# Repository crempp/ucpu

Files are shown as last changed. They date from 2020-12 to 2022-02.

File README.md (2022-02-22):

# uCPU

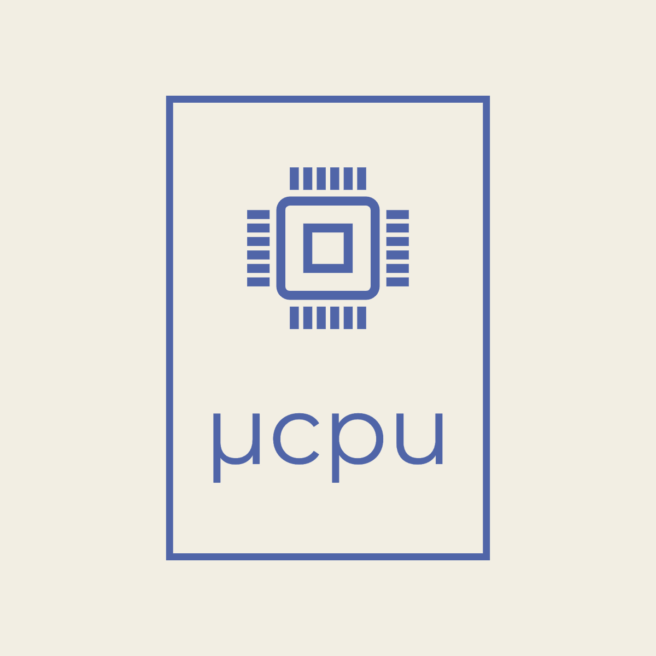
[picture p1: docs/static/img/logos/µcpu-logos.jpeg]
ucpu Logo


This is a 16bit pipelined CPU designed on a breadboard and produced in modular component boards.

My objective in this project is to learn electronics, CPU design and build a fully functional CPU that can be updated, added to and further developed easily.

The CPU is designed around
* four general purpose 16 bit registers
* four 16 bit address registers
* ALU supporting addition, subtraction, shift and bitwise operations
* piplined instructions
* banked memory with a base of 64k, expandable to about 1.5 megabytes (max TBD)

## Documentation

Documentation is located [here](https://crempp.github.io/ucpu)

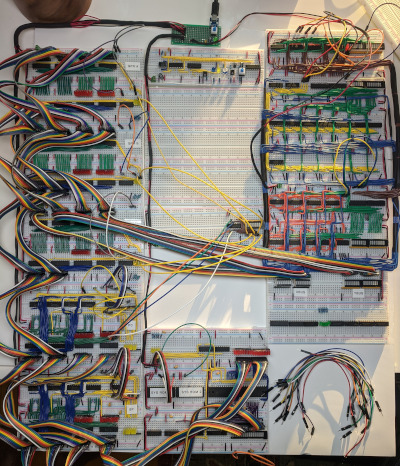
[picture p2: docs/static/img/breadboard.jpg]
Early version of the CPU on breadboards


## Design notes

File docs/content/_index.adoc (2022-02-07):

---
type: docs
draft: false
---

== The µCPU

[.right.text-center]
****
ucpu
****

This is a 16bit pipelined CPU built to be used for experimentation, programming and fun. The CPU is was designed on a breadboard and produced on PCBs in modular architecture utilizing a flexible backplane for expansion and upgrades.

The objective of the µCPU project is to learn electronics, CPU design and build a fully functional CPU that can be updated, added to and further developed easily.

The completed project will include 32 Kb ROM, 32 Kb RAM, a pipelined core, serial port, cartridge support,  VGA compatible video, stereo multi voice sound and more.

== Architecture

[.right.text-center]
****
.Early version of the CPU on breadboards
Early
****

The CPU is being targeted at approximately the PC AT (286) level or Super Nintendo

* Four general purpose 16 bit registers (A, B, C, D)
* Four 16 bit address registers (PC, SP, SI, DI)
* ALU supporting addition, subtraction, shift and bitwise operations
* Pipelined instructions
* Clock runs at 4Mhz
* Banked memory with a base of 32 Kb ROM and 32 Kb RAM, expandable to  304 Kb RAM
* 4 I/O ports for testing and expansion
* Serial port
* 64k Video memory supporting
    * 320×200 in 256 colors
    * 640x350 in 4 (or 16???) colors
* Sprite and effect processing (details TBD)
* Stereo multi-voice sound (details TBD)
* A custom bootable OS
* A BASIC interpreter (ROM)
* Drive support (SD interface to start with)
* Cartridge support (ROMs)

After the CPU is working I may add

* DMA
* ... more?

****
.CPU Architecture
[link=./img/CPUArchitecture.svg,window="_blank"]
CPU Architecture
****

== Schematics

* GPR (rev 1.3) [link:/ucpu/img/schematics/GPRModule.pdf[PDF, window="_blank"]] [link:/ucpu/img/schematics/GPRModule.svg[SVG, window="_blank"]] [link:/ucpu/img/schematics/GPRModule.png[PNG, window="_blank"]]
* Address Register (rev 1.2) [link:/ucpu/img/schematics/AddressRegisterModule.pdf[PDF, window="_blank"]] [link:/ucpu/img/schematics/AddressRegisterModule.svg[SVG, window="_blank"]] [link:/ucpu/img/schematics/AddressRegisterModule.png[PNG, window="_blank"]]
* ALU (rev 1.0) [link:/ucpu/img/schematics/ALUModule.pdf[PDF, window="_blank"]] [link:/ucpu/img/schematics/ALUModule.svg[SVG, window="_blank"]] [link:/ucpu/img/schematics/ALUModule.png[PNG, window="_blank"]]
* Backplane (rev 1.0)[link:/ucpu/img/schematics/Backplane.pdf[PDF, window="_blank"]] [link:/ucpu/img/schematics/Backplane.svg[SVG, window="_blank"]] [link:/ucpu/img/schematics/Backplane.png[PNG, window="_blank"]]
* Memory (rev 1.0)[link:/ucpu/img/schematics/MemoryModule.pdf[PDF, window="_blank"]] [link:/ucpu/img/schematics/MemoryModule.svg[SVG, window="_blank"]] [link:/ucpu/img/schematics/MemoryModule.png[PNG, window="_blank"]]

== BOM

TODO

== Running Documentation

The documentation uses link:https://gohugo.io/[Hugo] as for static site generation.

You'll need go, asciidoctor and hugo
```bash
$ brew install asciidoctor
$ brew install hugo
```

Run

```bash
 $ hugo server --minify
```

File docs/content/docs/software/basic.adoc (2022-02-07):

---
title: "Basic"
date: 2022-02-04T14:46:34-08:00
weight: 2
draft: false
---

== Basic

=== References

* link:http://searle.x10host.com/6502/Simple6502.html[6502 Basic Assembler with source, window="_blank"]

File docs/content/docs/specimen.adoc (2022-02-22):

---
title: "Specimen"
date: 2022-02-04T14:46:34-08:00
weight: 50
draft: true
---
// View this document online at https://asciidoctor.org/docs/asciidoc-writers-guide/
= AsciiDoc Writer's Guide
Dan Allen <https://github.com/mojavelinux[@mojavelinux]>; Sarah White <https://github.com/graphitefriction[@graphitefriction]>
:description: This guide describes the basic structure of an AsciiDoc document, how to create your first AsciiDoc document, how to add other structural elements such as lists, block quotes and source code, and how to convert an AsciiDoc document to HTML, DocBook and PDF.
:keywords: AsciiDoc, Asciidoctor, syntax, reference, learn, how to, writers, authors
:page-description: {description}
:page-keywords: {keywords}
:page-layout: docs
ifndef::env-site[]
:toc: left
:icons: font
:idprefix:
:idseparator: -
:sectanchors:
:source-highlighter: highlightjs
endif::[]
:experimental:
:mdash: &#8212;
:language: asciidoc
:source-language: {language}
:table-caption!:
:example-caption!:
:figure-caption!:
:imagesdir: ../images
// Refs
:url-docs-asciidoc: https://docs.asciidoctor.org/asciidoc/latest/
:url-quickref: {url-docs-asciidoc}syntax-quick-reference/
:user-ref: https://asciidoctor.org/docs/user-manual
:asciidoctor-ref: https://asciidoctor.org/
:asciidoctor-gem-ref: https://rubygems.org/gems/asciidoctor
:uri-install: https://asciidoctor.org/docs/install-toolchain/
:fopub-doc-ref: https://github.com/asciidoctor/asciidoctor-fopub#readme
:docs-ref: https://asciidoctor.org/docs
:gist-ref: https://gist.github.com
:publican-ref: https://fedorahosted.org/publican

This guide provides a gentle introduction to AsciiDoc, a _plain text_ documentation *syntax* and *processor*.
This introduction is intended for anyone who wants to reduce the effort required to write and publish content, whether for technical documentation, articles, web pages or good ol'-fashioned prose.

TIP: If you want to know what AsciiDoc is all about, find the answer in {url-docs-asciidoc}#about-asciidoc[About AsciiDoc].
If you're looking for a concise survey of the AsciiDoc syntax, consult the {url-quickref}[AsciiDoc Syntax Quick Reference].

In this guide, you'll learn:

- The basic structure of an AsciiDoc document
- How to create your first AsciiDoc document
- How to add other structural elements such as lists, block quotes and source code
- How to convert an AsciiDoc document to HTML, DocBook and PDF

In addition to covering the AsciiDoc basics, this guide also suggests a set of conventions to help you create more consistent documents and maximize your writing productivity.

Let's dive in to AsciiDoc!

== Writing in AsciiDoc

The goal of this section is to teach you how to compose your first AsciiDoc document.
Hopefully, when you look back, you'll agree it just makes sense.

Your adventure with AsciiDoc begins in your favorite text editor.

=== It's just text, mate.

Since AsciiDoc syntax is just _plain text_, you can write an AsciiDoc document using _any_ text editor.
You don't need complex word processing programs like Microsoft Word, OpenOffice Writer or Google Docs.
In fact, you _shouldn't_ use these programs because they add cruft to your document (that you can't see) and makes conversion tedious.

TIP: While it's true any text editor will do, I recommend selecting an editor that supports syntax highlighting for AsciiDoc.
The *[red]##c##[green]##o##[purple]##l##[fuchsia]##o##[blue]##r##* brings contrast to the text, making it easier to read.
The highlighting also confirms when you've entered the correct syntax for an inline or block element.

The most popular application for editing plain text on macOS is *TextMate*.
A similar choice on Linux is *GEdit*.
On Windows, stay away from Notepad and Wordpad because they produce plain text which is not cross-platform friendly.
Opt instead for a competent text editor like *Notepad++*.
If you're a programmer (or a writer with an inner geek), you'll likely prefer *Vim*, *Emacs*, or *Sublime Text*, all of which are available cross-platform.
The key feature all these editors share is syntax highlighting for AsciiDoc.

Open up your favorite text editor and get ready to write some AsciiDoc!

=== Content is king!

The bulk of the content in a document is paragraph text.
This is why Asciidoctor doesn't require any special markup or attributes to specify paragraph content.
You can just start typing.

In Asciidoctor, adjacent or consecutive lines of text form a paragraph element.
To start a new paragraph after another element, such as a section title or table, hit the kbd:[RETURN] key twice to insert a blank line, and then continue typing your content.

.Two paragraphs in an AsciiDoc document
[source]
----
This journey begins one late Monday afternoon in Antwerp.
Our team desperately needs coffee, but none of us dare open the office door.

To leave means code dismemberment and certain death.
----

.The two paragraphs rendered using the default (html5) converter and stylesheet (asciidoctor.css)
====
This journey begins one late Monday afternoon in Antwerp.
Our team desperately needs coffee, but none of us dare open the office door.

To leave means code dismemberment and certain death.
====

Just like that, *you're writing in AsciiDoc!*
As you can see, it's just like writing an e-mail.

Save the file with a file extension of `.adoc`.

TIP: If you want to find out how to convert the document to HTML, DocBook or PDF, skip ahead to the section on <<converting-your-document>>.

==== Wrapped text and hard line breaks

Since adjacent lines of text are combined into a single paragraph when Asciidoctor converts a document, that means you can wrap paragraph text or put each sentence or phrase on a separate line.
The line breaks won't appear in the output.

However, if you want the line breaks in a paragraph to be preserved, you can either use a space followed by a plus sign (`{plus}`) or set the `hardbreaks` option on the paragraph.
This results in a visible line break (e.g., `<br>`) following each line.

[source]
.Line breaks preserved using a space followed by the plus sign ({plus})
----
Rubies are red, +
Topazes are blue.
----

====
Rubies are red, +
Topazes are blue.
====

[source]
.Line breaks preserved using the hardbreaks option
----
[%hardbreaks]
Ruby is red.
Java is black.
----

====
[%hardbreaks]
Ruby is red.
Java is black.
====

To preserve line breaks throughout your whole document, add the `hardbreaks` attribute to the document's header.

.Line breaks preserved throughout the document using the hardbreaks attribute
[source]
----
= Line Break Doc Title
:hardbreaks:

Rubies are red,
Topazes are blue.
----

=== Admonitions

There are certain statements you may want to draw attention to by taking them out of the content's flow and labeling them with a priority.
These are called admonitions.
It's rendered style is determined by the assigned label (i.e., value).
Asciidoctor provides five admonition style labels:

* `NOTE`
* `TIP`
* `IMPORTANT`
* `CAUTION`
* `WARNING`

.Caution vs. Warning
[#caution-vs-warning]
****
When choosing the admonition type, you may find yourself getting confused between "caution" and "warning" as these words are often used interchangeably.
Here's a simple rule to help you differentiate the two:

* Use *CAUTION* to advise the reader to _act_ carefully (i.e., exercise care).
* Use *WARNING* to inform the reader of danger, harm, or consequences that exist.

To find a deeper analysis, see https://www.differencebetween.com/difference-between-caution-and-vs-warning/.
****

When you want to call attention to a single paragraph, start the first line of the paragraph with the label you want to use.
The label must be uppercase and followed by a colon (`:`).

.Admonition paragraph syntax
[source]
----
WARNING: Wolpertingers are known to nest in server racks. <1> <2>
Enter at your own risk.
----
<1> The label must be uppercase and immediately followed by a colon (`:`).
<2> Separate the first line of the paragraph from the label by a single space.

.Result: Admonition paragraph
====
WARNING: Wolpertingers are known to nest in server racks.
Enter at your own risk.
====

An admonition paragraph is rendered in a callout box with the admonition label--or its corresponding icon--in the gutter.
Icons are enabled by setting the `icons` attribute on the document.

NOTE: Admonitions can also encapsulate any block content, which we'll cover later.

=== Mild punctuation, strong impact

Just as we emphasize certain words and phrases when we speak, we can emphasize them in text by surrounding them with punctuation.
AsciiDoc refers to this markup as _quoted text_.

==== Quoted text

For instance, in an e-mail, you might "`speak`" a word louder by enclosing it in asterisks.

[source]
I can't believe it, we *won*!

As you would expect, the asterisks make the text *won* bold.
You can almost sense the emotion.
This is one example of quoted (i.e., formatted) text.

NOTE: The term "`quote`" is used liberally here to apply to any symbols that surround text in order to apply emphasis or special meaning.

Here are the forms of quoted text that AsciiDoc recognizes:

.Bold, italic, and monospace formatting syntax
[source]
----
bold *constrained* & **un**constrained

italic _constrained_ & __un__constrained

bold italic *_constrained_* & **__un__**constrained

monospace `constrained` & ``un``constrained

monospace bold `*constrained*` & ``**un**``constrained

monospace italic `_constrained_` & ``__un__``constrained

monospace bold italic `*_constrained_*` & ``**__un__**``constrained
----

When you want to quote text (e.g., place emphasis) somewhere other than at the boundaries of a word, you need to double up the punctuation.

.Result: Bold, italic, and monospace text
====
bold *constrained* & **un**constrained

italic _constrained_ & __un__constrained

bold italic *_constrained_* & **__un__**constrained

monospace `constrained` & ``un``constrained

monospace bold `*constrained*` & ``**un**``constrained

monospace italic `_constrained_` & ``__un__``constrained

monospace bold italic `*_constrained_*` & ``**__un__**``constrained
====

Any quoted text can be prefixed with an attribute list.
The first positional attribute is treated as a role.
The role can be used to apply custom styling to the text.
For instance:

[source]
Type the word [.userinput]#asciidoc# into the search bar.

When converting to HTML, the word "`asciidoc`" is wrapped in `<span>` tags and the role is used as the element's CSS class:

[source,xml]
<span class="userinput">asciidoc</span>

You can apply styles to the text using CSS.

You may not always want these substitutions to take place.
In those cases, you'll need to use markup to escape the text.

==== Preventing substitution

If you are getting quoted text behavior where you don't want it, you can use a backslash or a passthrough macro to prevent it.

Asciidoctor provides several approaches for preventing substitutions.

.Backslash escaping
To prevent punctuation from being interpreted as formatting markup, precede it with a backslash (`\`).
If the formatting punctuation begins with two characters (e.g., `+__+`), you need to precede it with two backslashes (`+\\+`).
This is also how you can prevent character and attribute references from substitution.
When your document is processed, the backslash is removed so it doesn't display in your output.

[source]
----
\*Stars* will appear as *Stars*, not as bold text.

\&sect; will appear as an entity, not the &sect; symbol.

\\__func__ will appear as __func__, not as emphasized text.

\{two-semicolons} will appear {two-semicolons}, not resolved as ;;.
----

Asciidoctor supports several forms of the passthrough macro.

inline pass macro:: An inline macro named `pass` that can be used to passthrough content.
Supports an optional set of substitutions.
+
[source]
----
pass:[content like #{variable} passed directly to the output] followed by normal content.

content with only select substitutions applied: pass:c,a[__<{email}>__]
----

single and double plus:: A special syntax for preventing text from being formatted.
Only escapes special characters for compliance with the output format and doesn't support explicit substitutions.

triple plus:: A special syntax for designating passthrough content.
Does not apply any substitutions (equivalent to the inline pass macro) and doesn't support explicit substitutions.

double dollar (deprecated):: A deprecated special syntax for designating passthrough content.
Like the triple plus, does not apply any substitutions and doesn't support explicit substitutions.

CAUTION: Asciidoctor does not implement the block pass macro.
Instead, you should use a <<pass-blocks,pass block>>.

==== Inline pass macro and explicit substitutions

To exclude a phrase from substitutions and disable escaping of special characters, enclose it in the inline pass macro.
For example, here's one way to format text as underline when generating HTML from AsciiDoc:

[source]
----
The text pass:[<u>underline me</u>] is underlined.
----

====
The text pass:[<u>underline me</u>] is underlined.
====

If you want to enable ad-hoc `quotes` substitution, then assign the `macros` value to `subs` and use the inline pass macro.

------
[subs=+macros] <1>
----
I better not contain *bold* or _italic_ text.
pass:quotes[But I should contain *bold* text.] <2>
----
------
<1> `macros` is assigned to `subs`, which allows any macros within the block to be processed.
<2> The pass macro is assigned the `quotes` value. Text within the square brackets will be formatted.

The inline pass macro does introduce additional markup into the source code that could make it invalid in raw form.
However, the output it produces will be valid when viewed in a viewer (HTML, PDF, etc.).

====
[subs=+macros]
----
I better not contain *bold* or _italic_ text.
pass:quotes[But I should contain *bold* text.]
----
====

The inline pass macro also accepts shorthand values for specifying substitutions.

* `c` = special characters
* `q` = quotes
* `a` = attributes
* `r` = replacements
* `m` = macros
* `p` = post replacements

For example, the quotes text substitution value is assigned in the inline passthrough macro below:

[source]
----
The text pass:q[<u>underline *me*</u>] is underlined and the word "`me`" is bold.
----

====
The text pass:q[<u>underline *me*</u>] is underlined and the word "`me`" is bold.
====

==== Triple plus passthrough

The triple-plus passthrough works much the same way as the pass macro.
To exclude content from substitutions, enclose it in triple pluses (pass:[+++]).

 +++content passed directly to the output+++ followed by normal content.

The triple-plus macro is often used to output custom HTML or XML.

[source]
----
The text +++<u>underline me</u>+++ is underlined.
----

====
The text +++<u>underline me</u>+++ is underlined.
====

.Single plus enclosure

To exclude a phrase from substitutions, enclose it in plus signs (`+`).

[source]
----
This +*literal*+ will appear as *literal*.
----

==== Replacements

AsciiDoc also recognizes textual representations of symbols, arrows and dashes.

[cols="2,^1l,^1l,^1,2"]
.Textual symbol replacements
|===
|Name |Syntax |Unicode Replacement |Rendered |Notes

|Copyright
|(C)
|&#169;
|(C)
|

|Registered
|(R)
|&#174;
|(R)
|

|Trademark
|(TM)
|&#8482;
|(TM)
|

|Em dash
|--
|&#8212;
|{empty}--{empty}
|Only replaced if between two word characters, between a word character and a line boundary, or flanked by spaces.

When flanked by space characters (e.g., `+a -- b+`), the normal spaces are replaced by thin spaces (\&#8201;).

|Ellipsis
|...
|&#8230;
|...
|

|Single right arrow
|->
|&#8594;
|->
|

|Double right arrow
|=>
|&#8658;
|=>
|

|Single left arrow
|<-
|&#8592;
|<-
|

|Double left arrow
|<=
|&#8656;
|<=
|

|Typographic apostrophe
|Sam's
|Sam&#8217;s
|Sam's
|The typewriter apostrophe is replaced with the typographic (aka curly) apostrophe.
|===

This mild punctuation does not take away from the readability of the text.
In fact, you could argue that it makes the text easier to read.
What's important is that these are conventions with which you are likely already familiar.

Punctuation is used in AsciiDoc to create another very common type of element in documents, _lists!_

=== Lists, lists, lists

There are three types of lists supported in AsciiDoc:

. Unordered
. Ordered
. Description

Unordered and ordered lists are structurally very similar.
They consist of items that are prefixed by different types of markers (i.e., bullet).
In contrast, description lists--also called variable, labeled, or term-definition lists--are collections of terms that each have their own supporting content.
Unlike unordered and ordered lists, description lists are rarely nested, though they often contain the former.

Let's explore each type of list, then mix them together.
We'll also look at how to put complex content inside a list item.

==== Lists of things

If you were to create a list in an e-mail, how would you do it?
Chances are, you'd mark list items using the same characters that Asciidoctor uses to find list items.

In the example below, each list item is marked using an asterisk (`{asterisk}`), the AsciiDoc syntax specifying an unordered list item.

[source]
----
* Edgar Allan Poe
* Sheri S. Tepper
* Bill Bryson
----

A list item's first line of text must be offset from the marker (`{asterisk}`) by at least one space.
If you prefer, you can indent list items.
Blank lines are required before and after a list.
Additionally, blank lines are permitted, but not required, between list items.

.Rendered unordered list
====
* Edgar Allan Poe
* Sheri S. Tepper
* Bill Bryson
====

You can add a title to a list by prefixing the title with a period (`.`).

[source]
----
.Kizmet's Favorite Authors
* Edgar Allan Poe
* Sheri S. Tepper
* Bill Bryson
----

.Rendered unordered list with a title
====
.Kizmet's Favorite Authors
* Edgar Allan Poe
* Sheri S. Tepper
* Bill Bryson
====

Was your instinct to use a hyphen (`-`) instead of an asterisk to mark list items?
Guess what?
That works too!

[source]
----
- Edgar Allan Poe
- Sheri S. Tepper
- Bill Bryson
----

You should reserve the hyphen for lists that only have a single level because the hyphen marker (`-`) doesn't work for nested lists.
Now that we've mentioned nested lists, let's go to the next section and learn how to create lists with multiple levels.

[#separating-lists]
.Separating Lists
****
If you have adjacent lists, they have the tendency to want to fuse together.
To force lists apart, insert a line comment (`//`) surrounded by blank lines between the two lists.
Here's an example, where the `-` text in the line comment indicates the line serves as an "`end of list`" marker:

[source]
----
* Apples
* Oranges

//-

* Walnuts
* Almonds
----
****

To nest an item, just add another asterisk (`{asterisk}`) to the marker, and another for each subsequent level.

[source]
----
.Possible DefOps manual locations
* West wood maze
** Maze heart
*** Reflection pool
** Secret exit
* Untracked file in git repository
----

.Rendered nested, unordered list
====
.Possible DefOps manual locations
* West wood maze
** Maze heart
*** Reflection pool
** Secret exit
* Untracked file in git repository
====

In Asciidoctor 1.5.7 and earlier you could only have up to six (6) levels of nesting (assuming one level uses the hyphen marker).

Since Asciidoctor 1.5.8, you can nest unordered lists to any depth.
Keep in mind, however, that some interfaces will begin flattening lists after a certain depth.
GitHub starts flattening list after 10 levels of nesting.

[source]
----
* level 1
** level 2
*** level 3
**** level 4
***** level 5
* level 1
----

====
* level 1
** level 2
*** level 3
**** level 4
***** level 5
* level 1
====

While it would seem as though the number of asterisks represents the nesting level, that's not how depth is determined.
A new level is created for each unique marker encountered.
However, it's much more intuitive to follow the convention that the number of asterisks equals the level of nesting.
After all, we're shooting for plain text markup that is readable _as is_.

==== Ordering the things

Sometimes, we need to number the items in a list.
Instinct might tell you to prefix each item with a number, like in this next list:

[source]
----
1. Protons
2. Electrons
3. Neutrons
----

The above works, but
since the numbering is obvious, the AsciiDoc processor will insert the numbers for you if you omit them:

[source]
----
. Protons
. Electrons
. Neutrons
----

====
. Protons
. Electrons
. Neutrons
====

If you decide to use number for your ordered list, you have to keep them sequential.
This differs from other lightweight markup languages.
It's one way to adjust the numbering offset of a list.
For instance, you can type:

[source]
----
4. Step four
5. Step five
6. Step six
----

However, in general the best practice is to use the `start` attribute to configure this sort of thing:

[source]
----
[start=4]
. Step four
. Step five
. Step six
----

To present the items in reverse order, add the `reversed` option:

[source]
----
[%reversed]
.Parts of an atom
. Protons
. Electrons
. Neutrons
----

====
[%reversed]
.Parts of an atom
. Protons
. Electrons
. Neutrons
====

You can give a list a title by prefixing the line with a dot immediately followed by the text (without leaving any space after the dot).

Here's an example of a list with a title:

[source]
----
.Parts of an atom
. Protons
. Electrons
. Neutrons
----

====
.Parts of an atom
. Protons
. Electrons
. Neutrons
====

You create a nested item by using one or more dots in front of each the item.

[source]
----
. Step 1
. Step 2
.. Step 2a
.. Step 2b
. Step 3
----

AsciiDoc selects a different number scheme for each level of nesting.
Here's how the previous list renders:

.A nested ordered list
====
. Step 1
. Step 2
.. Step 2a
.. Step 2b
. Step 3
====

[TIP]
====
Like with the asterisks in an unordered list, the number of dots in an ordered list doesn't represent the nesting level.
However, it's much more intuitive to follow this convention:

[quote]
# of dots = level of nesting

Again, we are shooting for plain text markup that is readable _as is_.
====

Asciidoctor works hard to infer the relationships between the items that are most intuitive to us humans.
Here's an example of nesting an unordered list inside of an ordered list:

[source]
----
. Linux
* Fedora
* Ubuntu
* Slackware
. BSD
* FreeBSD
* NetBSD
----

====
. Linux
* Fedora
* Ubuntu
* Slackware
. BSD
* FreeBSD
* NetBSD
====

You can spread the items out and indent the nested lists if that makes it more readable for you:

[source]
----
. Linux

  * Fedora
  * Ubuntu
  * Slackware

. BSD

  * FreeBSD
  * NetBSD
----

The following table shows the numbering scheme used by default for each nesting level.

.Ordered list numbering scheme by level
[cols="^2,3,3,4"]
|===
|Level |Numbering Scheme |Examples |CSS class (HTML converter)

|1
|Arabic
|1. 2. 3.
|arabic

|2
|Lower Alpha
|a. b. c.
|loweralpha

|3
|Lower Roman
|i. ii. iii.
|lowerroman

|4
|Upper Alpha
|A. B. C.
|upperalpha

|5
|Upper Roman
|I. II. III.
|upperroman
|===

You can override the number scheme for any level by setting its style (the first positional entry in a block attribute list).
You can also set the starting number using the `start` attribute:

[source]
----
[lowerroman, start=5]
. Five
. Six
[loweralpha]
.. a
.. b
.. c
. Seven
----

==== Description lists

A description list (often abbreviate as dlist) is useful when you need to include a description or supporting text for one or more terms.
Each item in a description list consists of:

* one or more terms
* a separator following each term (typically a double colon, `::`)
* at least one space or endline
* the supporting content (either text, attached blocks, or both)

Here's an example of a description list that identifies parts of a computer:

[source]
----
CPU:: The brain of the computer.
Hard drive:: Permanent storage for operating system and/or user files.
RAM:: Temporarily stores information the CPU uses during operation.
Keyboard:: Used to enter text or control items on the screen.
Mouse:: Used to point to and select items on your computer screen.
Monitor:: Displays information in visual form using text and graphics.
----

By default, the content of each item is displayed below the description when rendered.
Here's a preview of how this list is rendered:

.A basic description list
====
CPU:: The brain of the computer.
Hard drive:: Permanent storage for operating system and/or user files.
RAM:: Temporarily stores information the CPU uses during operation.
Keyboard:: Used to enter text or control items on the screen.
Mouse:: Used to point to and select items on your computer screen.
Monitor:: Displays information in visual form using text and graphics.
====

If you want the description and content to appear on the same line, add the horizontal style to the list.

[source]
----
[horizontal]
CPU:: The brain of the computer.
Hard drive:: Permanent storage for operating system and/or user files.
RAM:: Temporarily stores information the CPU uses during operation.
----

====
[horizontal]
CPU:: The brain of the computer.
Hard drive:: Permanent storage for operating system and/or user files.
RAM:: Temporarily stores information the CPU uses during operation.
====

The content of a description list can be any AsciiDoc element.
For instance, we could rewrite the grocery list from above so that each aisle is a description rather than a parent outline list item.

[source]
----
Dairy::
* Milk
* Eggs
Bakery::
* Bread
Produce::
* Bananas
----

====
Dairy::
* Milk
* Eggs
Bakery::
* Bread
Produce::
* Bananas
====

Description lists are quite lenient about whitespace, so you can spread the items out and even indent the content if that makes it more readable for you:

[source]
----
Dairy::

  * Milk
  * Eggs

Bakery::

  * Bread

Produce::

  * Bananas
----

==== Hybrid lists

[#three-hybrid]
Finally, you can mix and match the three list types within a single hybrid list.
Asciidoctor works hard to infer the relationships between the items that are most intuitive to us humans.

Here's a list that mixes description, ordered, and unordered list items:

[source]
----
Operating Systems::
  Linux:::
    . Fedora
      * Desktop
    . Ubuntu
      * Desktop
      * Server
  BSD:::
    . FreeBSD
    . NetBSD

Cloud Providers::
  PaaS:::
    . OpenShift
    . CloudBees
  IaaS:::
    . Amazon EC2
    . Rackspace
----

Here's how the list is rendered:

.A hybrid list
====
Operating Systems::
Linux:::
. Fedora
* Desktop
. Ubuntu
* Desktop
* Server
BSD:::
. FreeBSD
. NetBSD

Cloud Providers::
PaaS:::
. OpenShift
. CloudBees
IaaS:::
. Amazon EC2
. Rackspace
====

You can include more complex content in a list item as well.

=== Links and images

AsciiDoc makes it easy to include links, images and other types of media in a document.

==== External links

There's nothing you have to do to make a link to a URL.
Just include the URL in the document and AsciiDoc will turn it into a link.

Asciidoctor recognizes the following common schemes without the help of any markup.

[#schemes]
* http
* https
* ftp
* irc
* mailto
* \email@email.com

You can think of these like implicit macro names (the bare email address being a special case).
Since the URL in the example below begins with a protocol (in this case _https_ followed by a colon), Asciidoctor will automatically turn it into a hyperlink when it is processed.

[source]
----
The homepage for the Asciidoctor Project is https://asciidoctor.org. <1>
----
<1> The trailing period will not get caught up in the link.

To prevent automatic linking of an URL, prepend it with a backslash (`\`).

[source]
----
Once launched, the site will be available at \https://example.org.
----

If you prefer URLs to be shown with the scheme hidden, set the `hide-uri-scheme` attribute in the document's header.

[source]
----
:hide-uri-scheme:

https://asciidoctor.org
----

When the hide-uri-scheme attribute is set, the above URL will render as follows:

[source,xml]
----
<a href="https://asciidoctor.org">asciidoctor.org</a>
----

Note the absence of _https_ inside the `<a>` element.

To attach a URL to text, enclose the text in square brackets at the end of the URL, thus making it an URL macro:

[source]
----
Chat with other Fedora users in the irc://irc.freenode.org/#fedora[Fedora IRC channel].
----

When a URL does not start with one of the <<schemes,common schemes>>, or the URL is not surrounded by word boundaries, you must use the `link` macro.
The `link` macro is a stronger version of a URI macro, which you can think of like an unconstrained macro.
The URL is preceded by `link:` and followed by square brackets.
The square brackets may include optional link text.
The URL is used for the text of the link if link text is not specified.
Prior to 1.5.7, if the `linkattrs` document attribute is set, the text in square brackets is parsed as attributes, which allows a window name or role to be specified.
Since 1.5.7, attributes are parsed automatically if an equal sign is found after a comma (e.g., `[link text,window=_blank]`).

.Anatomy of a link macro
[source]
----
link:url[optional link text, optional target attribute, optional role attribute]
----

Let's consider a case where we need to use the link macro (instead of just a URI macro) to expand a link when it's not adjacent to a word boundary (i.e., unconstrained).

[source]
----
search/link:https://ecosia.org[Ecosia]
----

====
search/link:https://ecosia.org[Ecosia]
====

If we didn't use the `link:` prefix in this case, the URL macro would not be detected by the parser.

==== Target window and role attributes for links

[#link-macro-attributes]
Prior to 1.5.7, Asciidoctor _does not_ parse attributes in the link macro by default.
If you want attributes in the link macro to be parsed, you must set the `linkattrs` document attribute in the header.
Since 1.5.7, this parsing is automatic (and the attribute is not required) if an equal sign is found after a comma.
When attribute parsing is enabled, you can then specify the name of the target window using the `window` attribute.

[source]
----
= Asciidoctor Document Title

Let's view the raw HTML of the link:view-source:asciidoctor.org[Asciidoctor homepage,window=_blank].
----

====
Let's view the raw HTML of the link:view-source:asciidoctor.org[Asciidoctor homepage,window=_blank].
====

Since `_blank` is the most common window name, we've introduced shorthand for it.
Just end the link text with a caret (`+^+`):

[source]
----
Let's view the raw HTML of the link:view-source:asciidoctor.org[Asciidoctor homepage^].
----

CAUTION: If you use the caret syntax more than once in a single paragraph, you may need to escape the first occurrence with a backslash.

When attribute parsing is enabled, you can add a role (i.e., CSS class) to the link.

[source]
----
Chat with other Asciidoctor users on the https://discuss.asciidoctor.org/[*mailing list*^,role=green].
----

====
Chat with other Asciidoctor users on the https://discuss.asciidoctor.org/[*mailing list*^,role=green].
====

TIP: Links with attributes (including the subject and body segments on mailto links) are a feature unique to Asciidoctor.
When they're enabled, you must surround the link text in double quotes if it contains a comma.

==== Links to relative files

If you want to link to an external file relative to the current document, use the `link` macro in front of the file name.

[source]
----
link:protocol.json[Open the JSON file]
----

If your file is an HTML file, you can link directly to a section in the document, append a hash (`#`) followed by the section's ID to the end of the file name.

[source]
----
link:external.html#livereload[LiveReload]
----

For links to relative AsciiDoc documents cross references should be used.

[reftext="Internal Cross References"]
==== Cross references

A link to another location within an AsciiDoc document or between AsciiDoc documents is called a _cross reference_ (also referred to as an _xref_).

In Asciidoctor, the inline xref macro is used to create cross references (also called in-text or page citations) to content elements (sections, blocks, or phrases) that have an ID (regardless of whether that ID is explicit or auto-generated).

You create a cross reference by enclosing the ID of the target block or section (or the path of another document with an optional anchor) in double angled brackets.

.Cross reference using the ID of the target section
[source]
----
The section <<images>> describes how to insert images into your document.
----

.Rendered cross reference using the ID of the target section
====
The section <<images>> describes how to insert images into your document.
====

You can also link to a block or section using the title by referencing its title, referred to as a [.term]_natural cross reference_.
The title must contain at least one space character or contain at least one uppercase letter.
(If you are using Ruby < 2.4, that uppercase letter is restricted to the basic Latin charset).

.Cross reference using a section's title
[source]
----
Refer to <<Internal Cross References>>.
----

.Rendered cross reference using a section's title
====
Refer to <<Internal Cross References>>.
====

Converters usually use the reftext of the target as the default text of the link.
When the document is parsed, attribute references in the reftext are substituted immediately.
When the reftext is displayed, additional reftext substitutions are applied to the text (specialchars, quotes, and replacements).

You can override the reftext of the target by specifying alternative text at the location of the cross reference.
After the ID, add a comma and then enter the custom text you want the cross reference to display.

.Cross reference with custom xreflabel text
[source]
----
Learn how to <<link-macro-attributes,use attributes within the link macro>>.
----

.Rendered cross reference using custom xreflabel text
====
Learn how to <<link-macro-attributes,use attributes within the link macro>>.
====

You can also use the inline xref macro as an alternative to the double angled bracket form.

.Inline xref macro
[source]
----
Learn how to xref:link-macro-attributes[use attributes within the link macro].
----

Cross references can also be used to create a link to a file relative to the current document.
For links to another AsciiDoc document, this is the preferred way.

The trailing hash (`#`) means that you refer to the top of the document.

.Cross reference to the top of a relative AsciiDoc document
[source]
----
Refer to <<document-b.adoc#,Document B>> for more information.
----

.Converted HTML for cross reference to relative AsciiDoc document
[source,html]
----
Refer to <a href="document-b.html">Document B</a> for more information.
----

To link directly to a section in the document, append the section's ID after the hash (`#`).

.Cross reference to a specific section of a relative AsciiDoc document
[source]
----
Refer to <<document-b.adoc#section-b,Section B>> for more information.
----

.Converted HTML for cross reference to section of a relative AsciiDoc document
[source,html]
----
Refer to <a href="document-b.html#section-b">Section B</a> for more information.
----

In both cases, this syntax will also work if you are inside the document you are referring to.
This is useful if you are sharing the same link across multiple documents.

In the link that is created from the inter-document cross reference, the source file extension is replaced with the value of the `outfilesuffix` attribute.
To customize the file extension used in the target of the link, simply change the value of this attribute.

Image references are similar to links since they are also references to URLs or files.
The difference, of course, is that they display the image in the document.

==== Images

To include an image on its own line (i.e., a _block image_), use the `image::` prefix in front of the file name and square brackets after it:

[source]
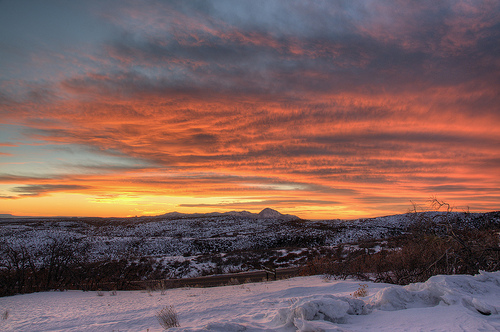
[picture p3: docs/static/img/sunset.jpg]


If you want to specify alt text, include it inside the square brackets:

[source]
Sunset

You can also give the image an id, a title (i.e., caption), set its dimensions (i.e., width and height) and make it a link:

[source]
----
[#img-sunset]
.A mountain sunset
[link=https://www.flickr.com/photos/javh/5448336655]
Sunset
----

The title of a block image is displayed underneath the image when rendered.
Here's a preview:

.A hyperlinked image with caption
====
[#img-sunset]
.A mountain sunset
[link=https://www.flickr.com/photos/javh/5448336655]
Sunset
====

IMPORTANT: Images are resolved relative to the value of the `imagesdir` document attribute, which defaults to an empty value.
The `imagesdir` attribute can be an absolute path, relative path or base URL.
If the image target is a URL or an absolute path, the `imagesdir` prefix is _not_ added.

TIP: You should use the `imagesdir` attribute to avoid hard coding the shared path to your images in every image macro.

If you want to include an image inline, use the `image:` prefix instead (notice there is only one colon):

[source]
Press the Save button.

For inline images, the optional title is displayed as a tooltip.

If paragraphs and lists are the meat of the document, then titles and sections are its bones.
Let's explore how to give structure to our document.

=== Titles, titles, titles

AsciiDoc supports three types of titles:

. Document title
. Section title
. Block title

All titles are optional in AsciiDoc.
This section will define each title type and explain how and when to use them.

==== Document title

Just as every e-mail has a subject, every document (typically) has a title.
The title goes at the top of an AsciiDoc document.

TIP: A document title is an _optional_ feature of an AsciiDoc document.

To create a document title, begin the first line of the document with one equal sign followed by at least one space (``= ``), then the text of the title.
This syntax is the simplest (and thus recommended) way to declare a document title.

Here's an example of a document title followed by an abbreviated paragraph:

[source]
----
= Lightweight Markup Languages

According to Wikipedia...
----

The document title is part of the document header.
So, what else can go in the header?
Good question.

===== The document header

Notice the blank line between the title line and the first line of content in the previous example.
This blank line separates the document header from the document body (in this case a paragraph).
The document title is part of the document header.
In all, the document header contains the title, author, revision information and document-wide attributes.

CAUTION: If the title line is not offset by a blank line, it gets interpreted as a section title, which we'll discuss later.

Your document now has a title, but what about an author?
Just as every e-mail has a sender, every document must surely have an author.
Let's see how to add additional information to the header, including an author.

There are two optional lines of text you can add immediately below the document title for defining common document attributes:

Line 1:: Author name and an optional e-mail address
Line 2:: An optional revision, a date and an optional remark

Let's add these lines to our document:

[source]
----
= Lightweight Markup Languages
Doc Writer <doc.writer@asciidoc.org>
v1.0, 2012-01-01

According to Wikipedia...
----

The header now contains a document title, an author, a revision number, and a date.
This information will typically be displayed as a formatted header at the top of the output document.

NOTE: The header, including the document title, is _not required_.
If absent, the AsciiDoc processor will happily convert whatever content is present.
The header is only used when generating a full document.
It's excluded from the output of an embedded document.

The document header can also be used to define attributes.

==== Document attributes

Attributes are one of the features that sets AsciiDoc apart from other lightweight markup languages.
You can use attributes to toggle features or to store reusable or replacement content.

Most often, attributes are defined in the document header.
There are scenarios where they can be defined inline, but we'll focus on the more common usage.

An attribute entry consists of a name surrounded by colons at the beginning of the line followed by at least one space, then the content.
The content is optional.

Here's an example of an attribute that holds the version of an application:

[source]
----
= User Guide
Doc Writer <doc.writer@asciidoc.org>
2012-01-01
:appversion: 1.0.0
----

IMPORTANT: There should be no blank lines between the first attribute entry and the rest of the header.

Now you can refer to this attribute anywhere in the document (where attribute substitution is performed) by surrounding the name in curly braces:

[source]
The current version of the application is {appversion}.

Attributes are also commonly used to store URLs, which can get quite lengthy.
Here's an example:

[source]
----
:fedpkg: https://apps.fedoraproject.org/packages/rubygem-asciidoctor
----

Here's the attribute in use:

[source]
Information about the Asciidoctor package for Fedora can found at {fedpkg}.

Document attributes can also be used to toggle settings or set configuration variables that control the output generated by the AsciiDoc processor.

For example, to include a table of contents in your document, you can define the `toc` attribute:

[source]
----
:toc:
----

To undefine an attribute, place a `!` at the end of the name:

[source]
----
:linkcss!:
----

You can also set the base path to images (default: _empty_), icons (default: `./images/icons`), stylesheets (default: `./stylesheets`) and JavaScript files (default: `./javascripts`):

[source]
----
:imagesdir: ./images
:iconsdir: ./icons
:stylesdir: ./styles
:scriptsdir: ./js
----

TIP: Attribute values can also be set and overridden when invoking the AsciiDoc processor.
We'll explore that feature later.

When you find yourself typing the same text repeatedly, or text that often needs to be updated, consider assigning it to a document attribute and use that instead.

As your document grows, you'll want to break the content into sections, like in this guide.
That's accomplished using section titles.

==== Section titles

Sections partition the document into a content hierarchy.
In AsciiDoc, sections are defined using section titles.

A section title uses the same syntax as a document title, except the line may begin with two to six equal signs instead of just a single equal sign.
The number of equal signs represents the nesting level (using a 0-based index).

Here are all the section levels permitted in an AsciiDoc document (for an article doctype, the default), shown below the document title:

[source]
----
= Document Title (Level 0)

== Level 1 Section

=== Level 2 Section

==== Level 3 Section

===== Level 4 Section

====== Level 5 Section

== Another Level 1 Section
----

NOTE: When the document is converted to HTML 5 (using the built-in `html5` backend), each section title becomes a heading element where the heading level matches the number of equal signs.
For example, a level 1 section (2 equal signs) maps to an `<h2>` element.

Section levels cannot be chosen arbitrarily.
There are two rules you must follow:

. A document can only have multiple level 0 sections if the `doctype` is set to `book`.footnote:[The default doctype is `article`, which only allows one level 0 section (i.e., the document title).]
. Section levels cannot be skipped when nesting sections

For example, the following syntax is illegal:

[source]
----
= Document Title

= Illegal Level 0 Section (violates rule #1)

== First Section

==== Illegal Nested Section (violates rule #2)
----

Content above the first section (after the document title) is part of the preamble.
Once the first section is reached, content is associated with the section that precedes it:

[source]
----
== First Section

Content of first section

=== Nested Section

Content of nested section

== Second Section

Content of second section
----

TIP: In addition to the equals marker used for defining single-line section titles, Asciidoctor recognizes the hash symbol (`#`) from Markdown.
That means the outline of a Markdown document will convert just fine as an AsciiDoc document.

To have the processor auto-number the sections, define the `sectnums` attribute in the document header:

[source]
----
:sectnums:
----

You can also use this attribute entry above any section title in the document to toggle the auto-numbering setting.
When you want to turn off the numbering, add an exclamation point to the end of the attribute name:

[source]
----
:sectnums!:

== Unnumbered Section
----

===== Preamble

Content between the document title and the first section is called the preamble.
If a document title is not present, this content is not wrapped in a preamble section.

[source]
----
= Document Title

preamble

another preamble paragraph

== First Section
----

TIP: When using the default Asciidoctor stylesheet, this preamble is rendered in the style of a lead (i.e., larger font).

You can also assign titles to individual elements.

==== Block titles

You can assign a title to any paragraph, list or delimited block element.
The title is used as the element's caption.
In most cases, the title is displayed immediately above the content.
If the content is a figure or image, the title is displayed below the content.

A block title is defined on a line above the element.
The line must begin with a dot (`.`) and be followed immediately by the title text with no spaces in between.

Here's an example of a list with a title:

[source]
----
.TODO list
- Learn the AsciiDoc syntax
- Install AsciiDoc
- Write my document in AsciiDoc
----

Speaking of block titles, let's dig into blocks and discover which types of blocks AsciiDoc supports.

== Building blocks in AsciiDoc

AsciiDoc provides a nice set of components for including non-paragraph text--such as block quotes, source code listings, sidebars and tables--in your document.
These components are referred to as _delimited blocks_ because they are surrounded by delimiter lines.

=== Delimited blocks

You've already seen many examples of the listing block (i.e., code block), which is surrounded by lines with four or more hyphens.

[source]
....
----
This is an example of a _listing block_.
The content inside is displayed as <pre> text.
----
....

Within the boundaries of a delimited block, you can enter any content or blank lines.
The block doesn't end until the ending delimiter is found.
The delimiters around the block determine the type of block, how the content is processed and converted and what elements are used to wrap the content in the output.

Here's how the block above appears when converted to HTML and viewed in a browser:

....
This is an example of a _listing block_.
The content inside is displayed as <pre> text.
....

Here's the HTML source that is generated:

[source,html]
----
<div class="listingblock">
  <div class="content monospaced">
    <pre>This is an example of a _listing block_.
The content inside is displayed as &lt;pre&gt; text.</pre>
  </div>
</div>
----

You should notice a few things about how the content is processed:

* the HTML tag `<pre>` is escaped
* the endlines are preserved
* the phrase "`listing block`" is not italicized, despite having underscores around it.

Each type of block is processed according to its purpose.
Literal blocks don't receive the full set of substitutions normally applied to a paragraph.
Since a listing block is typically used for source code, substitutions are not desirable.

The following table identifies the delimited blocks that AsciiDoc provides by default, their purpose and what substitutions are performed on its content.

[cols="1,1l,1,1"]
|===
|Name (Style) |Line delimiter |Purpose |Substitutions

|comment
|////
|Private notes that are not displayed in the output
|none

|example
|====
|Designates example content or defines an admonition block
|normal

|literal
|....
|Output text to be displayed exactly as entered
|verbatim

|listing, source
|----
|Source code or keyboard input to be displayed as entered
|verbatim

|open
|--
|Anonymous block that can act as any other block (except _pass_ or _table_)
|varies

|pass
|++++
|Raw text to be passed through unprocessed
|none

|quote, verse
|____
|A quotation or verse with optional attribution
|normal

|sidebar
|****
|Aside text displayed outside the flow of the document
|normal

|table
|\|===
|Used to display tabular content or advanced layouts
|varies
|===

IMPORTANT: AsciiDoc allows delimited lines to be longer than 4 characters.
*Don't do it.*
Maintaining long delimiter lines is a _colossal_ waste of time, not to mention arbitrary and error prone.
Use the minimum line length required to create a delimited block and _move on_ to drafting the content.
The reader will never see the long delimiters anyway since they are not carried over to the output.

This table shows the substitutions performed by each substitution group referenced in the previous table.

|===
|Group / Substitution |Normal |Verbatim |None

h|Special chars
|Yes
|Yes
|No

h|Callouts
|No
|Yes
|No

h|Quotes
|Yes
|No
|No

h|Attributes
|Yes
|No
|No

h|Replacements
|Yes
|No
|No

h|Macros
|Yes
|No
|No

h|Post replacements
|Yes
|No
|No
|===

In order to apply normal substitutions to an attribute value, surround it with single quotes.
There are two exceptions to this behavior: At the moment normal substitutions are not applied to
the `options` and `title` attribute values.

You can control how blocks are displayed using block metadata.

=== Block metadata

Metadata can be assigned to any block.
There are several types of metadata:

* Title
* Id (i.e., anchor)
* Style (first unnamed block attribute)
* Named block attributes

Here's an example of a quote block that includes all types of metadata:

[source]
----
.Gettysburg Address
[[gettysburg]]
[quote, Abraham Lincoln, Address delivered at the dedication of the Cemetery at Gettysburg]
____
Four score and seven years ago our fathers brought forth
on this continent a new nation...

Now we are engaged in a great civil war, testing whether
that nation, or any nation so conceived and so dedicated,
can long endure. ...
____
----

Here's the metadata extracted from this block:

Title:: Gettysburg Address
Id:: gettysburg
Style:: quote
Named block attributes::
  attribution::: Abraham Lincoln
  citetitle::: Address delivered at the dedication of the Cemetery at Gettysburg

TIP: A block can have multiple block attribute lines.
The attributes will be aggregated.
If there is a name conflict, the last attribute defined wins.

Some metadata is used as supplementary content, such as the title, whereas other metadata, such as the style, controls how the block is converted.

=== Masquerading blocks

Some blocks can masquerade as other blocks, a feature which is controlled by the block style.
The block style is the first positional attribute in the block attribute list.

==== Admonition blocks

For instance, an example block can act as an admonition block:

[source]
----
[NOTE]
====
This is an example of an admonition block.

Unlike an admonition paragraph, it may contain any AsciiDoc content.
The style can be any one of the admonition labels:

* NOTE
* TIP
* WARNING
* CAUTION
* IMPORTANT
====
----

==== Listing and source code blocks

At the start of this tutorial, remember how painful we said it is to insert source code into a document using a traditional word processor.
They just aren't designed for that use case.
*AsciiDoc is!*

In fact, inserting source code in an AsciiDoc is incredibly easy.
Just shove the raw code into a listing block.

[source]
....
----
require 'asciidoctor'

puts Asciidoctor.convert_file 'mysample.adoc', to_file: false
----
....

To enable syntax highlighting in the output, set the style on the block to `source` and specify the source language in the second attribute position.

[source]
....
[source,ruby]
----
require 'asciidoctor'

puts Asciidoctor.convert_file 'mysample.adoc', to_file: false
----
....

You can even use source code that's in a separate file.
Just use the AsciiDoc include directive:

[source]
....
[source,ruby]
----
\include::example.rb[]
----
....

To really show how well-suited AsciiDoc is for technical documentation, it also supports callouts in source code.
Code callouts are used to explain lines of source code.
The explanations are specified below the listing and keyed by number.
Here's an example:

[source]
....
[source,ruby]
----
require 'asciidoctor'  # \<1>

Asciidoctor.convert_file 'mysample.adoc'  # \<2>
----
<1> Imports the library
<2> Reads, parses, and converts the file
....

Here's how the callouts appear when rendered:

[#eg-callouts]
.Source code with callouts
====
[source,ruby]
----
require 'asciidoctor'  # <1>

puts Asciidoctor.convert_file 'mysample.adoc'  # <2>
----
<1> Imports the library
<2> Reads, parses, and converts the file
====

==== Open blocks

The most versatile block of all is the open block.
An open block can act as any other block, with the exception of _pass_ and _table_.
Here's an example of an open block acting as a sidebar:

[source]
----
[sidebar]
.Related information
--
This is aside text.

It is used to present information related to the main content.
--
----

[#pass-blocks]
==== Passthrough blocks

The "`anything goes`" mechanism in AsciiDoc is the passthrough block.
As the name implies, this block passes the content of the block directly through to the output document.
When you've encountered a complex requirement that you cannot meet using the AsciiDoc syntax, a passthrough block can come in very handy.

For example, let's say you want to embed a GitHub gist into your document.
You can define the following passthrough block:

[source]
----
++++
<script src="https://gist.github.com/piscisaureus/3342247.js"></script>
++++
----

////
[source]
----
++++
<video poster="images/movie-reel.png">
  <source src="videos/writing-zen.webm" type="video/webm">
</video>
++++
----
////

CAUTION: Using a passthrough block couples your content to a specific output format, such as HTML.
If you're going to use a passthrough block, we recommend using {user-ref}#conditional-preprocessor-directives[conditional preprocessor directives] to associate the format-specific content with each backend you intend to support.

//The block style can be used in the absense of block delimiters to promote a paragraph to a block element.

=== Delimiters optional

If the content is contiguous (not interrupted by blank lines), you can forgo the use of the block delimiters and instead use the block style above a paragraph to repurpose it as one of the delimited block types.

This format is often used for single-line listings:

[source]
----
[listing]
sudo dnf install asciidoc
----

or single-line quotes:

[source]
----
[quote]
Never do today what you can put off 'til tomorrow.
----

While most blocks are linear, tables give you the ability to layout content horizontally as well.

=== A new perspective on tables

Tables are one of the most refined areas of the AsciiDoc syntax.
They are easy to create, easy to read in raw form and also remarkably sophisticated.
I recommend that you use tables sparingly because they interrupt the conversation with your readers.
When they are the most suitable way to present the information, know that you've got a powerful tool in your hands.

You can think of a table as a delimited block that contains one or more bulleted lists.
The list marker is a vertical bar (`|`).
Each list represents one row in the table and must share the same number of items (taking into account any column or row spans).

Here's a simple example of a table with two columns and three rows:

[source]
----
[cols=2*]
|===
|Firefox
|Web Browser

|Ruby
|Programming Language

|TorqueBox
|Application Server
|===
----

The first non-blank line inside the block delimiter (`|===`) determines the number of columns.
Since we are putting each column title on a separate line, we have to use the `cols` block attribute to explicitly state that this table has two columns.
The `*` is the repeat operator.
It means to repeat the column specification for the remainder of columns.
In this case, it means to repeat no special formatting (since none is present) across 2 columns.

We can make the first row of the table the header by setting the `header` option on the table.

[source]
----
[cols=2*,options=header]
|===
|Name
|Group

|Firefox
|Web Browser

|Ruby
|Programming Language

...
|===
----

You can also define the `header` option using the following shorthand:

```
[%header,cols=2*]
```

Alternatively, we could define the header row on a single line offset from the body rows by a blank line, so neither the `cols` nor the `options` attributes are required.

[source]
----
|===
|Name |Group

|Firefox
|Web Browser

...
|===
----

The content of each item (i.e., cell) can span multiple lines, as is the case with other lists in AsciiDoc.
Unlike other lists, the content of each cell may contain blank lines without the need for a list continuation to hold them together.
A new cell begins when another non-escaped vertical bar (`|`) is encountered.

[source]
----
|===
|Name |Group |Description

|Firefox
|Web Browser
|Mozilla Firefox is an open-source web browser.
It's designed for standards compliance,
performance, portability.

|Ruby
|Programming Language
|A programmer's best friend.

...
|===
----

You can set the relative widths of each column using _column specifiers_{mdash}a comma-separated list of relative values defined in the `cols` block attribute.
The number of entries in the list determines the number of columns.

[source]
----
[cols="2,3,5"]
|===
|Name |Group |Description

|Firefox
|Web Browser
|Mozilla Firefox is an open-source web browser.
It's designed for standards compliance,
performance and portability.

|Ruby
|Programming Language
|A programmer's best friend.

...
|===
----

If you want to include blocks or lists inside the contents of a column, you can put an `a` (for AsciiDoc) at the end of the column's relative value.

[source]
----
[cols="2,3,5a"]
|===
|Name |Group |Description

|Firefox
|Web Browser
|Mozilla Firefox is an open-source web browser.
It's designed for:

* standards compliance,
* performance and
* portability.

|Ruby
|Programming Language
|A programmer's best friend.

...
|===
----

Alternatively, you can apply the AsciiDoc style to an individual cell by prefixing the vertical bar with an `a`:

[source]
----
a|Mozilla Firefox is an open-source web browser.
It's designed for:

* standards compliance,
* performance and
* portability.
----

There's a whole collection of column and cell specifiers you can use to format the contents of the table, including styling and alignment.

AsciiDoc tables can also be created directly from CSV data.
Just set the `format` block attribute to `csv` and insert CSV data inside the block delimiters, either directly:

[source]
----
[%header,format=csv]
|===
Artist,Track,Genre
Baauer,Harlem Shake,Hip Hop
The Lumineers,Ho Hey,Folk Rock
|===
----

or using an `include::[]` directive:

[source]
----
[%header,format=csv]
|===
\include::tracks.csv[]
|===
----

Asciidoctor 0.1.3 also recognizes shorthand notation for setting CSV and DSV table formats.
The first position of the table block delimiter (i.e., `|===`) can be replaced by a data delimiter to set the table format accordingly.

Instead of specifying the `csv` format using an attribute, you can simply replace the leading pipe (`|`) with a comma (`,`).

//[source]
----
,===
a,b,c
,===
----

In the same way, the `dsv` format can be specified by replacing the leading pipe (`|`) with a colon (`:`).

//[source]
----
:===
a:b:c
:===
----

That's a pretty powerful option.

== What else can AsciiDoc do?

We've covered many of the features of the AsciiDoc syntax, but it still has much more depth.
AsciiDoc is simple enough for a README, yet can scale to meet the requirements of a publisher.

Here are some of the features that the AsciiDoc syntax supports:

* footnotes
* indexes
* appendix, preface, dedication, partintro
* multi-line attributes
* preprocessor directive (conditional markup)
* mathematical formulas
* musical notation
* diagrams
* block filters
* themes
* custom blocks, macros and output formats

Consult the {user-ref}[Asciidoctor User Manual] to continue exploring the syntax and processor capabilities.

That's enough syntax for now.
You've created your first AsciiDoc document.
Now it's time to convert the document into a presentable format.
This will give you a real appreciation for the power that AsciiDoc puts in your hands.

== Converting your document

While AsciiDoc syntax is designed to be readable in raw form, the intended audience for that format are writers and editors.
Readers aren't going to appreciate the raw text nearly as much.
Aesthetics matter.
You'll want to apply nice typography with font sizes that adhere to the "`golden ratio`", colors, icons and images to give it the respect it deserves.
That's where the Asciidoctor processor comes in (*after* you have done the writing).

The Asciidoctor processor parses the document and translates it into a backend format, such as HTML, ePub, DocBook or PDF.
Asciidoctor ships with a set of default templates in the tin, but you can customize the templates or create your own to get exactly the output you want.

Before you can use the Asciidoctor processor, you have to install the {asciidoctor-gem-ref}[Asciidoctor Ruby Gem].
Review the {uri-install}[Asciidoctor Installation Guide] if you need help to install the gem.

=== Converting a document to HTML 5

Asciidoctor provides both a command line tool and a Ruby API for converting AsciiDoc documents to HTML 5, Docbook 5.0 and custom output formats.

To use Asciidoctor to generate an HTML document, type `asciidoctor` followed by your document's name on the command line.

 $ asciidoctor mysample.adoc

In Asciidoctor, the *html5* backend is the default, so there's no need to specify a backend explicitly to generate an HTML 5 document.

Asciidoctor also provides a Ruby API, so you can generate an HTML document directly from a Ruby application:

[source,ruby]
----
require 'asciidoctor'

Asciidoctor.convert_file 'mysample.adoc'
----

Alternatively, you can capture the HTML output into a variable instead of writing it to a file:

[source,ruby]
----
html = Asciidoctor.convert_file 'mysample.adoc', to_file: false, header_footer: true
puts html
----

To generate DocBook, just specify the backend option:

[source,ruby]
----
Asciidoctor.convert_file 'mysample.adoc', backend: 'docbook'
----

One of the strengths of Asciidoctor is that it can output to a variety of formats, not just HTML.

=== Converting a document to DocBook

Despite the fact that writing in DocBook is inhumane, it's useful as a portable document format.
Since AsciiDoc syntax was designed with DocBook output in mind, the conversion is very good.
There's a corresponding DocBook element for each markup in the AsciiDoc syntax.

Asciidoctor provides a Docbook 5.0 backend out of the box.
To convert the document to Docbook 5.0, call the processor with the backend flag set to `docbook5`:

 $ asciidoctor -b docbook5 mysample.adoc

A new XML document, named `mysample.xml`, will now be present in the current directory:

 $ ls -1
 mysample.adoc
 mysample.html
 mysample.xml

If you're on Linux, you can view the DocBook file using Yelp:

 $ yelp mysample.xml

DocBook is only an intermediary format in the Asciidoctor toolchain.
You'll either feed it into a system that processes DocBook (like {publican-ref}[publican]), or you can convert it to PDF using the {fopub-doc-ref}[asciidoctor-fopub tool].

=== Output galore

There's really no end to the customization you can do to the output the Asciidoctor processor generates.
We've just scratched the surface here.

Check out the {user-ref}[Asciidoctor User Manual] and the {docs-ref}[Asciidoctor Docs Page] to learn more.

=== Where else is AsciiDoc supported?

The easiest way to experiment with AsciiDoc is online.
AsciiDoc document in a GitHub repository or a {gist-ref}[gist] is automatically converted to HTML and rendered in the web interface.

If you have a project on GitHub, you can write the README or any other documentation in AsciiDoc and the GitHub interface will show the HTML output for visitors to view.

// image?

Gists, in particular, are a great way to experiment with AsciiDoc.
Just create a new gist, name the file with the extension `.adoc` and enter AsciiDoc markup.
You can save the document as public or secret.
If you want to try AsciiDoc without installing any software, a gist is a great way to get started.

// image?

While there's plenty more of the AsciiDoc syntax and toolchain to explore, you know more than enough about it to write a range of documentation, from a simple README to a comprehensive user guide.

== Wrap-up

Writing in AsciiDoc should be no more complex than writing an e-mail.
All you need to compose a document in AsciiDoc is open a text editor and type regular paragraphs.
Only when you need additional semantics or formatting do you need to introduce markup.
Let your instinct guide you when you need to remember what punctuation to use.
The AsciiDoc syntax is based on time-tested plain-text conventions from the last several decades of computing.
Hopefully you agree that the markup does not detract from the readability of the text in raw form, as that's a key goal of lightweight markup languages like AsciiDoc.

As humans, communication is what connects us through the ages and allows us to pass on knowledge.
AsciiDoc enables you to focus on communicating rather than distracting you with other stuff that just gets in the way.
Copy the text of an e-mail into a document and see how easy it to repurpose it as documentation.
Almost immediately, you'll find your writing zen and enjoy the rewarding experience of producing.

[glossary]
== Glossary

[glossary]
admonition paragraph:: a callout paragraph that has a label or icon indicating its priority
admonition block:: a callout block containing complex content that has a label or icon indicating its priority
backend:: a set of templates for converting AsciiDoc source to different output format
cross reference:: a link from one location in the document to another location marked by an anchor
list continuation:: a plus sign (`+`) on a line by itself that connects adjacent lines of text to a list item
quoted text:: text which is enclosed in special punctuation to give it emphasis or special meaning

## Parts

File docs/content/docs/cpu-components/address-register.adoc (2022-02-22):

---
title: "Address Register"
date: 2022-02-04T14:46:34-08:00
weight: 20
draft: false
---

=== Address Register
The address register is a register that has the capability of incrementing and decrementing without the use of the ALU. Unlike the GPRs the address registers do not have access to the X and Y bus however they do have access to the address bus. The address registers can read and rewrite from the data bus and write to the address bus.

[NOTE]
Schematic (rev 1.2) [link:/ucpu/img/schematics/AddressRegisterModule.pdf[PDF, window="_blank"]] [link:/ucpu/img/schematics/AddressRegisterModule.svg[SVG, window="_blank"]] [link:/ucpu/img/schematics/AddressRegisterModule.png[PNG, window="_blank"]]

== Register Control

Seven control signals control the operation of the address register.

[.center]
[cols="1h,1,3", width=75%]
|===
| d_bus_read | Active high
| Read the contents of the data bus into the register latch

| d_bus_write | Active high
| Write the contents of the register latch onto the data bus

| a_bus_write | Active high
| Write the contents of the register latch onto the address bus

| reg_inc | Active high
| Increment the register by one

| reg_dec | Active high
| Decrement the register by one

| reg_carry | Active high
| This line is high if the counter performed a carry in the previous increment/decrement operation

| reg_borrow | Active high
| This line is high if the counter performed a borrow in the previous increment/decrement operation
|===

== Appendix

=== Schematic

****
.Address Purpose Register Schematic
[link=/ucpu/img/schematics/AddressRegisterModule.svg,window="_blank"]
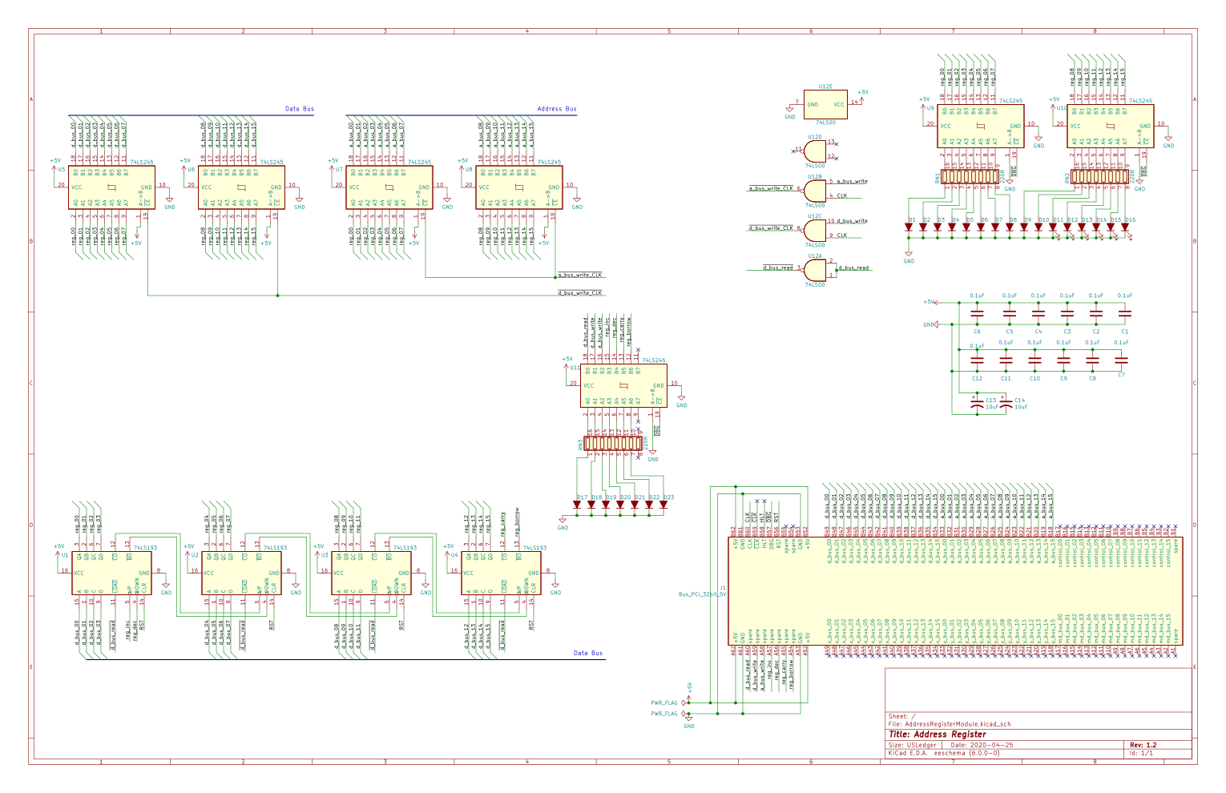
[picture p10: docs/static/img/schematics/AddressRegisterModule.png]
General Purpose Register Schematic

****

=== BOM

[.center.compact.nostripe]
[cols="2,1,3,2,2,1,1"]
|===
| Reference  | Quantity |  Value          | Datasheet | Digikey | Price | Total

| C1 - C12   | 12       | 1uf             |           |         |       |

| C13 - C14  | 2        | 10uf            |           |         |       |

| D1 - D16   | 16       | Red LED         |           |         |       |

| D17 - D23  | 7        | Amber LED       |           |         |       |

| RN1 - RN3  | 3        | 220R            |           | Y1221CT-ND |       |

| U1 - U4    | 4        | 74HCT193
| link:/ucpu/datasheets/74LS193.pdf[Datasheet, window=_blank] |         |       |

| U5 - U11  | 7        | 74HCT245
| link:/ucpu/datasheets/74LS245.pdf[Datasheet, window=_blank] |         |       |

| U12       | 1        | 74HCT08
|link:/ucpu/datasheets/74LS08.pdf[Datasheet, window=_blank] |         |       |

|===

=== Notes

* Breadboard controls (R-L)
** d_bus_read
** d_bus_write
** a_bus_write
** inc
** dec
** carry
** borrow
* While counting down or up the other should be held high
* If not the counter will not work
* Held high via pull up resistor in case of floating input
* On reset set to known state (important for PC)
* On the breadboard the address register 74LS193 is very sensitive to address and data bus levels and pull down resistors must be used on the buses.

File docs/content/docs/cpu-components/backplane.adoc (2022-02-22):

---
title: "Backplane"
date: 2022-02-04T14:46:34-08:00
weight: 50
draft: false
---

== Backplane

In Progress

[NOTE]
Backplane (rev 1.0)[link:/ucpu/img/schematics/Backplane.pdf[PDF, window="_blank"]] [link:/ucpu/img/schematics/Backplane.svg[SVG, window="_blank"]] [link:/ucpu/img/schematics/Backplane.png[PNG, window="_blank"]]

****
.General Purpose Register Schematic
[link=/ucpu/img/schematics/Backplane.svg,window="_blank"]
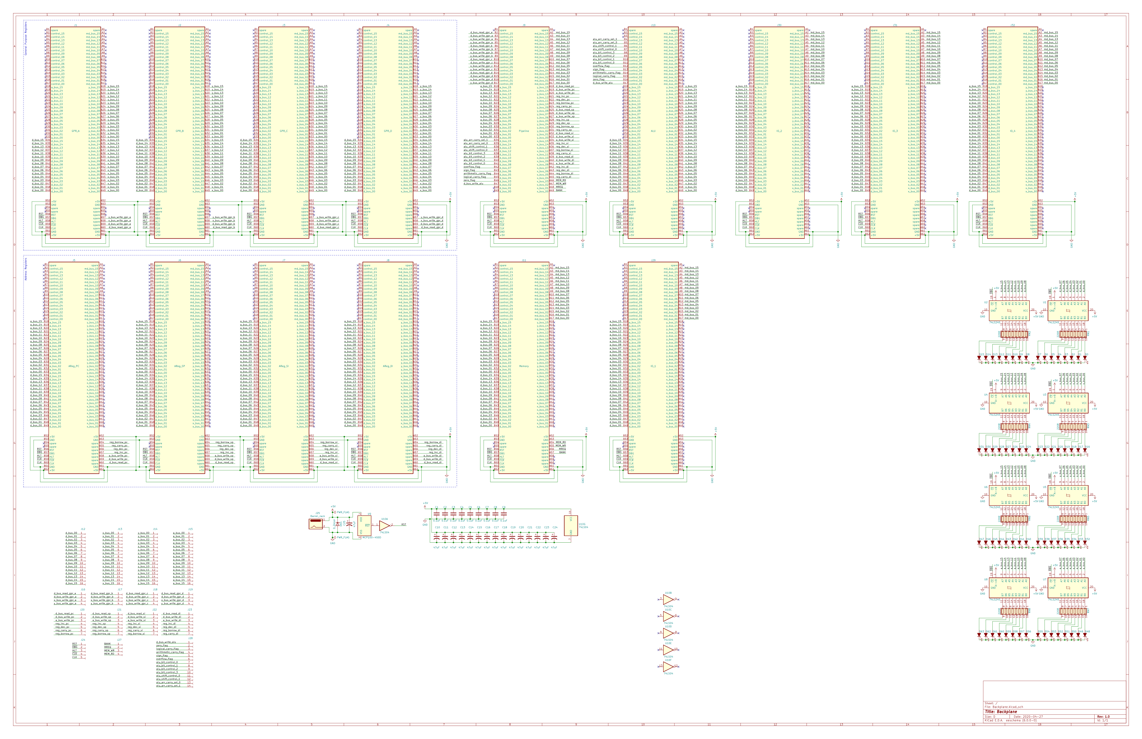
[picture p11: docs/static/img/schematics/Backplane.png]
General Purpose Register Schematic

****

* Power
** Add voltage supervisor LP3470 to provide consistent starting state
* Reset
** Design circuit
** Wait for stable power
** Low power monitor
** ...?
** https://www.grappendorf.net/projects/6502-home-computer/reset-circuit.html
** https://www.smbaker.com/z80-power-on-reset-circuits
** https://blog.mark-stevens.co.uk/2020/01/ne555-power-on-reset/
* Timer
** Better 555 circuit with 50% duty cycle
** https://ohmslawcalculator.com/555-astable-calculator
** https://www.multisim.com/content/d5VPrhr8otpMN6bm34r4JM/555-adjustable-frequency-50-duty-cycle-astable-multivibrator-charge-by-bjt-pull-up/
** https://www.electronics-tutorials.ws/waveforms/555-circuits-part-1.html
** Crystal
* Controls
** Better denounce https://www.eejournal.com/article/ultimate-guide-to-switch-debounce-part-5/
* Bus pull up/down where appropriate
* Add bare test points for all CLK and /CLK, etc points for future bodges :)

=== References

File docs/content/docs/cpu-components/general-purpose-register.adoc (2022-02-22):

---
title: "General Purpose Registers"
date: 2022-02-04T14:46:34-08:00
weight: 10
draft: false
---

== General Purpose Registers ==

Registers are small, fast memory which are close and easily accessible by the core components of the CPU. These are typically used for intermediate and temporary storage for intermediate values or data to be transferred to other areas of the CPU such as memory or IO. A common use is for instruction parameters in the ALU.

The CPU supports up to four registers: A, B, C and D. Each register has identical functionality. The registers hold 16 bit values and individual bytes are not accessible, only the full 16 bit value.

Each register has access to multiple busses in the CPU. 16 bit values may be read from the general data bus (d_bus_read) and correspondingly 16 bit values may be written (d_bus_write) to the data bus. Additionally, general purpose registers may write 16 bit values to ALU via the X (x_bus_write) and Y (y_bus_write) bus. Values may not be read from the X and Y bus by the general purpose registers.

[NOTE]
GPR (rev 1.3) [link:/ucpu/img/schematics/GPRModule.pdf[PDF, window="_blank"]] [link:/ucpu/img/schematics/GPRModule.svg[SVG, window="_blank"]] [link:/ucpu/img/schematics/GPRModule.png[PNG, window="_blank"]]

== Register Control

Four control signals control the operation of the general purpose register.

[.center]
[cols="1h,1,3", width=75%]
|===
| d_bus_read | Active high
| Read the contents of the data bus into the register latch

| d_bus_write | Active Low
| Write the contents of the register latch onto the data bus

|x_bus_write | Active Low
| Write the contents of the register latch onto the X bus to be used by the ALU

| y_bus_write | Active Low
| Write the contents of the register latch onto the Y bus to be used by the ALU
|===

== Appendix

=== Schematic

****
.General Purpose Register Schematic
[link=/ucpu/img/schematics/GPRModule.svg,window="_blank"]
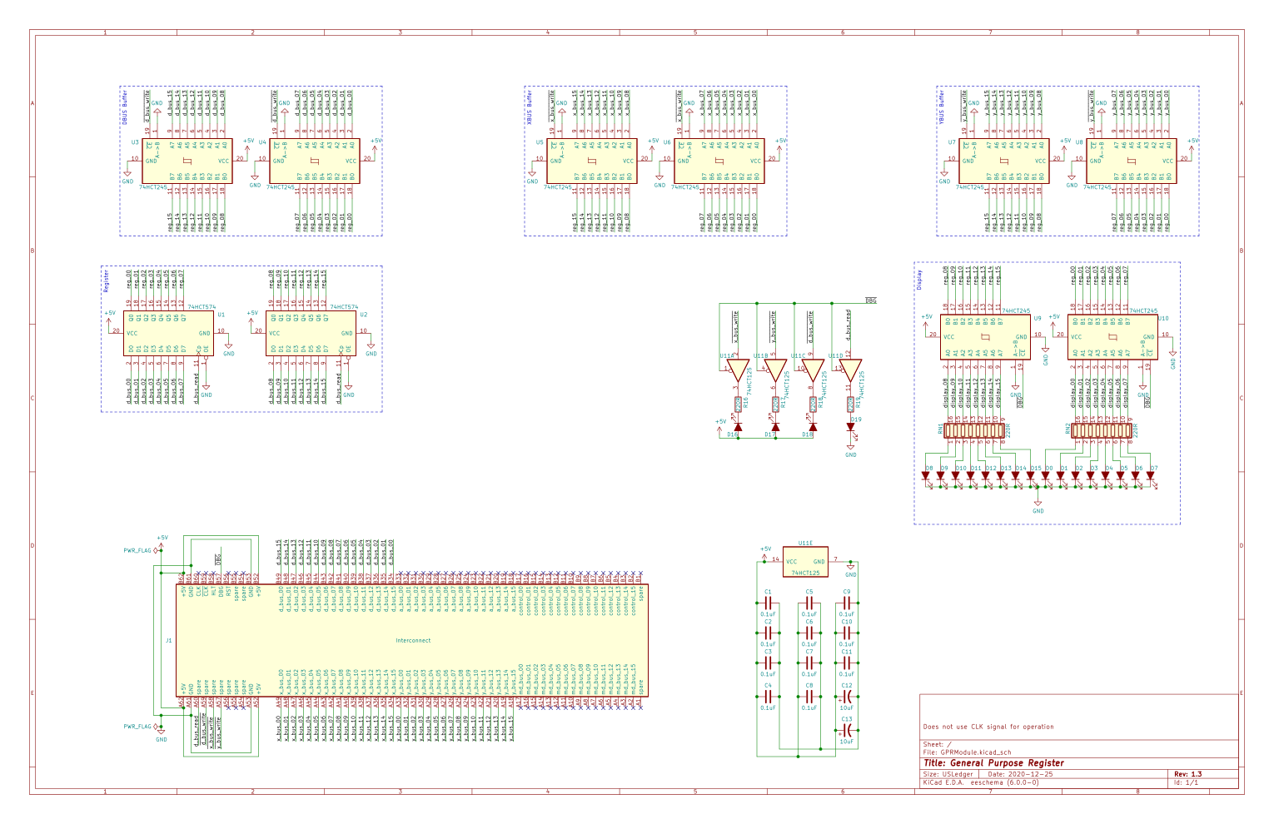
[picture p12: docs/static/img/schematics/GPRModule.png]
General Purpose Register Schematic

****

=== BOM

[.center.compact.nostripe]
[cols="2,1,3,2,2,1,1"]
|===
| Reference  | Quantity |  Value          | Datasheet | Digikey | Price | Total

| C1 - C11   | 11       | 1uf             |           |         |       |

| C12 - C13  | 2        | 10uf            |           |         |       |

| D0 - D15   | 16       | Red LED         |           |         |       |

| D16 - D19  | 4        | Amber LED       |           |         |       |

| R16 - R19  | 4        | 220R            |           |         |       |

| RN1 - RN2  | 2        | 220R            |           | Y1221CT-ND |       |

| U1 - U2    | 2        | 74HCT574
| link:/ucpu/datasheets/74LS574.pdf[Datasheet, window=_blank] |         |       |

| U3 - U10  | 8        | 74HCT245
| link:/ucpu/datasheets/74LS245.pdf[Datasheet, window=_blank] |         |       |

| U11       | 1        | 74HCT125
|link:/ucpu/datasheets/74LS125.pdf[Datasheet, window=_blank] |         |       |

|===

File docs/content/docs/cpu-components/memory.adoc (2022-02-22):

---
title: "Memory"
date: 2022-02-04T14:46:34-08:00
weight: 30
draft: false
---

The memory module has 64 KB of addressable memory space with a base configuration of 16 KB of ROM and 48 KB of RAM. Bank switching is supported extending the available memory to

* 128 KB of RAM (with extension)
* 16 KB of system ROM
* 16 KB of cartridge ROM
* 16 KB of BASIC ROM (extension)
* 16 KB of extra ROM (extension via IO board)

[NOTE]
Memory (rev 1.0) [link:/ucpu/img/schematics/MemoryModule.pdf[PDF, window="_blank"]] [link:/ucpu/img/schematics/MemoryModule.svg[SVG, window="_blank"]] [link:/ucpu/img/schematics/MemoryModule.png[PNG, window="_blank"]]

== Memory Control

Four control signals control the operation of the general purpose register.

[.center]
[cols="1h,1,3", width=75%]
|===
| RD | Active high
| Memory read from the address on the address bus to the data bus

| WR | Active high
| Write the contents of the data bus to the address on asserted to the address bus

| MEMRQ |  Active high
| A memory operation is occurring and the memory module has authority on the address and data buses

| BANK | Active high
|  Write the contents data bus to the bank register
|===

== Banking

In this description logical banks in the memory map are referred to with the letters A, B, C and D. These banks are what the CPU sees and addresses. The physical memory that a bank refers to can be changed via the bank register. These physical memory areas are called blocks and are referred to with numbers 1, 2, 3, .... For example, Bank A:0 refers to the A bank set to the first block of ROM. Similarly, D:3 refers to the D bank set to the fourth block of RAM in the memory expansion board.

.Memory Map (Banks)
[.center.compact.nostripe]
[cols="1,1,1,^1,^1", width="75%",]
|===
| H Addr | L Addr | Decimal |Bank | Addr Size

| 0x00 | 0x00 | 0 .3+^|[.rotate]#Bank A Rom# .3+|[.rotate]#16 KB#

| ...  | ...  | ...

| 0x3F | 0xFF | 16,383

| 0x40 | 0x00 | 16,384 .3+^|[.rotate]#Bank B RAM# .3+|[.rotate]#16 KB#

| ...  | ...  | ...

| 0x7F | 0xFF | 32,767

| 0x80 | 0x00 | 32,768 .3+|[.rotate]#Bank C RAM# .3+|[.rotate]#16 KB#

| ...  | ...  | ...

| 0xBF | 0xFF | 49,151

| 0xC0 | 0x00 | 49,152 .3+|[.rotate]#Bank D RAM# .3+|[.rotate]#16 KB#

| ...  | ...  | ...

| 0xFF | 0xFF | 65,535

|===

The first three memory banks (A, B, C) can be changed with a special instruction (TODO: Add instruction). Bank A is always a ROM though it could be system, cartrige or I/O ROM. This is because the program counter starts at 0x00 and must have executable code at boot. Bank B is not bankable because that is where the stack resides and banking that area of memory could cause errors.

The CPU must have the base 16 KB of ROM and 48 KB of RAM installed but the extended banks are optional.

The memory bank configuration is set via a register in the memory controller. The (Insert instruction here) instruction will write the contents of the A register to the memory bank register. Bank A is controlled by the lower 2 bits (0 and 1) of the register value and banks C and D are controlled by the next two bits (2 and 3) of the register value. As mentioned, bank B can can not be changed. This means there are four configurations for bank A, specifically the system ROM, BASIC ROM, cartrige ROM and IO ROM. Banks C and There are also four configurations for banks C and D.

A value of 0x00 is the default power on banking value. In this configuration there is no banking. The base 32 KB of ROM and 32 KB of RAM is used.

.Bank Register
[.center.compact.nostripe]
[cols="1,2,2,2,2", width="75%",]
|===
| Value | Bank A           | Bank B           | Bank C           | Bank D

| 0x00  | ROM A:0 (Base A) | ROM B:0 (BASE B) | RAM C:0 (Base C) | ROM D:0 (BASE D)

| 0x01  | ROM A:1 (BASIC)  | ROM B:0 (BASE B) | RAM C:0 (Base C) | ROM D:0 (BASE C)

| 0x02  | ROM A:2 (Cart)   | ROM B:0 (BASE B) | RAM C:0 (Base C) | ROM D:0 (BASE B)

| 0x03  | ROM A:3 (IO)     | ROM B:0 (BASE B) | RAM C:0 (Base C) | ROM D:0 (BASE B)

| 0x00  | ROM A:0 (Base A) | ROM B:1          | RAM C:1          | ROM D:1

| 0x01  | ROM A:1 (BASIC)  | ROM B:1          | RAM C:1          | ROM D:1

| 0x02  | ROM A:2 (Cart)   | ROM B:1          | RAM C:1          | ROM D:1

| 0x03  | ROM A:3 (IO)     | ROM B:1          | RAM C:1          | ROM D:1

| 0x00  | ROM A:0 (Base A) | ROM B:2          | RAM C:2          | ROM D:2

| 0x01  | ROM A:1 (BASIC)  | ROM B:2          | RAM C:2          | ROM D:2

| 0x02  | ROM A:2 (Cart)   | ROM B:2          | RAM C:2          | ROM D:2

| 0x03  | ROM A:3 (IO)     | ROM B:2          | RAM C:2          | ROM D:2

| 0x00  | ROM A:0 (Base A) | ROM B:3          | RAM C:3          | ROM D:3

| 0x01  | ROM A:1 (BASIC)  | ROM B:3          | RAM C:3          | ROM D:3

| 0x02  | ROM A:2 (Cart)   | ROM B:3          | RAM C:3          | ROM D:3

| 0x03  | ROM A:3 (IO)     | ROM B:3          | RAM C:3          | ROM D:3

|===

== Hardware

* ROM and RAM chips have 8-bit data width per chip. Thus needs two chips for 16 bit data bus width
** ram and rom interleaved between two chips
* ROM
** Uses AT28C64 which has 13 address lines and 8 data lines
** ROM code must be split abababab when programming
** A ROM set (A&B) with 13 address lines takes up 8 KB in the address space
** TODO: Figure out if mem module should use MDBus or DBUS???
* RAM
** Uses AS6C6264 which has 13 address lines and 8 data lines
** Similar chip splitting to the ROMs
** RAM read/write cycles take 55 - 65 ns which translate to about 15 MHz

== Appendix

=== Schematic
****
.General Purpose Register Schematic
[link=/ucpu/img/schematics/MemoryModule.svg,window="_blank"]
General Purpose Register Schematic
****

=== BOM

[.center.compact.nostripe]
[cols="2,1,3,2,2,1,1"]
|===
| Reference  | Quantity |  Value          | Datasheet | Digikey | Price | Total

| C1 - C27   | 27       | 1uf             |           |         |       |

| C41 - C44  | 4        | 10uf            |           |         |       |

| D1 - D32   | 32       |                 |           |         |       |

| J2 - J3    | 2        | 1x24 pin header |           |         |       |

| RN1 - RN4  | 4        | 220R            |           | Y1221CT-ND |       |

| U1 - U4    | 4        | AT28C64B-15PU
| link:/ucpu/datasheets/AS6C6264.pdf[Datasheet, window=_blank] |         |       |

| U5 - U16   | 12       | AS6C6264-55PCN
|link:/ucpu/datasheets/AT28C64B.pdf[Datasheet, window=_blank] |         |       |

| U17        | 1        | 74HCT173
| link:/ucpu/datasheets/74LS173.pdf[Datasheet, window=_blank] |         |       |

| U18 - U19  | 2        | 74HCT139
| link:/ucpu/datasheets/74LS139.pdf[Datasheet, window=_blank] |         |       |

| U20 - U23  | 3        | 74HCT04
| link:/ucpu/datasheets/74LS04.pdf[Datasheet, window=_blank] |         |       |

| U24 - U27  | 4        | 74HCT245
| link:/ucpu/datasheets/74LS245.pdf[Datasheet, window=_blank] |         |       |
|===

=== Notes
Breadboard controls (R-L)

** RD
** WR
** MEM REQ
** BANK

=== Reference

* link:https://en.wikipedia.org/wiki/Bank_switching[Bank Switching, window="_blank"]
* link:http://www.zcontrol.narod.ru/diagrams/ZramBankSwitch.pdf[Z80 Bank-Switching Scheme]
* link:https://hackaday.io/project/98837-8-bit-portable-internet-enabled-computer/log/143571-moving-from-the-exotic-74ls610-mmu-to-normal-bank-switching[Moving From the Exotic 74LS610 MMU to Normal Bank Switching]

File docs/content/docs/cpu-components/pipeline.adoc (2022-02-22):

---
title: "Pipeline"
date: 2022-02-04T14:46:34-08:00
weight: 40
draft: false
---

== Pipeline

In Progress

=== References
* https://www.cs.fsu.edu/~zwang/files/cda3101/Fall2017/Lecture8_cda3101.pdf

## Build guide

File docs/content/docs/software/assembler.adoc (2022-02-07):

---
title: "Assembler"
date: 2022-02-04T14:46:34-08:00
weight: 2
draft: false
---

== Assembler

=== References

* link:https://github.com/hlorenzi/customasm[customasm, window="_blank"]
* link:https://github.com/szoftveres/ttlcpu[ttlcpu, window="_blank"]

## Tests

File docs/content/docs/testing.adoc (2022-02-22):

---
title: "Testing"
date: 2022-02-04T14:46:34-08:00
weight: 10
draft: false
---

Tests

* GRP
** Write to DBUS
** Read from DBUS
** Write to XBUS
** Write to YBUS
* Address Registers
** Write to DBUS
** Read from DBUS
** Write to ABUS
** Increment
** Decrement

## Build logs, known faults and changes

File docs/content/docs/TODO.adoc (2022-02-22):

---
title: "TODO"
weight: 30
draft: false
---

== TODO:

. License file
. Update all schematics to use HCT rather than LS

Documentation

. Add memory timing diagram to documentation
. Bank diagram in documentation
. Create memory map with stack, I/O, Video etc. locations

Address Reg

. Validate connector positions

Memory

Backplane

. Add pull down resistors to bus'

Compliler

. Web editor for writing code
. JS compiler
. JS emulator

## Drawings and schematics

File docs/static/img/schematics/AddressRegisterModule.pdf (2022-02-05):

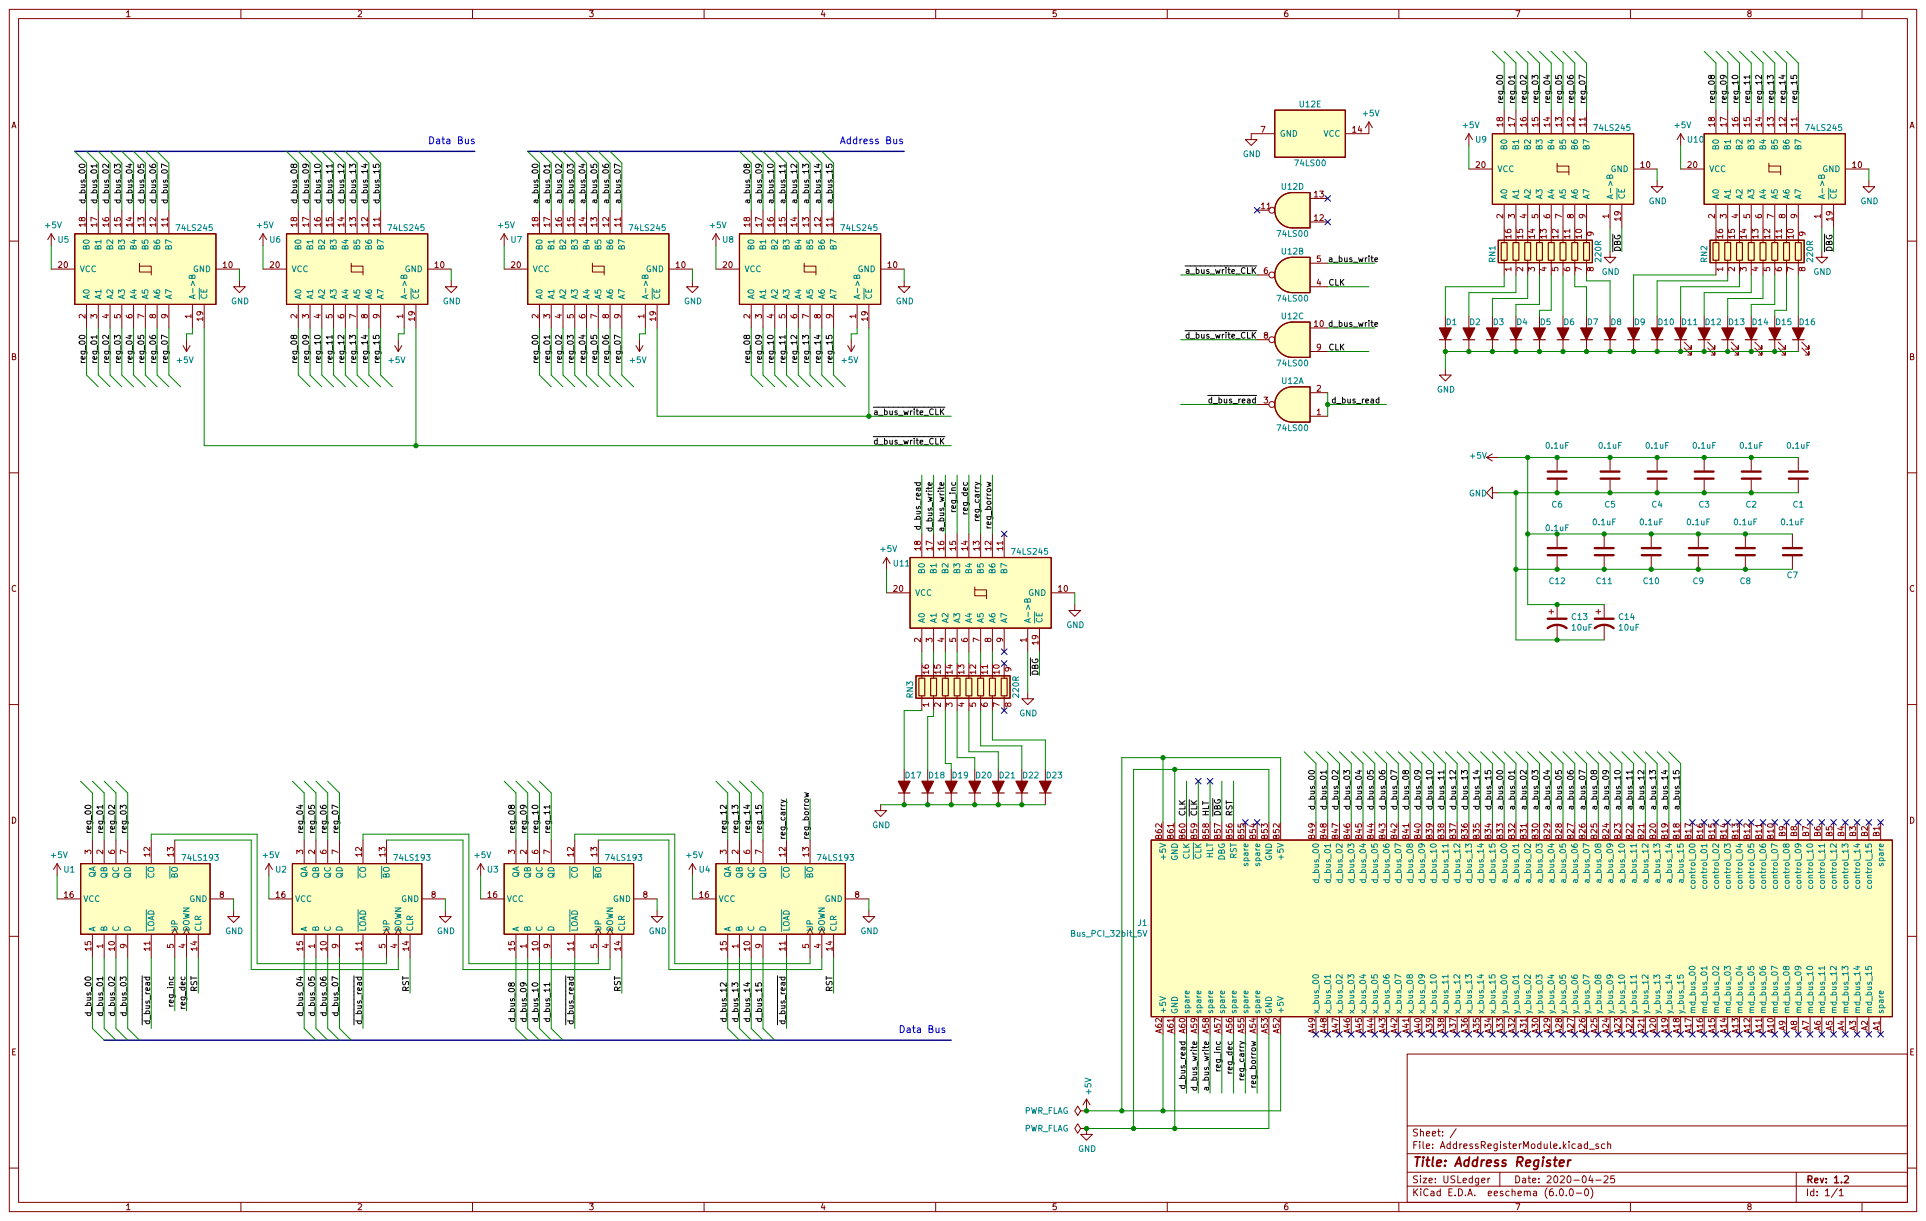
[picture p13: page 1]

8 9 RN2 220R GND GND GND~{DBG} reg_14 d_bus_14 d_bus_15 reg_09 reg_10 reg_11 reg_12 reg_13 reg_15

1 C 10 ~{LOAD} 11 ~{CO} 12 ~{BO} 13 CLR 14 A 15 VCC 16 QB

File: AddressRegisterModule.kicad_sch Sheet: /
Id: 1/1 Title: Address Register

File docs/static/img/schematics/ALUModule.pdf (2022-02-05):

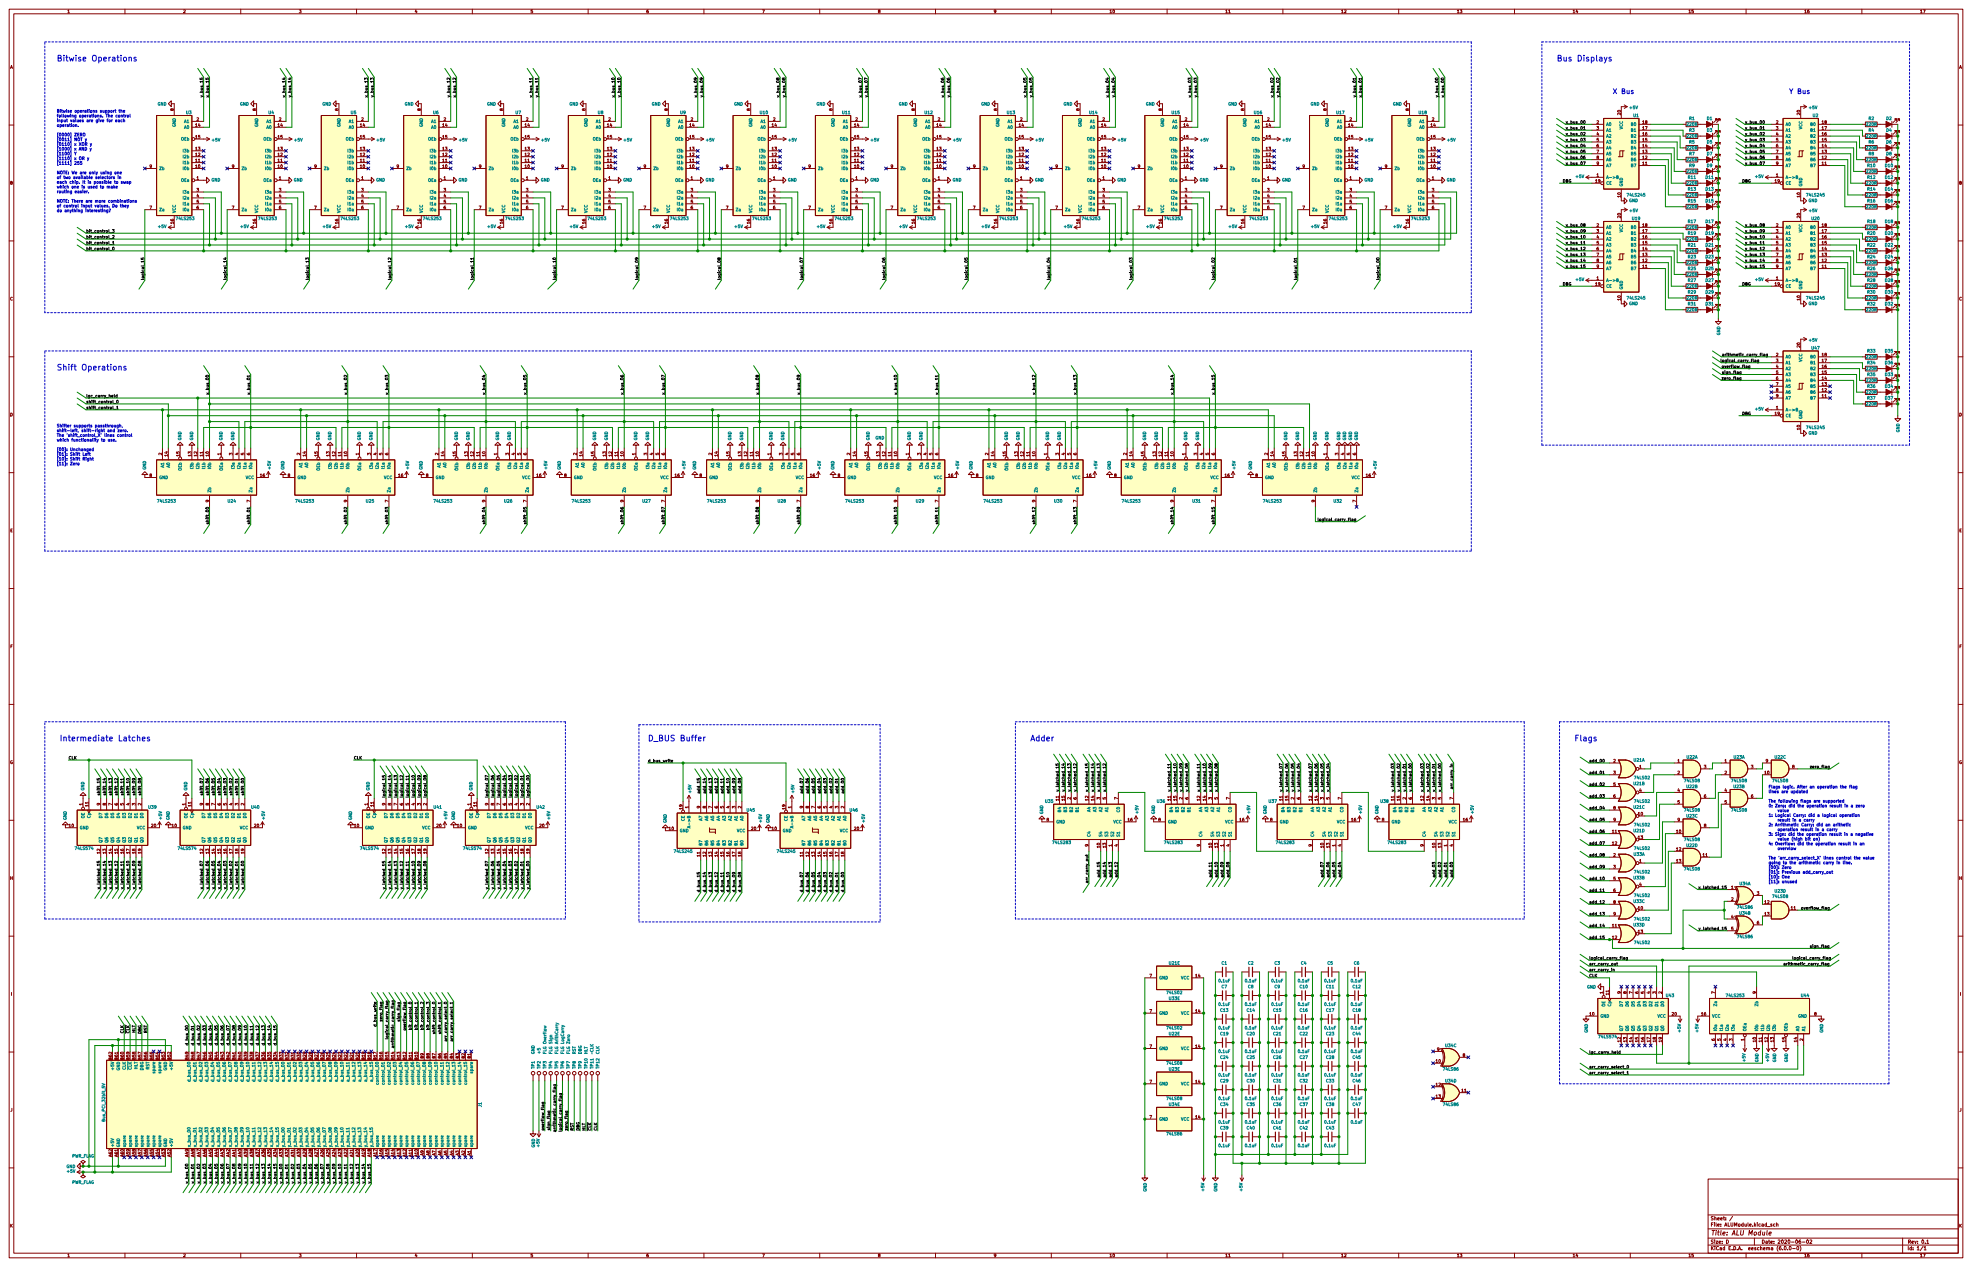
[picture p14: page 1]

Bitwise operations support the
following operations. The control
input values are give for each
operation.

NOTE: We are only using one
of two available selectors in
each chip. It is possible to swap which one is used to make

routing easier. NOTE: There are more combinations of control input values. Do they

Shifter supports passthrough,
shift-left, shift-right and zero. The 'shift_control_X' lines control which functionality to use.

Flags logic. After an operation the flag
lines are updated

The following flags are supported

0: Zero: did the operation result in a zero

value
1: Logical Carry: did a logical operation
result in a carry
2: Arrithmetic Carry: did an arithetic
operation result in a carry
3: Sign: did the operation result in a negative
value (high bit on)
4: Overflow: did the operation result in an
overvlow

The 'arr_carry_select_X' lines control the value
going to the arithmetic carry in line.
[00]: Zero
[01]: Previous add_carry_out
[10]: One
[11]: unused

File: ALUModule.kicad_sch Sheet: / +5V GND

Id: 1/1 Title: ALU Module

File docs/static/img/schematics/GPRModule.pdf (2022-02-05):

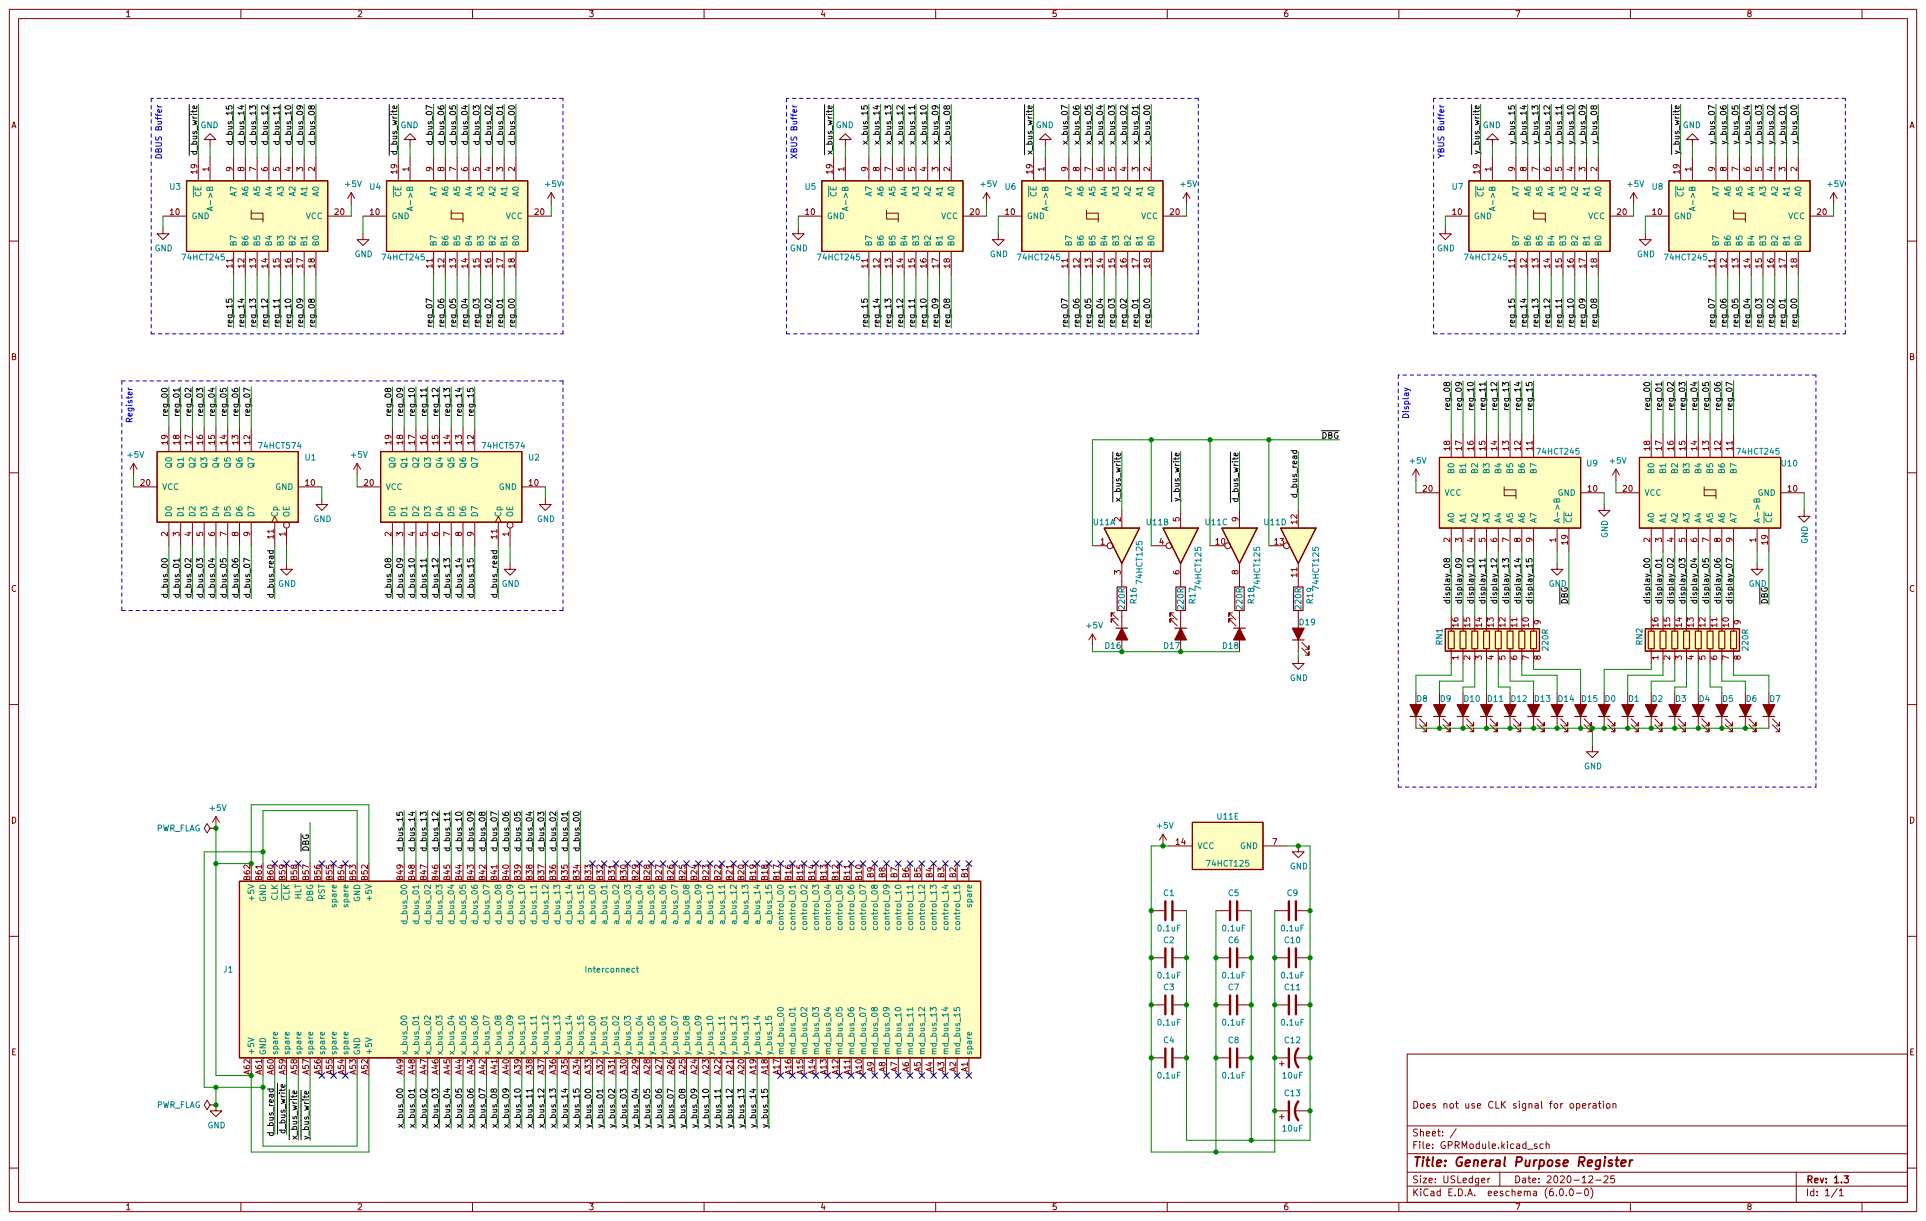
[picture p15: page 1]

File: GPRModule.kicad_sch Sheet: / Does not use CLK signal for operation

Id: 1/1 Title: General Purpose Register

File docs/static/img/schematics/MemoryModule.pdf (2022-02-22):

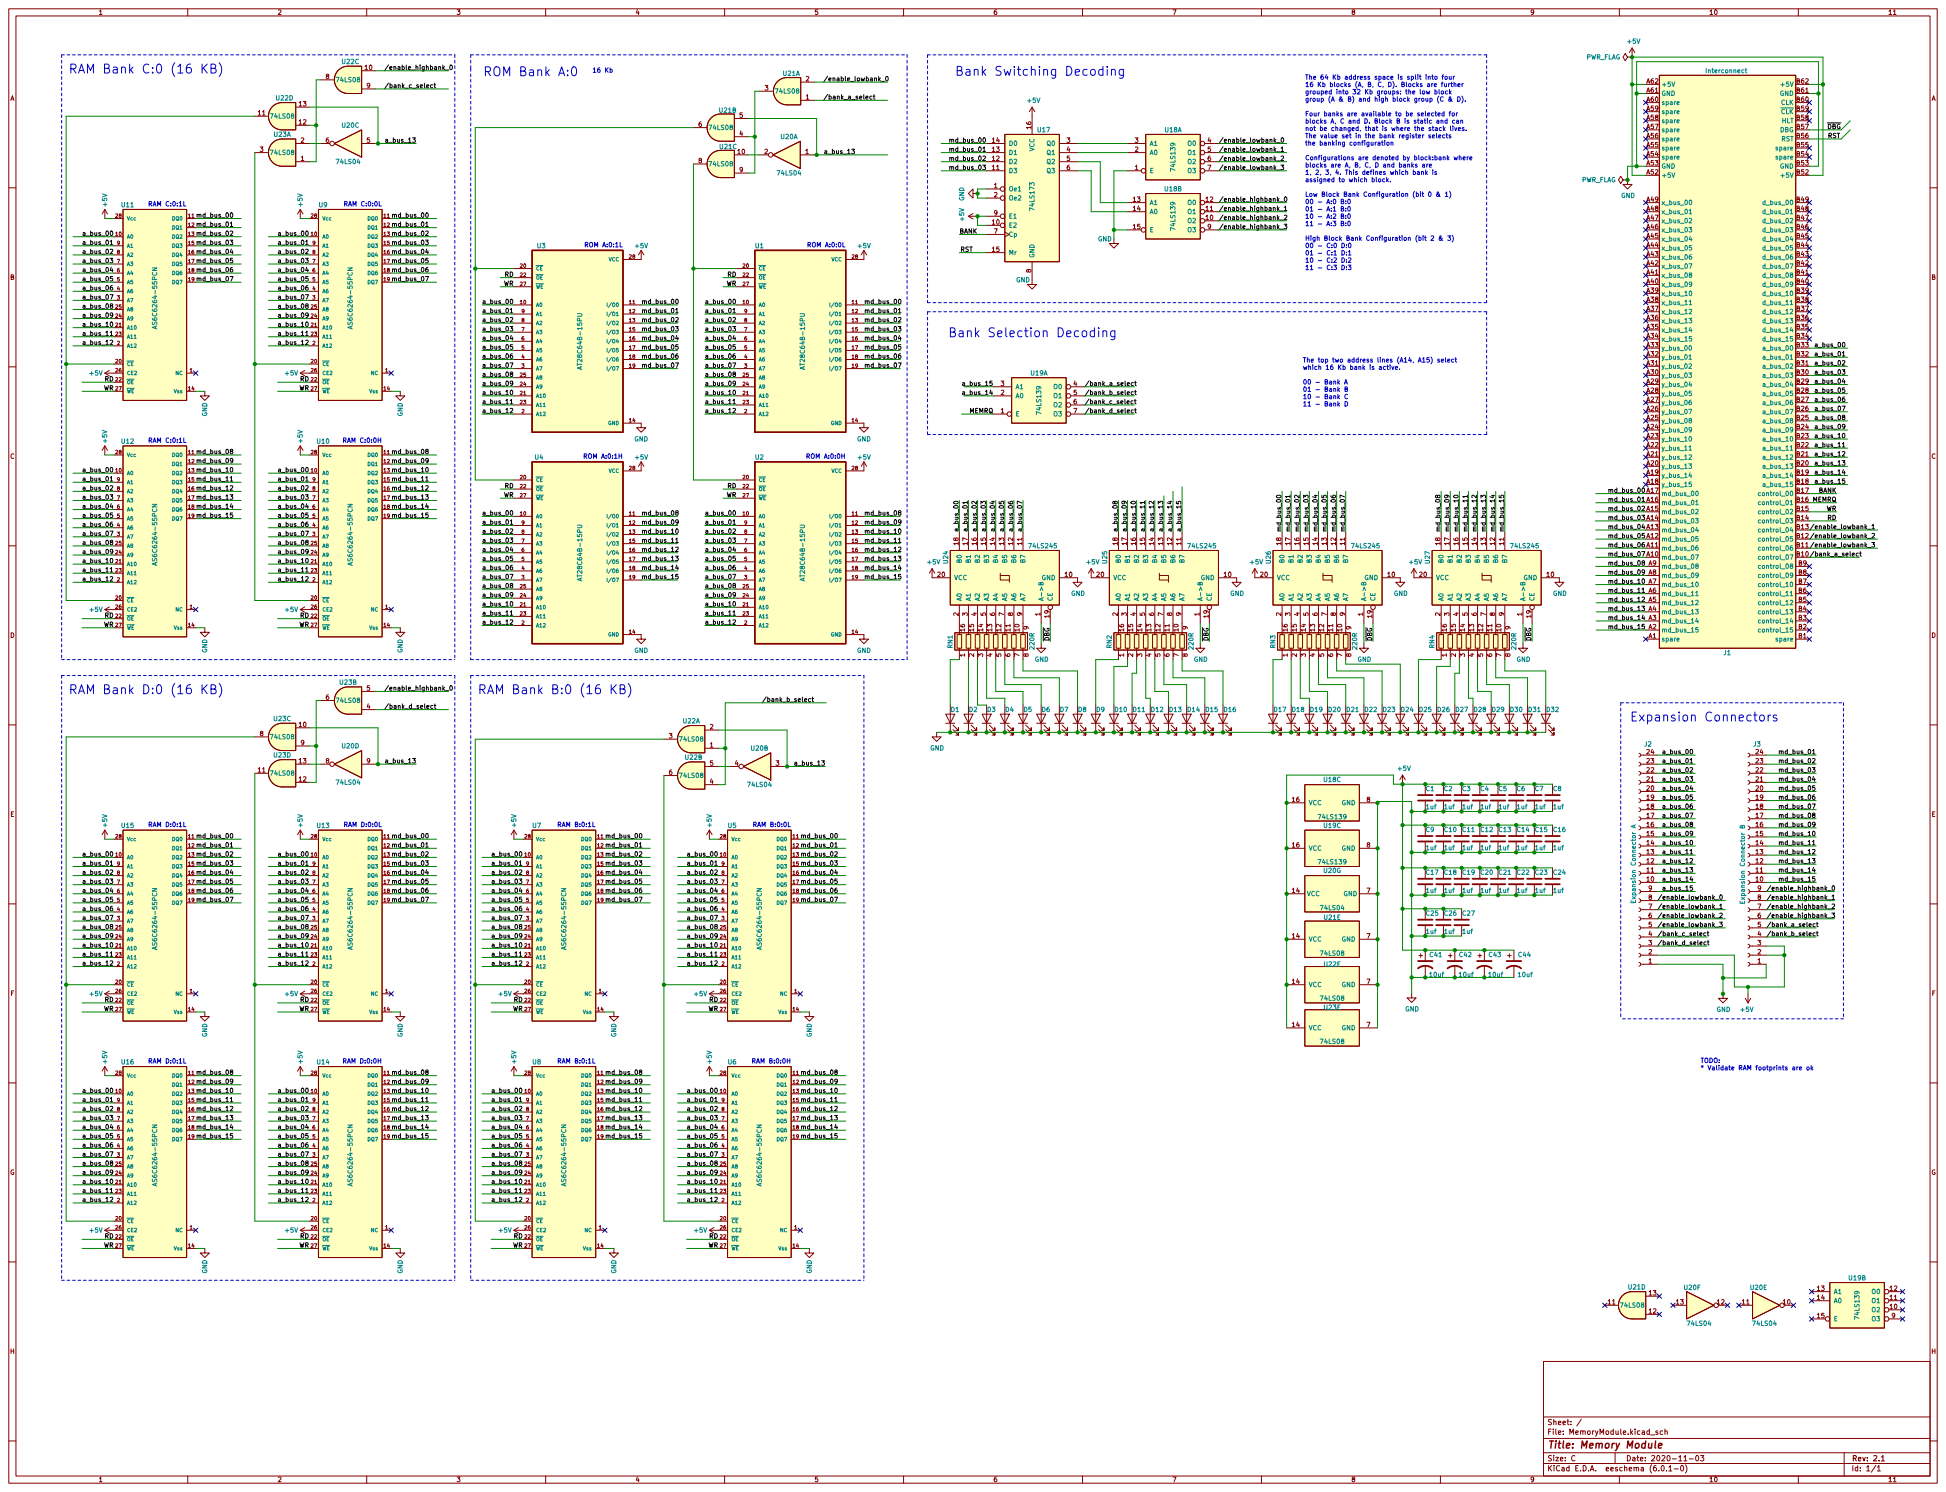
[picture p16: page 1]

The 64 Kb address space is split into four
16 Kb blocks (A, B, C, D). Blocks are further
grouped into 32 Kb groups: the low block
group (A & B) and high block group (C & D). Four banks are available to be selected for blocks A, C and D. Block B is static and can

not be changed, that is where the stack lives.
The value set in the bank register selects
the banking configuration

Configurations are denoted by block:bank where
blocks are A, B, C, D and banks are
1, 2, 3, 4. This defines which bank is assigned to which block.

Low Block Bank Configuration (bit 0 & 1) 00 - A:0 B:0

File: MemoryModule.kicad_sch Sheet: /
Id: 1/1 Title: Memory Module

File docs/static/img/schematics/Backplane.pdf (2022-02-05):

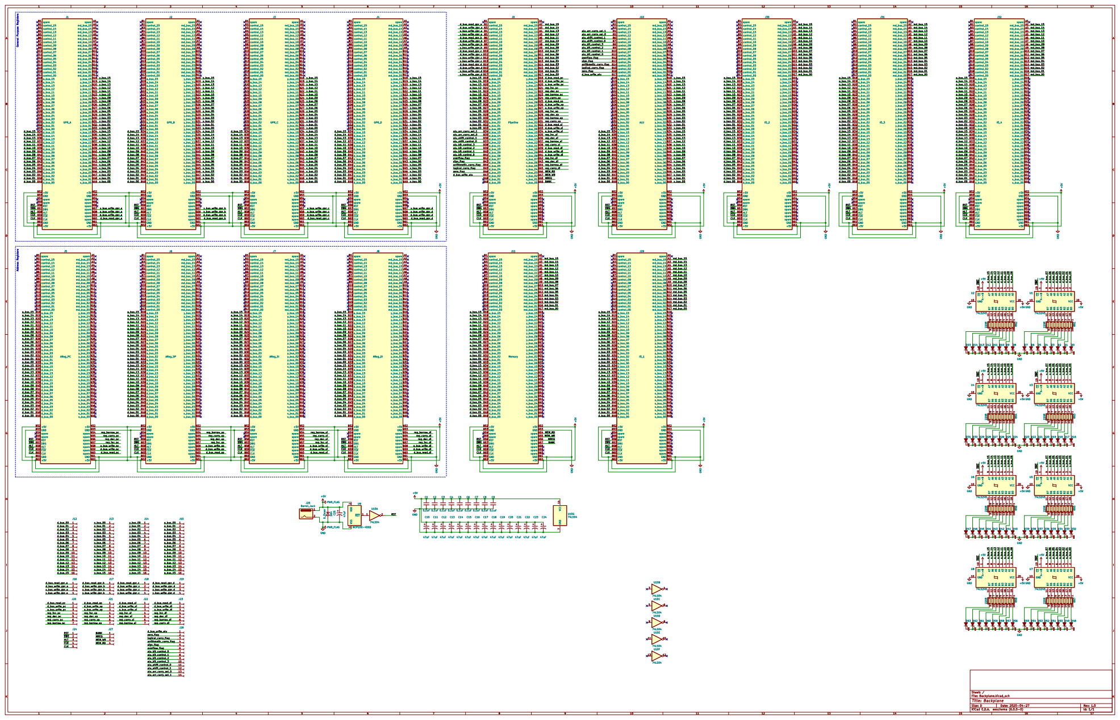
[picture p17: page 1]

spare B54
spare B55 RST B56 DBG B57 HLT B58 ~{CLK} B59

~{DBG} RST HLT
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

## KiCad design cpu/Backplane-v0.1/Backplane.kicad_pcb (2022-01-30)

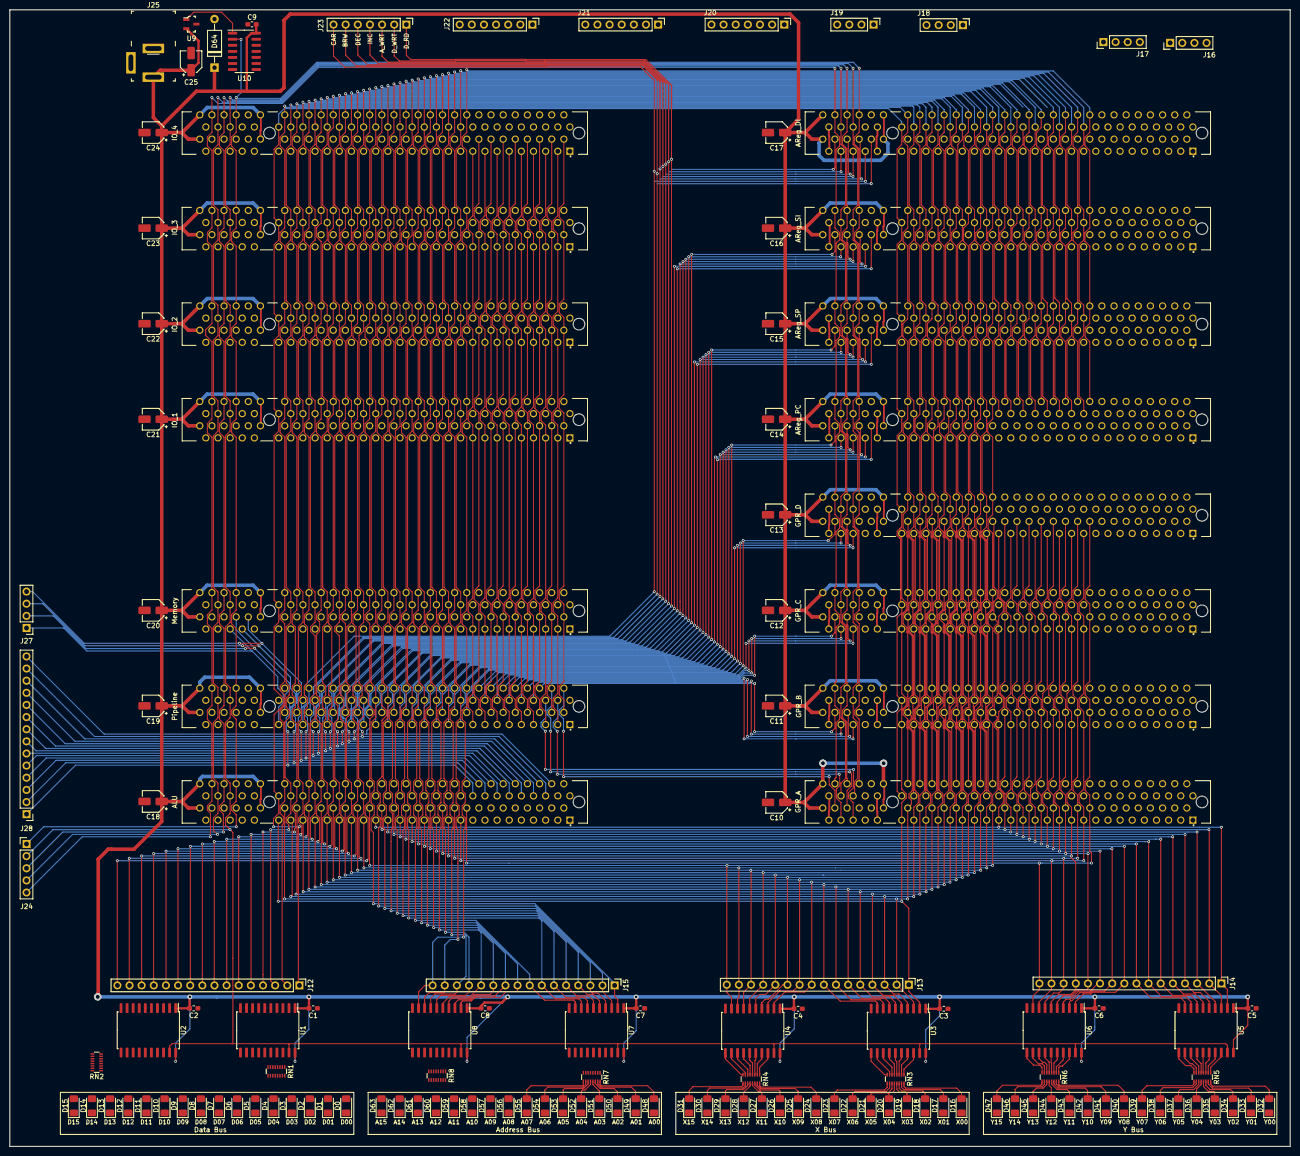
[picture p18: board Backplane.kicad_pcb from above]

Board: 2 copper layers, 268.0 x 237.9 mm, 139 parts (0 on the bottom side), 278 nets.

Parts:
C1, C2, C3, C4, C5, C6, C7, C8, C9: 0.1uF; C_0603_1608Metric_Pad1.05x0.95mm_HandSolder
C10, C11, C12, C13, C14, C15, C16, C17, C18, C19, C20, C21, C22, C23, C24, C25: 47uF; CP_Elec_4x5.4
D0, D1, D2, D3, D4, D5, D6, D7, D8, D9, D10, D11, D12, D13, D14, D15, D16, D17, D18, D19, D20, D21, D22, D23, D24, D25, D26, D27, D28, D29, D30, D31, D32, D33, D34, D35, D36, D37, D38, D39, D40, D41, D42, D43, D44, D45, D46, D47, D48, D49, D50, D51, D52, D53, D54, D55, D56, D57, D58, D59, D60, D61, D62, D63: LED_BLUE; LED_1206_3216Metric_Pad1.42x1.75mm_HandSolder
D64: D_Zener; D_A-405_P10.16mm_Horizontal
J1: GPR_A; TE_1-5145154-2
J2: GPR_B; TE_1-5145154-2
J3: GPR_C; TE_1-5145154-2
J4: GPR_D; TE_1-5145154-2
J5: AReg_PC; TE_1-5145154-2
J6: AReg_SP; TE_1-5145154-2
J7: AReg_SI; TE_1-5145154-2
J8: AReg_DI; TE_1-5145154-2
J9: Pipeline; TE_1-5145154-2
J10: ALU; TE_1-5145154-2
J11: Memory; TE_1-5145154-2
J12, J13, J14, J15: Conn_01x16_Female; PinHeader_1x16_P2.54mm_Vertical
J16, J17, J18, J19, J27: Conn_01x04_Female; PinHeader_1x04_P2.54mm_Vertical
J20, J21, J22, J23: Conn_01x07_Female; PinHeader_1x07_P2.54mm_Vertical
J24: Conn_01x05_Female; PinHeader_1x05_P2.54mm_Vertical
J25: Barrel_Jack; Barrel_Jack_5.5mmODx2.1mmID_PJ-202A
J28: Conn_01x14_Female; PinHeader_1x14_P2.54mm_Vertical
J29: IO_1; TE_1-5145154-2
J30: IO_2; TE_1-5145154-2
J31: IO_3; TE_1-5145154-2
J32: IO_4; TE_1-5145154-2
RN1, RN2, RN3, RN4, RN5, RN6, RN7, RN8: 220R; R_Array_Convex_8x0602
U1, U2, U3, U4, U5, U6, U7, U8: 74LS245; SOIC-20W_7.5x12.8mm_P1.27mm
U9: MCP100-450D; SOT-23-3
U10: 74LS04; SOIC-14_3.9x8.7mm_P1.27mm

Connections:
+5V: C1.1, C2.1, C3.1, C4.1, C5.1, C6.1, C7.1, C8.1, C9.1, C10.1, C11.1, C12.1, C13.1, C14.1, C15.1, C16.1, C17.1, C18.1, C19.1, C20.1, C21.1, C22.1, C23.1, C24.1, C25.1, D64.1, J1.A52, J1.A62, J1.B52, J1.B62, J2.A52, J2.A62, J2.B52, J2.B62, J3.A52, J3.A62, J3.B52, J3.B62, J4.A52, J4.A62, J4.B52, J4.B62, J5.A52, J5.A62, J5.B52, J5.B62, J6.A52, J6.A62, J6.B52, J6.B62, J7.A52, J7.A62, J7.B52, J7.B62, J8.A52, J8.A62, J8.B52, J8.B62, J9.A52, J9.A62, J9.B52, J9.B62, J10.A52, J10.A62, J10.B52, J10.B62, J11.A52, J11.A62, J11.B52, J11.B62, J25.1, J29.A52, J29.A62, J29.B52, J29.B62, J30.A52, J30.A62, J30.B52, J30.B62, J31.A52, J31.A62, J31.B52, J31.B62, J32.A52, J32.A62, J32.B52, J32.B62, U1.1, U1.20, U2.1, U2.20, U3.1, U3.20, U4.1, U4.20, U5.1, U5.20, U6.1, U6.20, U7.1, U7.20, U8.1, U8.20, U9.2, U10.14
/BANK: J9.A49, J11.A57, J27.1
/CLK: J1.B60, J2.B60, J3.B60, J4.B60, J5.B60, J6.B60, J7.B60, J8.B60, J9.B60, J10.B60, J11.B60, J24.5, J29.B60, J30.B60, J31.B60, J32.B60
/HLT: J1.B58, J2.B58, J3.B58, J4.B58, J5.B58, J6.B58, J7.B58, J8.B58, J9.B58, J10.B58, J11.B58, J24.3, J29.B58, J30.B58, J31.B58, J32.B58
/MEM_RD: J9.A46, J11.A54, J27.4
/MEM_WR: J9.A47, J11.A55, J27.3
/MREQ: J9.A48, J11.A56, J27.2
/RST: J1.B56, J2.B56, J3.B56, J4.B56, J5.B56, J6.B56, J7.B56, J8.B56, J9.B56, J10.B56, J11.B56, J24.1, J29.B56, J30.B56, J31.B56, J32.B56, U10.2
/a_bus_00: J5.B33, J6.B33, J7.B33, J8.B33, J9.B33, J11.B33, J15.1, J29.B33, J30.B33, J31.B33, J32.B33, U7.2
/a_bus_01: J5.B32, J6.B32, J7.B32, J8.B32, J9.B32, J11.B32, J15.2, J29.B32, J30.B32, J31.B32, J32.B32, U7.3
/a_bus_02: J5.B31, J6.B31, J7.B31, J8.B31, J9.B31, J11.B31, J15.3, J29.B31, J30.B31, J31.B31, J32.B31, U7.4
/a_bus_03: J5.B30, J6.B30, J7.B30, J8.B30, J9.B30, J11.B30, J15.4, J29.B30, J30.B30, J31.B30, J32.B30, U7.5
/a_bus_04: J5.B29, J6.B29, J7.B29, J8.B29, J9.B29, J11.B29, J15.5, J29.B29, J30.B29, J31.B29, J32.B29, U7.6
/a_bus_05: J5.B28, J6.B28, J7.B28, J8.B28, J9.B28, J11.B28, J15.6, J29.B28, J30.B28, J31.B28, J32.B28, U7.7
/a_bus_06: J5.B27, J6.B27, J7.B27, J8.B27, J9.B27, J11.B27, J15.7, J29.B27, J30.B27, J31.B27, J32.B27, U7.8
/a_bus_07: J5.B26, J6.B26, J7.B26, J8.B26, J9.B26, J11.B26, J15.8, J29.B26, J30.B26, J31.B26, J32.B26, U7.9
/a_bus_08: J5.B25, J6.B25, J7.B25, J8.B25, J9.B25, J11.B25, J15.9, J29.B25, J30.B25, J31.B25, J32.B25, U8.2
/a_bus_09: J5.B24, J6.B24, J7.B24, J8.B24, J9.B24, J11.B24, J15.10, J29.B24, J30.B24, J31.B24, J32.B24, U8.3
/a_bus_10: J5.B23, J6.B23, J7.B23, J8.B23, J9.B23, J11.B23, J15.11, J29.B23, J30.B23, J31.B23, J32.B23, U8.4
/a_bus_11: J5.B22, J6.B22, J7.B22, J8.B22, J9.B22, J11.B22, J15.12, J29.B22, J30.B22, J31.B22, J32.B22, U8.5
/a_bus_12: J5.B21, J6.B21, J7.B21, J8.B21, J9.B21, J11.B21, J15.13, J29.B21, J30.B21, J31.B21, J32.B21, U8.6
/a_bus_13: J5.B20, J6.B20, J7.B20, J8.B20, J9.B20, J11.B20, J15.14, J29.B20, J30.B20, J31.B20, J32.B20, U8.7
/a_bus_14: J5.B19, J6.B19, J7.B19, J8.B19, J9.B19, J11.B19, J15.15, J29.B19, J30.B19, J31.B19, J32.B19, U8.8
/a_bus_15: J5.B18, J6.B18, J7.B18, J8.B18, J9.B18, J11.B18, J15.16, J29.B18, J30.B18, J31.B18, J32.B18, U8.9
/a_bus_write_di: J8.A58, J9.A41, J23.3
/a_bus_write_pc: J5.A58, J9.A20, J20.3
/a_bus_write_si: J7.A58, J9.A34, J22.3
/a_bus_write_sp: J6.A58, J9.A27, J21.3
/alu_arr_carry_sel_0: J9.B35, J10.B5, J28.13
/alu_arr_carry_sel_1: J9.B34, J10.B4, J28.14
/alu_bit_control_0: J9.B41, J10.B11, J28.7
/alu_bit_control_1: J9.B40, J10.B10, J28.8
/alu_bit_control_2: J9.B39, J10.B9, J28.9
/alu_bit_control_3: J9.B38, J10.B8, J28.10
/alu_shift_control_0: J9.B37, J10.B7, J28.11
/alu_shift_control_1: J9.B36, J10.B6, J28.12
/arrithmetic_carry_flag: J9.B44, J10.B14, J28.4
/d_bus_00: J1.B49, J2.B49, J3.B49, J4.B49, J5.B49, J6.B49, J7.B49, J8.B49, J10.B49, J11.B49, J12.1, J29.B49, J30.B49, J31.B49, J32.B49, U1.2
/d_bus_01: J1.B48, J2.B48, J3.B48, J4.B48, J5.B48, J6.B48, J7.B48, J8.B48, J10.B48, J11.B48, J12.2, J29.B48, J30.B48, J31.B48, J32.B48, U1.3
/d_bus_02: J1.B47, J2.B47, J3.B47, J4.B47, J5.B47, J6.B47, J7.B47, J8.B47, J10.B47, J11.B47, J12.3, J29.B47, J30.B47, J31.B47, J32.B47, U1.4
/d_bus_03: J1.B46, J2.B46, J3.B46, J4.B46, J5.B46, J6.B46, J7.B46, J8.B46, J10.B46, J11.B46, J12.4, J29.B46, J30.B46, J31.B46, J32.B46, U1.5
/d_bus_04: J1.B45, J2.B45, J3.B45, J4.B45, J5.B45, J6.B45, J7.B45, J8.B45, J10.B45, J11.B45, J12.5, J29.B45, J30.B45, J31.B45, J32.B45, U1.6
/d_bus_05: J1.B44, J2.B44, J3.B44, J4.B44, J5.B44, J6.B44, J7.B44, J8.B44, J10.B44, J11.B44, J12.6, J29.B44, J30.B44, J31.B44, J32.B44, U1.7
/d_bus_06: J1.B43, J2.B43, J3.B43, J4.B43, J5.B43, J6.B43, J7.B43, J8.B43, J10.B43, J11.B43, J12.7, J29.B43, J30.B43, J31.B43, J32.B43, U1.8
/d_bus_07: J1.B42, J2.B42, J3.B42, J4.B42, J5.B42, J6.B42, J7.B42, J8.B42, J10.B42, J11.B42, J12.8, J29.B42, J30.B42, J31.B42, J32.B42, U1.9
/d_bus_08: J1.B41, J2.B41, J3.B41, J4.B41, J5.B41, J6.B41, J7.B41, J8.B41, J10.B41, J11.B41, J12.9, J29.B41, J30.B41, J31.B41, J32.B41, U2.2
/d_bus_09: J1.B40, J2.B40, J3.B40, J4.B40, J5.B40, J6.B40, J7.B40, J8.B40, J10.B40, J11.B40, J12.10, J29.B40, J30.B40, J31.B40, J32.B40, U2.3
/d_bus_10: J1.B39, J2.B39, J3.B39, J4.B39, J5.B39, J6.B39, J7.B39, J8.B39, J10.B39, J11.B39, J12.11, J29.B39, J30.B39, J31.B39, J32.B39, U2.4
/d_bus_11: J1.B38, J2.B38, J3.B38, J4.B38, J5.B38, J6.B38, J7.B38, J8.B38, J10.B38, J11.B38, J12.12, J29.B38, J30.B38, J31.B38, J32.B38, U2.5
/d_bus_12: J1.B37, J2.B37, J3.B37, J4.B37, J5.B37, J6.B37, J7.B37, J8.B37, J10.B37, J11.B37, J12.13, J29.B37, J30.B37, J31.B37, J32.B37, U2.6
/d_bus_13: J1.B36, J2.B36, J3.B36, J4.B36, J5.B36, J6.B36, J7.B36, J8.B36, J10.B36, J11.B36, J12.14, J29.B36, J30.B36, J31.B36, J32.B36, U2.7
/d_bus_14: J1.B35, J2.B35, J3.B35, J4.B35, J5.B35, J6.B35, J7.B35, J8.B35, J10.B35, J11.B35, J12.15, J29.B35, J30.B35, J31.B35, J32.B35, U2.8
/d_bus_15: J1.B34, J2.B34, J3.B34, J4.B34, J5.B34, J6.B34, J7.B34, J8.B34, J10.B34, J11.B34, J12.16, J29.B34, J30.B34, J31.B34, J32.B34, U2.9
/d_bus_read_di: J8.A60, J9.A39, J23.1
/d_bus_read_gpr_a: J1.A60, J9.B2, J16.1
/d_bus_read_gpr_b: J2.A60, J9.B6, J17.1
/d_bus_read_gpr_c: J3.A60, J9.B10, J18.1
/d_bus_read_gpr_d: J4.A60, J9.B14, J19.1
/d_bus_read_pc: J5.A60, J9.A18, J20.1
/d_bus_read_si: J7.A60, J9.A32, J22.1
/d_bus_read_sp: J6.A60, J9.A25, J21.1
/d_bus_write_alu: J9.B47, J10.B17, J28.1
/d_bus_write_di: J8.A59, J9.A40, J23.2
/d_bus_write_gpr_a: J1.A59, J9.B3, J16.2
/d_bus_write_gpr_b: J2.A59, J9.B7, J17.2
/d_bus_write_gpr_c: J3.A59, J9.B11, J18.2
/d_bus_write_gpr_d: J4.A59, J9.B15, J19.2
/d_bus_write_pc: J5.A59, J9.A19, J20.2
/d_bus_write_si: J7.A59, J9.A33, J22.2
/d_bus_write_sp: J6.A59, J9.A26, J21.2
/logical_carry_flag: J9.B45, J10.B15, J28.3
/md_bus_00: J9.A17, J11.A17, J29.A17, J30.A17, J31.A17, J32.A17
/md_bus_01: J9.A16, J11.A16, J29.A16, J30.A16, J31.A16, J32.A16
/md_bus_02: J9.A15, J11.A15, J29.A15, J30.A15, J31.A15, J32.A15
/md_bus_03: J9.A14, J11.A14, J29.A14, J30.A14, J31.A14, J32.A14
/md_bus_04: J9.A13, J11.A13, J29.A13, J30.A13, J31.A13, J32.A13
/md_bus_05: J9.A12, J11.A12, J29.A12, J30.A12, J31.A12, J32.A12
/md_bus_06: J9.A11, J11.A11, J29.A11, J30.A11, J31.A11, J32.A11
/md_bus_07: J9.A10, J11.A10, J29.A10, J30.A10, J31.A10, J32.A10
/md_bus_08: J9.A9, J11.A9, J29.A9, J30.A9, J31.A9, J32.A9
/md_bus_09: J9.A8, J11.A8, J29.A8, J30.A8, J31.A8, J32.A8
/md_bus_10: J9.A7, J11.A7, J29.A7, J30.A7, J31.A7, J32.A7
/md_bus_11: J9.A6, J11.A6, J29.A6, J30.A6, J31.A6, J32.A6
/md_bus_12: J9.A5, J11.A5, J29.A5, J30.A5, J31.A5, J32.A5
/md_bus_13: J9.A4, J11.A4, J29.A4, J30.A4, J31.A4, J32.A4
/md_bus_14: J9.A3, J11.A3, J29.A3, J30.A3, J31.A3, J32.A3
/md_bus_15: J9.A2, J11.A2, J29.A2, J30.A2, J31.A2, J32.A2
/overflow_flag: J9.B42, J10.B12, J28.6
/reg_borrow_di: J8.A54, J9.A44, J23.6
/reg_borrow_pc: J5.A54, J9.A23, J20.7
/reg_borrow_si: J7.A54, J9.A37, J22.7
/reg_borrow_sp: J6.A54, J9.A30, J21.7
/reg_carry_di: J8.A55, J9.A45, J23.7
/reg_carry_pc: J5.A55, J9.A24, J20.6
/reg_carry_si: J7.A55, J9.A38, J22.6
/reg_carry_sp: J6.A55, J9.A31, J21.6
/reg_dec_di: J8.A56, J9.A43, J23.5
/reg_dec_pc: J5.A56, J9.A22, J20.5
/reg_dec_si: J7.A56, J9.A36, J22.5
/reg_dec_sp: J6.A56, J9.A29, J21.5
/reg_inc_di: J8.A57, J9.A42, J23.4
/reg_inc_pc: J5.A57, J9.A21, J20.4
/reg_inc_si: J7.A57, J9.A35, J22.4
/reg_inc_sp: J6.A57, J9.A28, J21.4
/sign_flag: J9.B43, J10.B13, J28.5
/x_bus_00: J1.A49, J2.A49, J3.A49, J4.A49, J10.A49, J13.1, U3.2
/x_bus_01: J1.A48, J2.A48, J3.A48, J4.A48, J10.A48, J13.2, U3.3
/x_bus_02: J1.A47, J2.A47, J3.A47, J4.A47, J10.A47, J13.3, U3.4
/x_bus_03: J1.A46, J2.A46, J3.A46, J4.A46, J10.A46, J13.4, U3.5
/x_bus_04: J1.A45, J2.A45, J3.A45, J4.A45, J10.A45, J13.5, U3.6
/x_bus_05: J1.A44, J2.A44, J3.A44, J4.A44, J10.A44, J13.6, U3.7
/x_bus_06: J1.A43, J2.A43, J3.A43, J4.A43, J10.A43, J13.7, U3.8
/x_bus_07: J1.A42, J2.A42, J3.A42, J4.A42, J10.A42, J13.8, U3.9
/x_bus_08: J1.A41, J2.A41, J3.A41, J4.A41, J10.A41, J13.9, U4.2
/x_bus_09: J1.A40, J2.A40, J3.A40, J4.A40, J10.A40, J13.10, U4.3
/x_bus_10: J1.A39, J2.A39, J3.A39, J4.A39, J10.A39, J13.11, U4.4
/x_bus_11: J1.A38, J2.A38, J3.A38, J4.A38, J10.A38, J13.12, U4.5
/x_bus_12: J1.A37, J2.A37, J3.A37, J4.A37, J10.A37, J13.13, U4.6
/x_bus_13: J1.A36, J2.A36, J3.A36, J4.A36, J10.A36, J13.14, U4.7
/x_bus_14: J1.A35, J2.A35, J3.A35, J4.A35, J10.A35, J13.15, U4.8
/x_bus_15: J1.A34, J2.A34, J3.A34, J4.A34, J10.A34, J13.16, U4.9
/x_bus_write_gpr_a: J1.A58, J9.B4, J16.3
/x_bus_write_gpr_b: J2.A58, J9.B8, J17.3
/x_bus_write_gpr_c: J3.A58, J9.B12, J18.3
/x_bus_write_gpr_d: J4.A58, J9.B16, J19.3
/y_bus_00: J1.A33, J2.A33, J3.A33, J4.A33, J10.A33, J14.1, U5.2
/y_bus_01: J1.A32, J2.A32, J3.A32, J4.A32, J10.A32, J14.2, U5.3
/y_bus_02: J1.A31, J2.A31, J3.A31, J4.A31, J10.A31, J14.3, U5.4
/y_bus_03: J1.A30, J2.A30, J3.A30, J4.A30, J10.A30, J14.4, U5.5
/y_bus_04: J1.A29, J2.A29, J3.A29, J4.A29, J10.A29, J14.5, U5.6
/y_bus_05: J1.A28, J2.A28, J3.A28, J4.A28, J10.A28, J14.6, U5.7
/y_bus_06: J1.A27, J2.A27, J3.A27, J4.A27, J10.A27, J14.7, U5.8
/y_bus_07: J1.A26, J2.A26, J3.A26, J4.A26, J10.A26, J14.8, U5.9
/y_bus_08: J1.A25, J2.A25, J3.A25, J4.A25, J10.A25, J14.9, U6.2
/y_bus_09: J1.A24, J2.A24, J3.A24, J4.A24, J10.A24, J14.10, U6.3
/y_bus_10: J1.A23, J2.A23, J3.A23, J4.A23, J10.A23, J14.11, U6.4
/y_bus_11: J1.A22, J2.A22, J3.A22, J4.A22, J10.A22, J14.12, U6.5
/y_bus_12: J1.A21, J2.A21, J3.A21, J4.A21, J10.A21, J14.13, U6.6
/y_bus_13: J1.A20, J2.A20, J3.A20, J4.A20, J10.A20, J14.14, U6.7
/y_bus_14: J1.A19, J2.A19, J3.A19, J4.A19, J10.A19, J14.15, U6.8
/y_bus_15: J1.A18, J2.A18, J3.A18, J4.A18, J10.A18, J14.16, U6.9
/y_bus_write_gpr_a: J1.A57, J9.B5, J16.4
/y_bus_write_gpr_b: J2.A57, J9.B9, J17.4
/y_bus_write_gpr_c: J3.A57, J9.B13, J18.4
/y_bus_write_gpr_d: J4.A57, J9.B17, J19.4
/zero_flag: J9.B46, J10.B16, J28.2
/~CLK: J1.B59, J2.B59, J3.B59, J4.B59, J5.B59, J6.B59, J7.B59, J8.B59, J9.B59, J10.B59, J11.B59, J24.4, J29.B59, J30.B59, J31.B59, J32.B59
/~DBG: J1.B57, J2.B57, J3.B57, J4.B57, J5.B57, J6.B57, J7.B57, J8.B57, J9.B57, J10.B57, J11.B57, J24.2, J29.B57, J30.B57, J31.B57, J32.B57, U1.19, U2.19, U3.19, U4.19, U5.19, U6.19, U7.19, U8.19
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

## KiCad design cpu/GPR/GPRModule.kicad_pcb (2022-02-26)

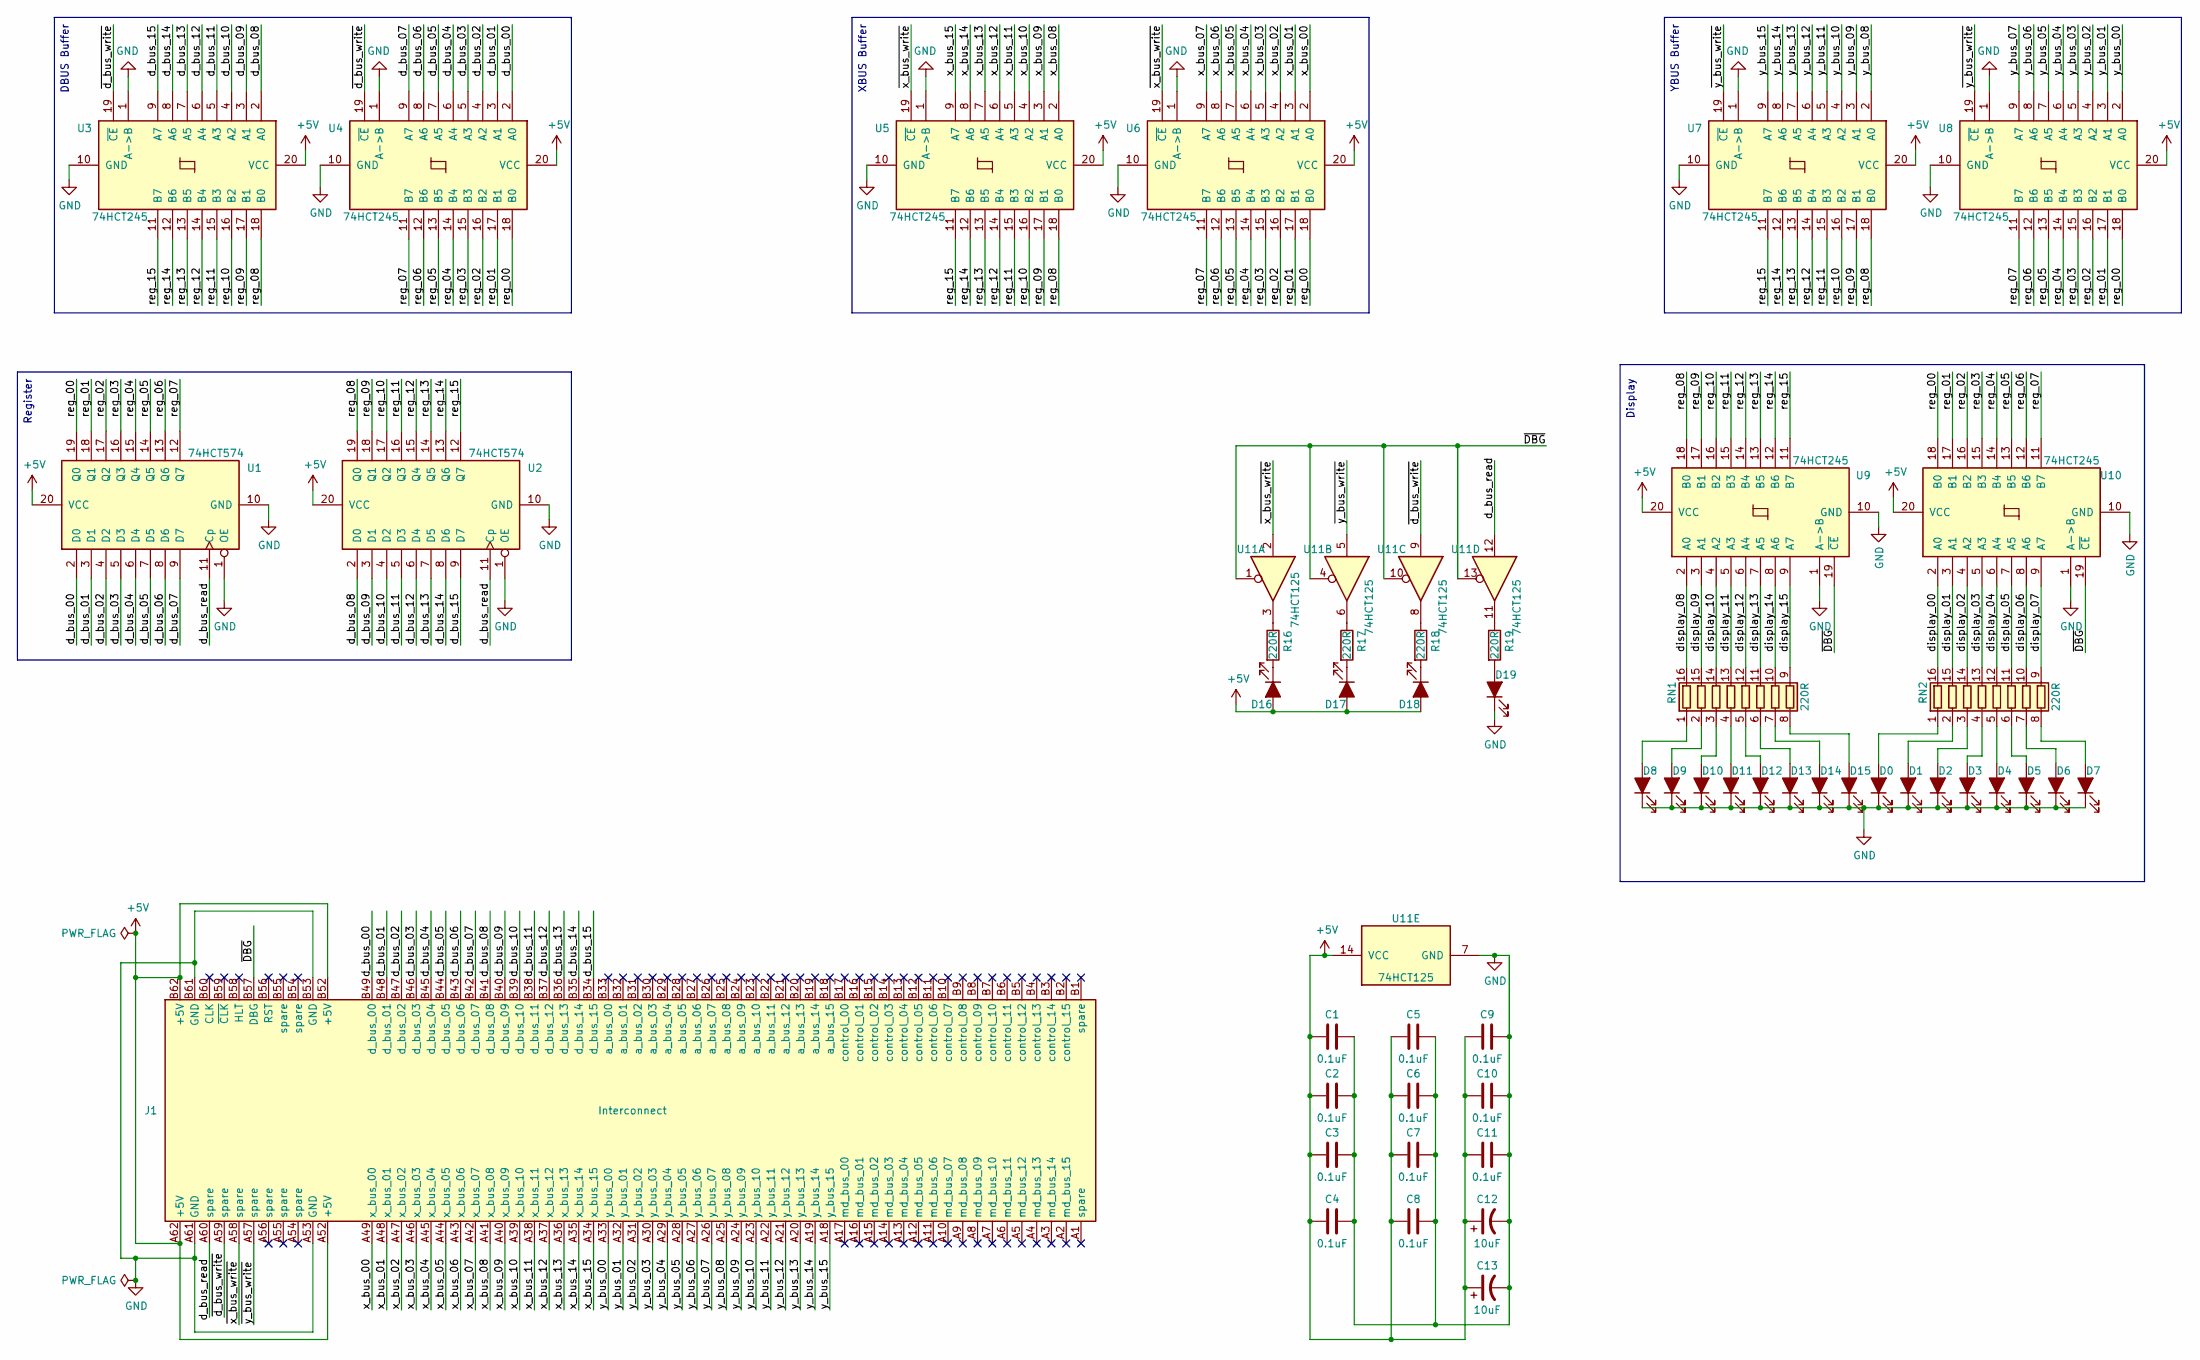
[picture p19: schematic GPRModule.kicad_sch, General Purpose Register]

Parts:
C1, C2, C3, C4, C5, C6, C7, C8, C9, C10, C11: 0.1uF; C_0603_1608Metric_Pad1.05x0.95mm_HandSolder; Digikey 399-1096-1-ND
C12, C13: 10uF; CP_Elec_4x5.4; Digikey 493-9786-1-ND
D0, D1, D2, D3, D4, D5, D6, D7, D8, D9, D10, D11, D12, D13, D14, D15: LED_RED; LED_1206_3216Metric_Pad1.42x1.75mm_HandSolder; Digikey 732-4991-1-ND
D16, D17, D18, D19: LED_AMBER; LED_1206_3216Metric_Pad1.42x1.75mm_HandSolder; Digikey 732-4994-1-ND
J1: Interconnect; BUS_PCI
R16, R17, R18, R19: 220R; R_0603_1608Metric_Pad1.05x0.95mm_HandSolder; Digikey 311-220HRCT-ND
RN1, RN2: 220R; R_Array_Convex_8x0602; Digikey Y1221CT-ND
U1, U2: 74HCT574; SOIC-20W_7.5x12.8mm_P1.27mm; Digikey 296-14871-1-ND
U3, U4, U5, U6, U7, U8, U9, U10: 74HCT245; SOIC-20W_7.5x12.8mm_P1.27mm; Digikey 296-1208-1-ND
U11: 74HCT125; SOIC-14_3.9x8.7mm_P1.27mm; Digikey 296-14546-1-ND

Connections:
+5V: C1.2, C2.2, C3.2, C4.2, C5.2, C6.2, C7.2, C8.2, C9.2, C10.2, C11.2, C12.1, C13.1, D16.2 (A), D17.2 (A), D18.2 (A), J1.A52 (+5V), J1.A62 (+5V), J1.B52 (+5V), J1.B62 (+5V), U1.20 (VCC), U2.20 (VCC), U3.20 (VCC), U4.20 (VCC), U5.20 (VCC), U6.20 (VCC), U7.20 (VCC), U8.20 (VCC), U9.20 (VCC), U10.20 (VCC), U11.14 (VCC)
/d_bus_00: J1.B49 (d_bus_00), U1.2 (D0), U4.2 (A0)
/d_bus_01: J1.B48 (d_bus_01), U1.3 (D1), U4.3 (A1)
/d_bus_02: J1.B47 (d_bus_02), U1.4 (D2), U4.4 (A2)
/d_bus_03: J1.B46 (d_bus_03), U1.5 (D3), U4.5 (A3)
/d_bus_04: J1.B45 (d_bus_04), U1.6 (D4), U4.6 (A4)
/d_bus_05: J1.B44 (d_bus_05), U1.7 (D5), U4.7 (A5)
/d_bus_06: J1.B43 (d_bus_06), U1.8 (D6), U4.8 (A6)
/d_bus_07: J1.B42 (d_bus_07), U1.9 (D7), U4.9 (A7)
/d_bus_08: J1.B41 (d_bus_08), U2.2 (D0), U3.2 (A0)
/d_bus_09: J1.B40 (d_bus_09), U2.3 (D1), U3.3 (A1)
/d_bus_10: J1.B39 (d_bus_10), U2.4 (D2), U3.4 (A2)
/d_bus_11: J1.B38 (d_bus_11), U2.5 (D3), U3.5 (A3)
/d_bus_12: J1.B37 (d_bus_12), U2.6 (D4), U3.6 (A4)
/d_bus_13: J1.B36 (d_bus_13), U2.7 (D5), U3.7 (A5)
/d_bus_14: J1.B35 (d_bus_14), U2.8 (D6), U3.8 (A6)
/d_bus_15: J1.B34 (d_bus_15), U2.9 (D7), U3.9 (A7)
/d_bus_read: J1.A60 (spare), U1.11 (Cp), U2.11 (Cp), U11.12
/display_00: RN2.16 (R1.2), U10.2 (A0)
/display_01: RN2.15 (R2.2), U10.3 (A1)
/display_02: RN2.14 (R3.2), U10.4 (A2)
/display_03: RN2.13 (R4.2), U10.5 (A3)
/display_04: RN2.12 (R5.2), U10.6 (A4)
/display_05: RN2.11 (R6.2), U10.7 (A5)
/display_06: RN2.10 (R7.2), U10.8 (A6)
/display_07: RN2.9 (R8.2), U10.9 (A7)
/display_08: RN1.16 (R1.2), U9.2 (A0)
/display_09: RN1.15 (R2.2), U9.3 (A1)
/display_10: RN1.14 (R3.2), U9.4 (A2)
/display_11: RN1.13 (R4.2), U9.5 (A3)
/display_12: RN1.12 (R5.2), U9.6 (A4)
/display_13: RN1.11 (R6.2), U9.7 (A5)
/display_14: RN1.10 (R7.2), U9.8 (A6)
/display_15: RN1.9 (R8.2), U9.9 (A7)
/reg_00: U1.19 (Q0), U4.18 (B0), U6.18 (B0), U8.18 (B0), U10.18 (B0)
/reg_01: U1.18 (Q1), U4.17 (B1), U6.17 (B1), U8.17 (B1), U10.17 (B1)
/reg_02: U1.17 (Q2), U4.16 (B2), U6.16 (B2), U8.16 (B2), U10.16 (B2)
/reg_03: U1.16 (Q3), U4.15 (B3), U6.15 (B3), U8.15 (B3), U10.15 (B3)
/reg_04: U1.15 (Q4), U4.14 (B4), U6.14 (B4), U8.14 (B4), U10.14 (B4)
/reg_05: U1.14 (Q5), U4.13 (B5), U6.13 (B5), U8.13 (B5), U10.13 (B5)
/reg_06: U1.13 (Q6), U4.12 (B6), U6.12 (B6), U8.12 (B6), U10.12 (B6)
/reg_07: U1.12 (Q7), U4.11 (B7), U6.11 (B7), U8.11 (B7), U10.11 (B7)
/reg_08: U2.19 (Q0), U3.18 (B0), U5.18 (B0), U7.18 (B0), U9.18 (B0)
/reg_09: U2.18 (Q1), U3.17 (B1), U5.17 (B1), U7.17 (B1), U9.17 (B1)
/reg_10: U2.17 (Q2), U3.16 (B2), U5.16 (B2), U7.16 (B2), U9.16 (B2)
/reg_11: U2.16 (Q3), U3.15 (B3), U5.15 (B3), U7.15 (B3), U9.15 (B3)
/reg_12: U2.15 (Q4), U3.14 (B4), U5.14 (B4), U7.14 (B4), U9.14 (B4)
/reg_13: U2.14 (Q5), U3.13 (B5), U5.13 (B5), U7.13 (B5), U9.13 (B5)
/reg_14: U2.13 (Q6), U3.12 (B6), U5.12 (B6), U7.12 (B6), U9.12 (B6)
/reg_15: U2.12 (Q7), U3.11 (B7), U5.11 (B7), U7.11 (B7), U9.11 (B7)
/x_bus_00: J1.A49 (x_bus_00), U6.2 (A0)
/x_bus_01: J1.A48 (x_bus_01), U6.3 (A1)
/x_bus_02: J1.A47 (x_bus_02), U6.4 (A2)
/x_bus_03: J1.A46 (x_bus_03), U6.5 (A3)
/x_bus_04: J1.A45 (x_bus_04), U6.6 (A4)
/x_bus_05: J1.A44 (x_bus_05), U6.7 (A5)
/x_bus_06: J1.A43 (x_bus_06), U6.8 (A6)
/x_bus_07: J1.A42 (x_bus_07), U6.9 (A7)
/x_bus_08: J1.A41 (x_bus_08), U5.2 (A0)
/x_bus_09: J1.A40 (x_bus_09), U5.3 (A1)
/x_bus_10: J1.A39 (x_bus_10), U5.4 (A2)
/x_bus_11: J1.A38 (x_bus_11), U5.5 (A3)
/x_bus_12: J1.A37 (x_bus_12), U5.6 (A4)
/x_bus_13: J1.A36 (x_bus_13), U5.7 (A5)
/x_bus_14: J1.A35 (x_bus_14), U5.8 (A6)
/x_bus_15: J1.A34 (x_bus_15), U5.9 (A7)
/y_bus_00: J1.A33 (y_bus_00), U8.2 (A0)
/y_bus_01: J1.A32 (y_bus_01), U8.3 (A1)
/y_bus_02: J1.A31 (y_bus_02), U8.4 (A2)
/y_bus_03: J1.A30 (y_bus_03), U8.5 (A3)
/y_bus_04: J1.A29 (y_bus_04), U8.6 (A4)
/y_bus_05: J1.A28 (y_bus_05), U8.7 (A5)
/y_bus_06: J1.A27 (y_bus_06), U8.8 (A6)
/y_bus_07: J1.A26 (y_bus_07), U8.9 (A7)
/y_bus_08: J1.A25 (y_bus_08), U7.2 (A0)
/y_bus_09: J1.A24 (y_bus_09), U7.3 (A1)
/y_bus_10: J1.A23 (y_bus_10), U7.4 (A2)
/y_bus_11: J1.A22 (y_bus_11), U7.5 (A3)
/y_bus_12: J1.A21 (y_bus_12), U7.6 (A4)
/y_bus_13: J1.A20 (y_bus_13), U7.7 (A5)
/y_bus_14: J1.A19 (y_bus_14), U7.8 (A6)
/y_bus_15: J1.A18 (y_bus_15), U7.9 (A7)
/~DBG: J1.B57 (DBG), U9.19 (~CE), U10.19 (~CE), U11.1, U11.4, U11.10, U11.13
/~d_bus_write: J1.A59 (spare), U3.19 (~CE), U4.19 (~CE), U11.9
/~x_bus_write: J1.A58 (spare), U5.19 (~CE), U6.19 (~CE), U11.2
/~y_bus_write: J1.A57 (spare), U7.19 (~CE), U8.19 (~CE), U11.5
GND: C1.1, C2.1, C3.1, C4.1, C5.1, C6.1, C7.1, C8.1, C9.1, C10.1, C11.1, C12.2, C13.2, D0.1 (K), D1.1 (K), D2.1 (K), D3.1 (K), D4.1 (K), D5.1 (K), D6.1 (K), D7.1 (K), D8.1 (K), D9.1 (K), D10.1 (K), D11.1 (K), D12.1 (K), D13.1 (K), D14.1 (K), D15.1 (K), D19.1 (K), J1.A53 (GND), J1.A61 (GND), J1.B53 (GND), J1.B61 (GND), U1.1 (OE), U1.10 (GND), U2.1 (OE), U2.10 (GND), U3.1 (A->B), U3.10 (GND), U4.1 (A->B), U4.10 (GND), U5.1 (A->B), U5.10 (GND), U6.1 (A->B), U6.10 (GND), U7.1 (A->B), U7.10 (GND), U8.1 (A->B), U8.10 (GND), U9.1 (A->B), U9.10 (GND), U10.1 (A->B), U10.10 (GND), U11.7 (GND)
unnamed: D0.2 (A), RN2.1 (R1.1)
unnamed: D1.2 (A), RN2.2 (R2.1)
unnamed: D2.2 (A), RN2.3 (R3.1)
unnamed: D3.2 (A), RN2.4 (R4.1)
unnamed: D4.2 (A), RN2.5 (R5.1)
unnamed: D5.2 (A), RN2.6 (R6.1)
unnamed: D6.2 (A), RN2.7 (R7.1)
unnamed: D7.2 (A), RN2.8 (R8.1)
unnamed: D8.2 (A), RN1.1 (R1.1)
unnamed: D9.2 (A), RN1.2 (R2.1)
unnamed: D10.2 (A), RN1.3 (R3.1)
unnamed: D11.2 (A), RN1.4 (R4.1)
unnamed: D12.2 (A), RN1.5 (R5.1)
unnamed: D13.2 (A), RN1.6 (R6.1)
unnamed: D14.2 (A), RN1.7 (R7.1)
unnamed: D15.2 (A), RN1.8 (R8.1)
unnamed: D16.1 (K), R16.2
unnamed: D17.1 (K), R17.2
unnamed: D18.1 (K), R18.2
unnamed: D19.2 (A), R19.2
unnamed: R16.1, U11.3
unnamed: R17.1, U11.6
unnamed: R18.1, U11.8
unnamed: R19.1, U11.11

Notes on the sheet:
YBUS Buffer
Register
XBUS Buffer
DBUS Buffer
Display

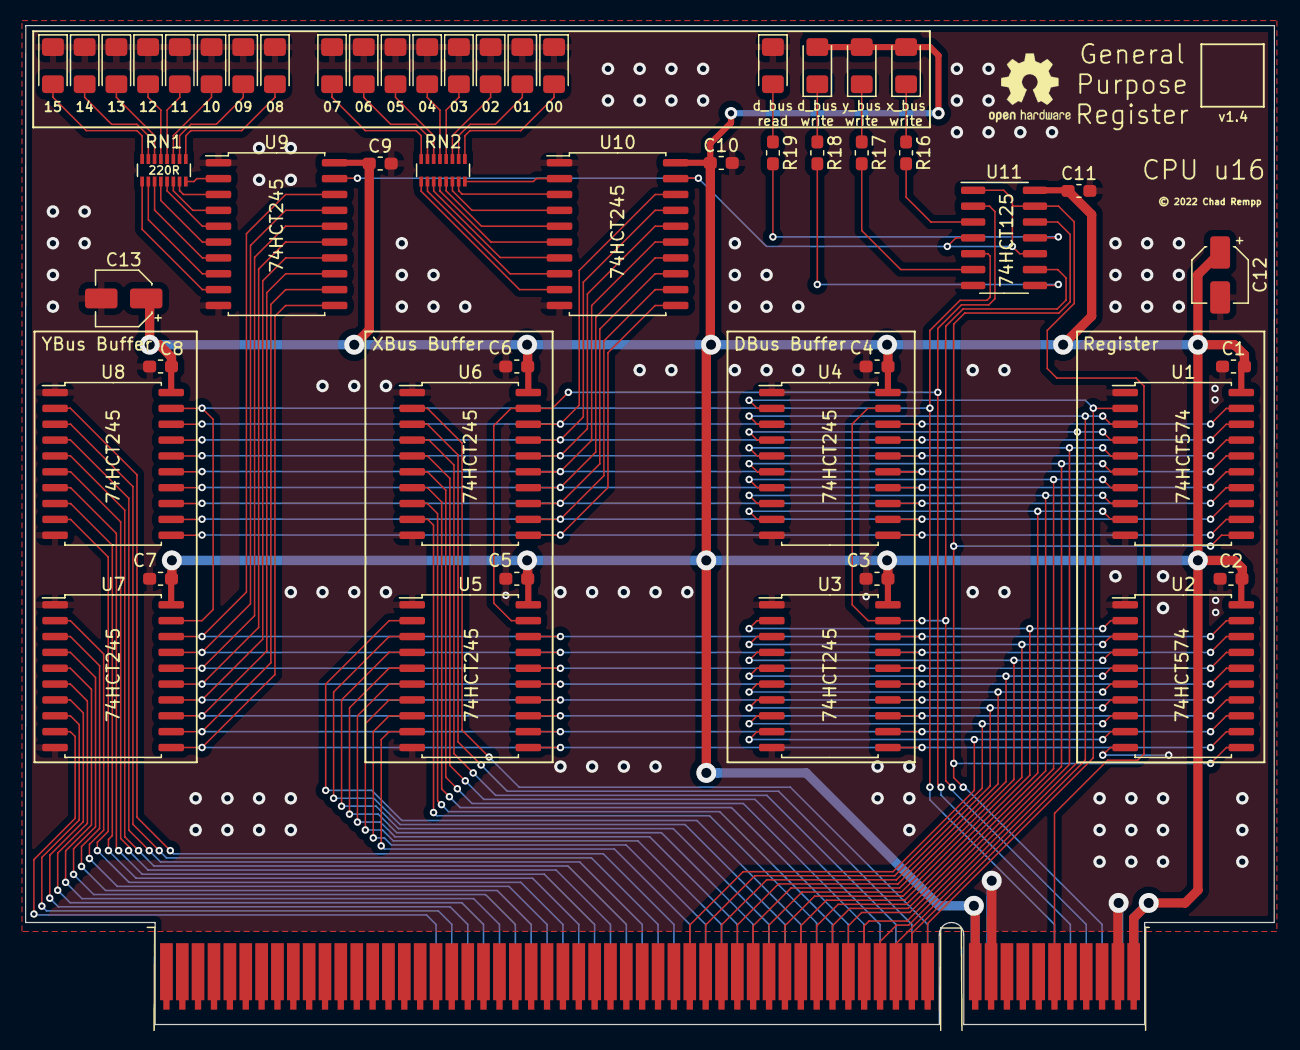
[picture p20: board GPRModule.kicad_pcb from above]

Board: 2 copper layers, 100.0 x 80.0 mm, 51 parts (0 on the bottom side), 111 nets.

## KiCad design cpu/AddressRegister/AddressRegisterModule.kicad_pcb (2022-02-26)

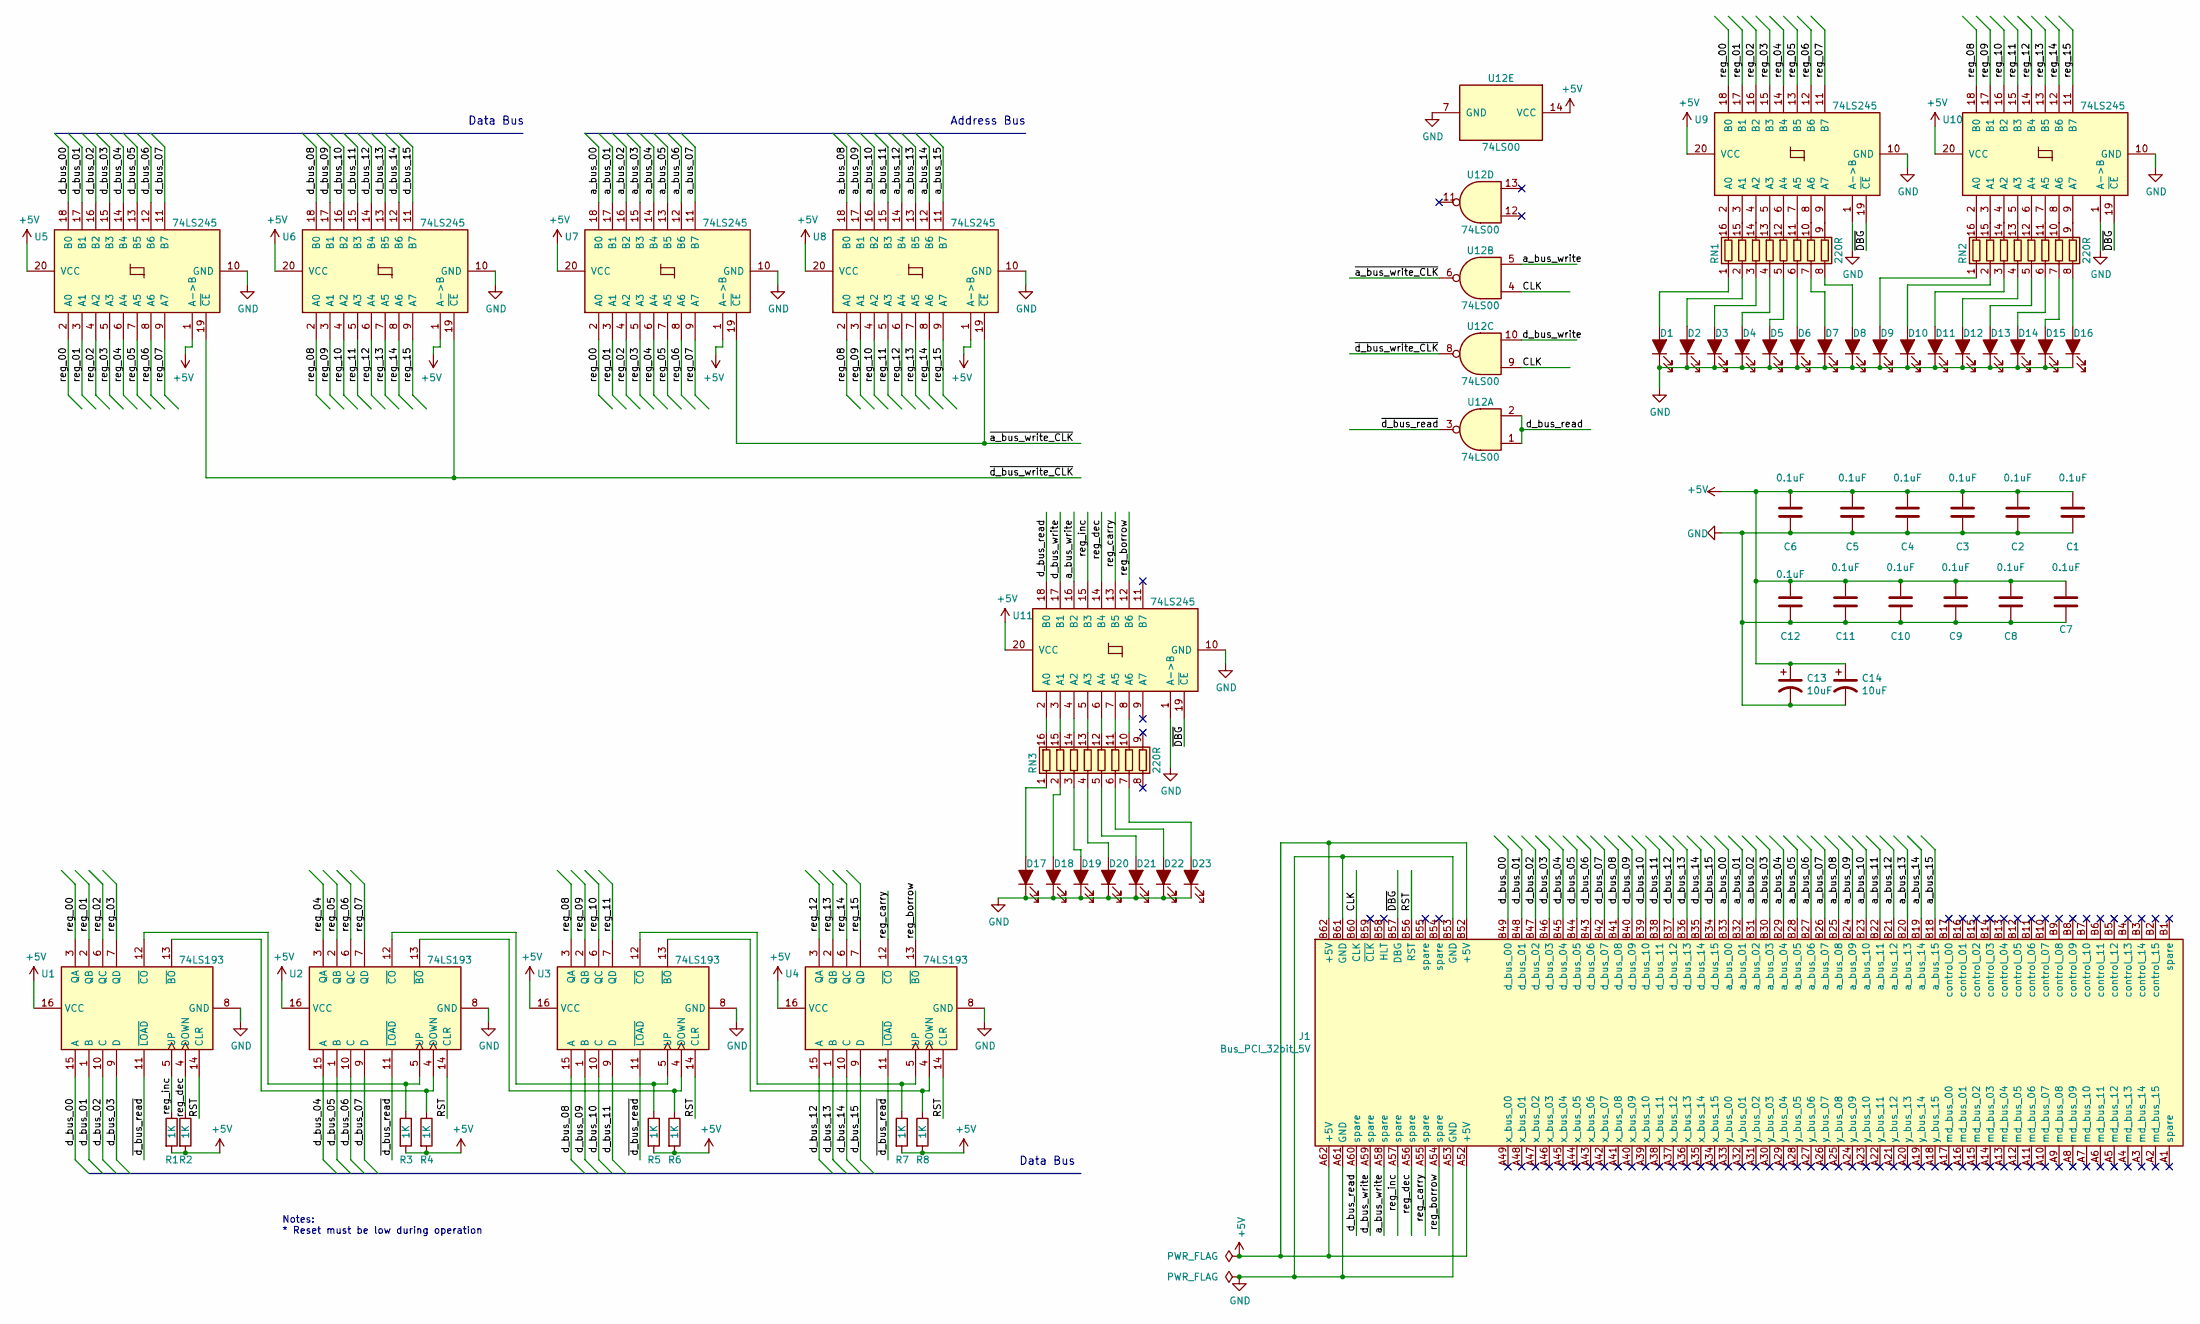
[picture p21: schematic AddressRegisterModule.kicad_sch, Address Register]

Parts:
C1, C2, C3, C4, C5, C6, C7, C8, C9, C10, C11, C12: 0.1uF; C_0603_1608Metric_Pad1.05x0.95mm_HandSolder; Digikey 399-1096-1-ND
C13, C14: 10uF; CP_Elec_4x5.4; Digikey 493-9786-1-ND
D1, D2, D3, D4, D5, D6, D7, D8, D9, D10, D11, D12, D13, D14, D15, D16: D_RED; LED_1206_3216Metric_Pad1.42x1.75mm_HandSolder; Digikey 732-4991-1-ND
D17, D18, D19, D20, D21, D22, D23: D_AMBER; LED_1206_3216Metric_Pad1.42x1.75mm_HandSolder; Digikey 732-4994-1-ND
J1: Bus_PCI_32bit_5V; BUS_PCI
R1, R2, R3, R4, R5, R6, R7, R8: 1K; R_0603_1608Metric_Pad0.98x0.95mm_HandSolder
RN1, RN2, RN3: 220R; R_Array_Convex_8x0602; Digikey Y1221CT-ND
U1, U2, U3, U4: 74LS193; SOIC-16_3.9x9.9mm_P1.27mm; Digikey 1727-7973-1-ND
U5, U6, U7, U8, U9, U10, U11: 74LS245; SOIC-20W_7.5x12.8mm_P1.27mm; Digikey 296-1208-1-ND
U12: 74LS00; SOIC-14_3.9x8.7mm_P1.27mm; Digikey 296-14860-1-ND

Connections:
+5V: C1.2, C2.2, C3.2, C4.2, C5.2, C6.2, C7.2, C8.2, C9.2, C10.2, C11.2, C12.2, C13.1, C14.1, J1.A52 (+5V), J1.A62 (+5V), J1.B52 (+5V), J1.B62 (+5V), R1.2, R2.2, R3.2, R4.2, R5.2, R6.2, R7.2, R8.2, U1.16 (VCC), U2.16 (VCC), U3.16 (VCC), U4.16 (VCC), U5.1 (A->B), U5.20 (VCC), U6.1 (A->B), U6.20 (VCC), U7.1 (A->B), U7.20 (VCC), U8.1 (A->B), U8.20 (VCC), U9.20 (VCC), U10.20 (VCC), U11.20 (VCC), U12.14 (VCC)
/CLK: J1.B60 (CLK), U12.4, U12.9
/RST: J1.B56 (RST), U1.14 (CLR), U2.14 (CLR), U3.14 (CLR), U4.14 (CLR)
/a_bus_00: J1.B33 (a_bus_00), U7.18 (B0)
/a_bus_01: J1.B32 (a_bus_01), U7.17 (B1)
/a_bus_02: J1.B31 (a_bus_02), U7.16 (B2)
/a_bus_03: J1.B30 (a_bus_03), U7.15 (B3)
/a_bus_04: J1.B29 (a_bus_04), U7.14 (B4)
/a_bus_05: J1.B28 (a_bus_05), U7.13 (B5)
/a_bus_06: J1.B27 (a_bus_06), U7.12 (B6)
/a_bus_07: J1.B26 (a_bus_07), U7.11 (B7)
/a_bus_08: J1.B25 (a_bus_08), U8.18 (B0)
/a_bus_09: J1.B24 (a_bus_09), U8.17 (B1)
/a_bus_10: J1.B23 (a_bus_10), U8.16 (B2)
/a_bus_11: J1.B22 (a_bus_11), U8.15 (B3)
/a_bus_12: J1.B21 (a_bus_12), U8.14 (B4)
/a_bus_13: J1.B20 (a_bus_13), U8.13 (B5)
/a_bus_14: J1.B19 (a_bus_14), U8.12 (B6)
/a_bus_15: J1.B18 (a_bus_15), U8.11 (B7)
/a_bus_write: J1.A58 (spare), U11.16 (B2), U12.5
/d_bus_00: J1.B49 (d_bus_00), U1.15 (A), U5.18 (B0)
/d_bus_01: J1.B48 (d_bus_01), U1.1 (B), U5.17 (B1)
/d_bus_02: J1.B47 (d_bus_02), U1.10 (C), U5.16 (B2)
/d_bus_03: J1.B46 (d_bus_03), U1.9 (D), U5.15 (B3)
/d_bus_04: J1.B45 (d_bus_04), U2.15 (A), U5.14 (B4)
/d_bus_05: J1.B44 (d_bus_05), U2.1 (B), U5.13 (B5)
/d_bus_06: J1.B43 (d_bus_06), U2.10 (C), U5.12 (B6)
/d_bus_07: J1.B42 (d_bus_07), U2.9 (D), U5.11 (B7)
/d_bus_08: J1.B41 (d_bus_08), U3.15 (A), U6.18 (B0)
/d_bus_09: J1.B40 (d_bus_09), U3.1 (B), U6.17 (B1)
/d_bus_10: J1.B39 (d_bus_10), U3.10 (C), U6.16 (B2)
/d_bus_11: J1.B38 (d_bus_11), U3.9 (D), U6.15 (B3)
/d_bus_12: J1.B37 (d_bus_12), U4.15 (A), U6.14 (B4)
/d_bus_13: J1.B36 (d_bus_13), U4.1 (B), U6.13 (B5)
/d_bus_14: J1.B35 (d_bus_14), U4.10 (C), U6.12 (B6)
/d_bus_15: J1.B34 (d_bus_15), U4.9 (D), U6.11 (B7)
/d_bus_read: J1.A60 (spare), U11.18 (B0), U12.1, U12.2
/d_bus_write: J1.A59 (spare), U11.17 (B1), U12.10
/reg_00: U1.3 (QA), U5.2 (A0), U7.2 (A0), U9.18 (B0)
/reg_01: U1.2 (QB), U5.3 (A1), U7.3 (A1), U9.17 (B1)
/reg_02: U1.6 (QC), U5.4 (A2), U7.4 (A2), U9.16 (B2)
/reg_03: U1.7 (QD), U5.5 (A3), U7.5 (A3), U9.15 (B3)
/reg_04: U2.3 (QA), U5.6 (A4), U7.6 (A4), U9.14 (B4)
/reg_05: U2.2 (QB), U5.7 (A5), U7.7 (A5), U9.13 (B5)
/reg_06: U2.6 (QC), U5.8 (A6), U7.8 (A6), U9.12 (B6)
/reg_07: U2.7 (QD), U5.9 (A7), U7.9 (A7), U9.11 (B7)
/reg_08: U3.3 (QA), U6.2 (A0), U8.2 (A0), U10.18 (B0)
/reg_09: U3.2 (QB), U6.3 (A1), U8.3 (A1), U10.17 (B1)
/reg_10: U3.6 (QC), U6.4 (A2), U8.4 (A2), U10.16 (B2)
/reg_11: U3.7 (QD), U6.5 (A3), U8.5 (A3), U10.15 (B3)
/reg_12: U4.3 (QA), U6.6 (A4), U8.6 (A4), U10.14 (B4)
/reg_13: U4.2 (QB), U6.7 (A5), U8.7 (A5), U10.13 (B5)
/reg_14: U4.6 (QC), U6.8 (A6), U8.8 (A6), U10.12 (B6)
/reg_15: U4.7 (QD), U6.9 (A7), U8.9 (A7), U10.11 (B7)
/reg_borrow: J1.A54 (spare), U4.13 (~BO), U11.12 (B6)
/reg_carry: J1.A55 (spare), U4.12 (~CO), U11.13 (B5)
/reg_dec: J1.A56 (spare), R2.1, U1.4 (DOWN), U11.14 (B4)
/reg_inc: J1.A57 (spare), R1.1, U1.5 (UP), U11.15 (B3)
/~DBG: J1.B57 (DBG), U9.19 (~CE), U10.19 (~CE), U11.19 (~CE)
/~a_bus_write_CLK: U7.19 (~CE), U8.19 (~CE), U12.6
/~d_bus_read: U1.11 (~LOAD), U2.11 (~LOAD), U3.11 (~LOAD), U4.11 (~LOAD), U12.3
/~d_bus_write_CLK: U5.19 (~CE), U6.19 (~CE), U12.8
GND: C1.1, C2.1, C3.1, C4.1, C5.1, C6.1, C7.1, C8.1, C9.1, C10.1, C11.1, C12.1, C13.2, C14.2, D1.1 (K), D2.1 (K), D3.1 (K), D4.1 (K), D5.1 (K), D6.1 (K), D7.1 (K), D8.1 (K), D9.1 (K), D10.1 (K), D11.1 (K), D12.1 (K), D13.1 (K), D14.1 (K), D15.1 (K), D16.1 (K), D17.1 (K), D18.1 (K), D19.1 (K), D20.1 (K), D21.1 (K), D22.1 (K), D23.1 (K), J1.A53 (GND), J1.A61 (GND), J1.B53 (GND), J1.B61 (GND), U1.8 (GND), U2.8 (GND), U3.8 (GND), U4.8 (GND), U5.10 (GND), U6.10 (GND), U7.10 (GND), U8.10 (GND), U9.1 (A->B), U9.10 (GND), U10.1 (A->B), U10.10 (GND), U11.1 (A->B), U11.10 (GND), U12.7 (GND)
unnamed: D1.2 (A), RN1.1 (R1.1)
unnamed: D2.2 (A), RN1.2 (R2.1)
unnamed: D3.2 (A), RN1.3 (R3.1)
unnamed: D4.2 (A), RN1.4 (R4.1)
unnamed: D5.2 (A), RN1.5 (R5.1)
unnamed: D6.2 (A), RN1.6 (R6.1)
unnamed: D7.2 (A), RN1.7 (R7.1)
unnamed: D8.2 (A), RN1.8 (R8.1)
unnamed: D9.2 (A), RN2.1 (R1.1)
unnamed: D10.2 (A), RN2.2 (R2.1)
unnamed: D11.2 (A), RN2.3 (R3.1)
unnamed: D12.2 (A), RN2.4 (R4.1)
unnamed: D13.2 (A), RN2.5 (R5.1)
unnamed: D14.2 (A), RN2.6 (R6.1)
unnamed: D15.2 (A), RN2.7 (R7.1)
unnamed: D16.2 (A), RN2.8 (R8.1)
unnamed: D17.2 (A), RN3.1 (R1.1)
unnamed: D18.2 (A), RN3.2 (R2.1)
unnamed: D19.2 (A), RN3.3 (R3.1)
unnamed: D20.2 (A), RN3.4 (R4.1)
unnamed: D21.2 (A), RN3.5 (R5.1)
unnamed: D22.2 (A), RN3.6 (R6.1)
unnamed: D23.2 (A), RN3.7 (R7.1)
unnamed: R3.1, U1.12 (~CO), U2.5 (UP)
unnamed: R4.1, U1.13 (~BO), U2.4 (DOWN)
unnamed: R5.1, U2.12 (~CO), U3.5 (UP)
unnamed: R6.1, U2.13 (~BO), U3.4 (DOWN)
unnamed: R7.1, U3.12 (~CO), U4.5 (UP)
unnamed: R8.1, U3.13 (~BO), U4.4 (DOWN)
unnamed: RN1.9 (R8.2), U9.9 (A7)
unnamed: RN1.10 (R7.2), U9.8 (A6)
unnamed: RN1.11 (R6.2), U9.7 (A5)
unnamed: RN1.12 (R5.2), U9.6 (A4)
unnamed: RN1.13 (R4.2), U9.5 (A3)
unnamed: RN1.14 (R3.2), U9.4 (A2)
unnamed: RN1.15 (R2.2), U9.3 (A1)
unnamed: RN1.16 (R1.2), U9.2 (A0)
unnamed: RN2.9 (R8.2), U10.9 (A7)
unnamed: RN2.10 (R7.2), U10.8 (A6)
unnamed: RN2.11 (R6.2), U10.7 (A5)
unnamed: RN2.12 (R5.2), U10.6 (A4)
unnamed: RN2.13 (R4.2), U10.5 (A3)
unnamed: RN2.14 (R3.2), U10.4 (A2)
unnamed: RN2.15 (R2.2), U10.3 (A1)
unnamed: RN2.16 (R1.2), U10.2 (A0)
unnamed: RN3.10 (R7.2), U11.8 (A6)
unnamed: RN3.11 (R6.2), U11.7 (A5)
unnamed: RN3.12 (R5.2), U11.6 (A4)
unnamed: RN3.13 (R4.2), U11.5 (A3)
unnamed: RN3.14 (R3.2), U11.4 (A2)
unnamed: RN3.15 (R2.2), U11.3 (A1)
unnamed: RN3.16 (R1.2), U11.2 (A0)

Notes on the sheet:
Data Bus
Notes: * Reset must be low during operation
Address Bus

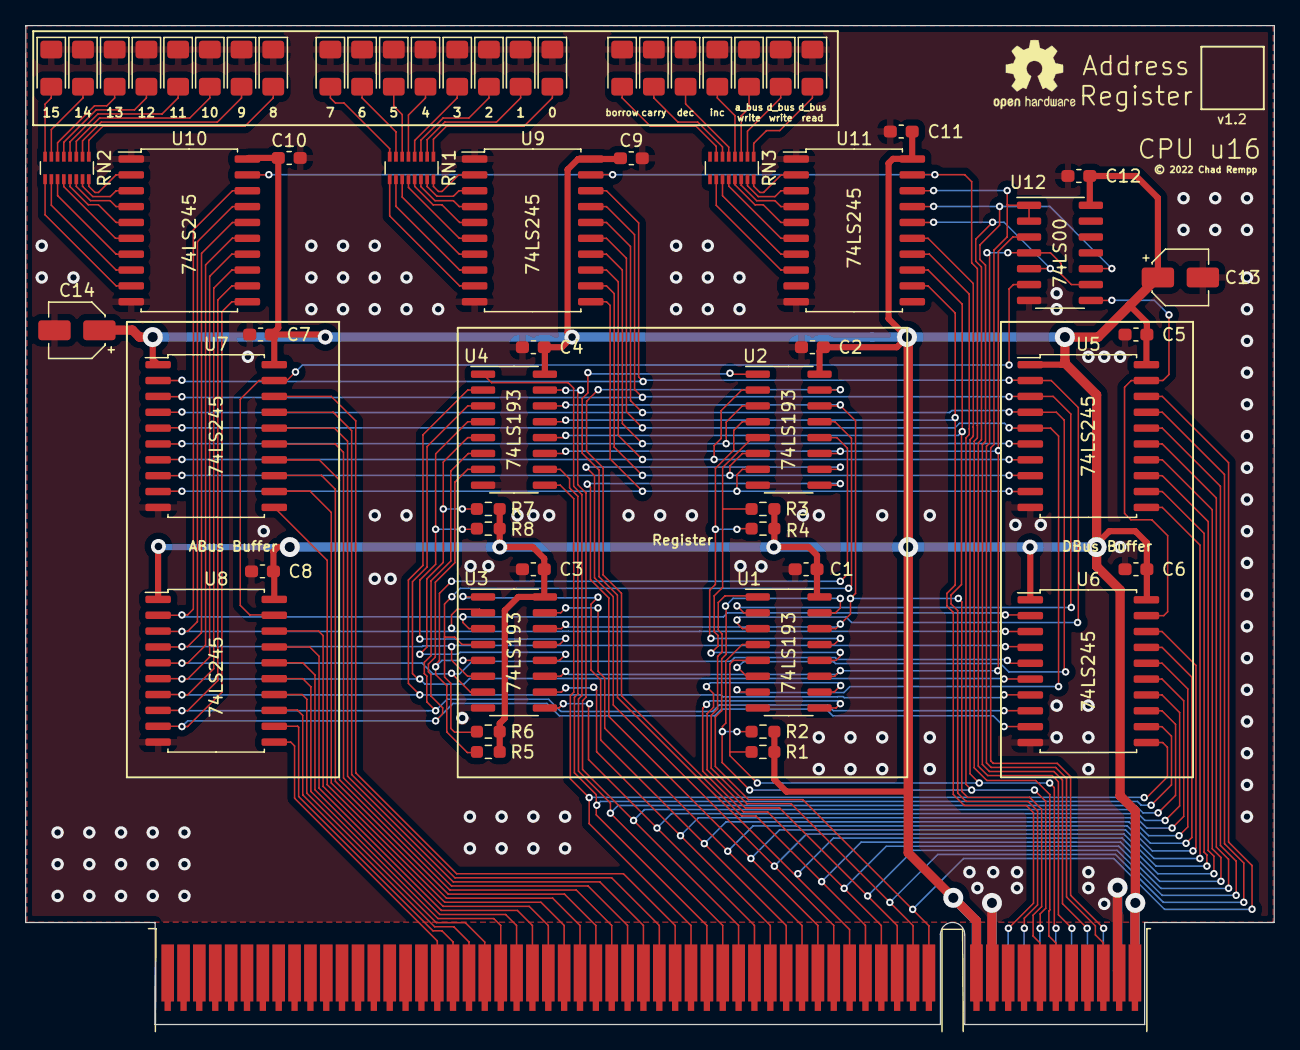
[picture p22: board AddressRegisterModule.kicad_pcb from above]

Board: 2 copper layers, 100.0 x 80.0 mm, 61 parts (0 on the bottom side), 115 nets.

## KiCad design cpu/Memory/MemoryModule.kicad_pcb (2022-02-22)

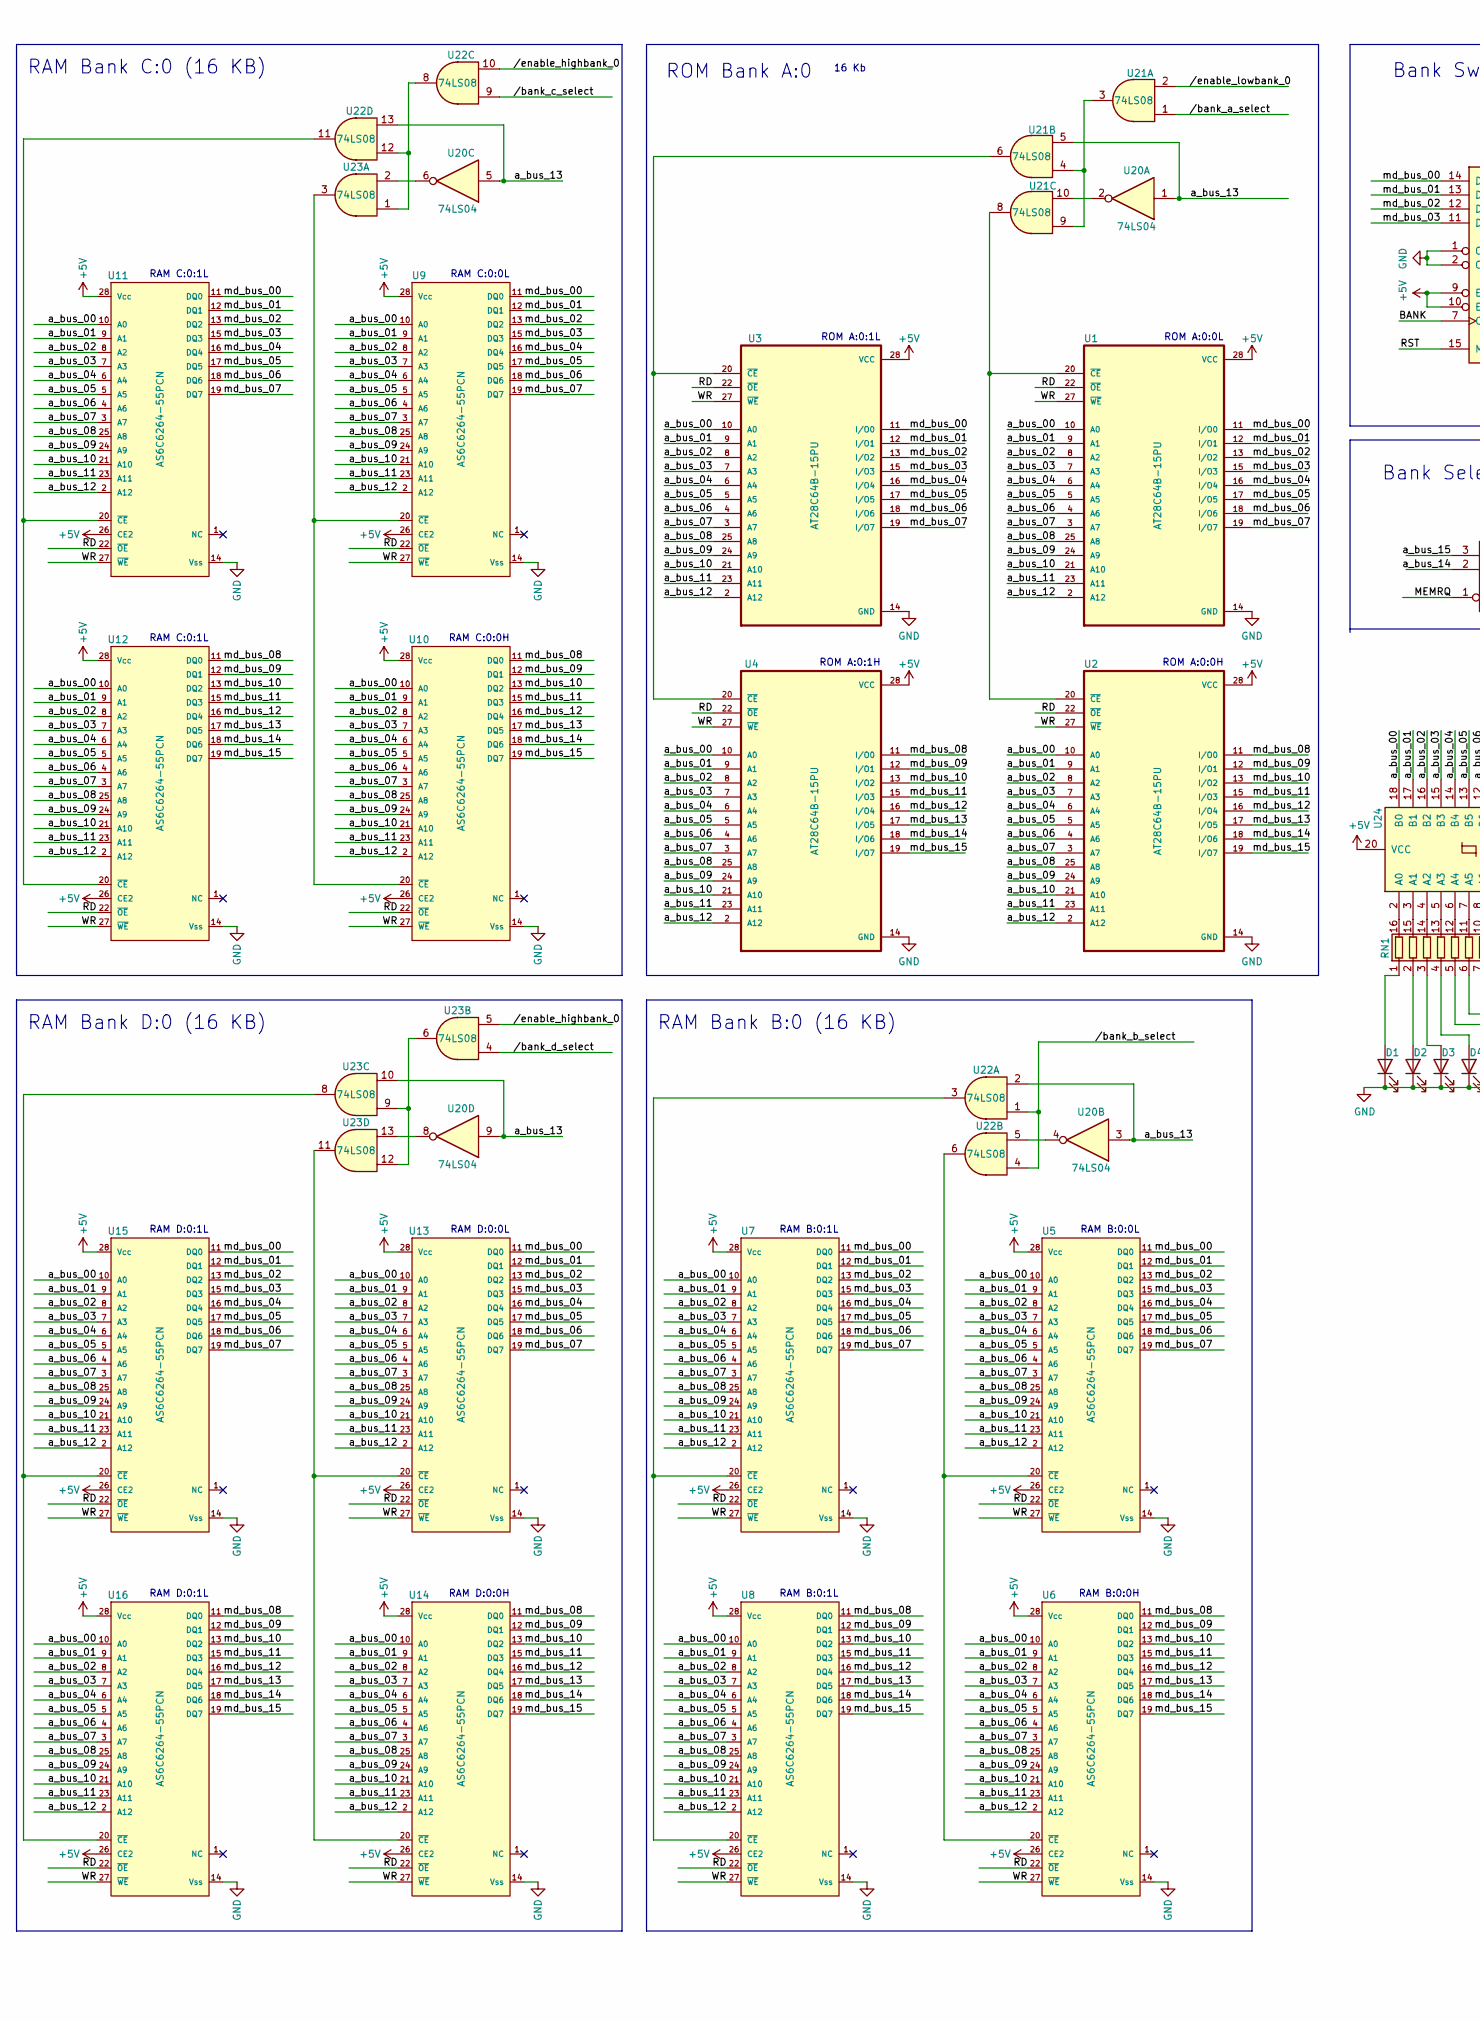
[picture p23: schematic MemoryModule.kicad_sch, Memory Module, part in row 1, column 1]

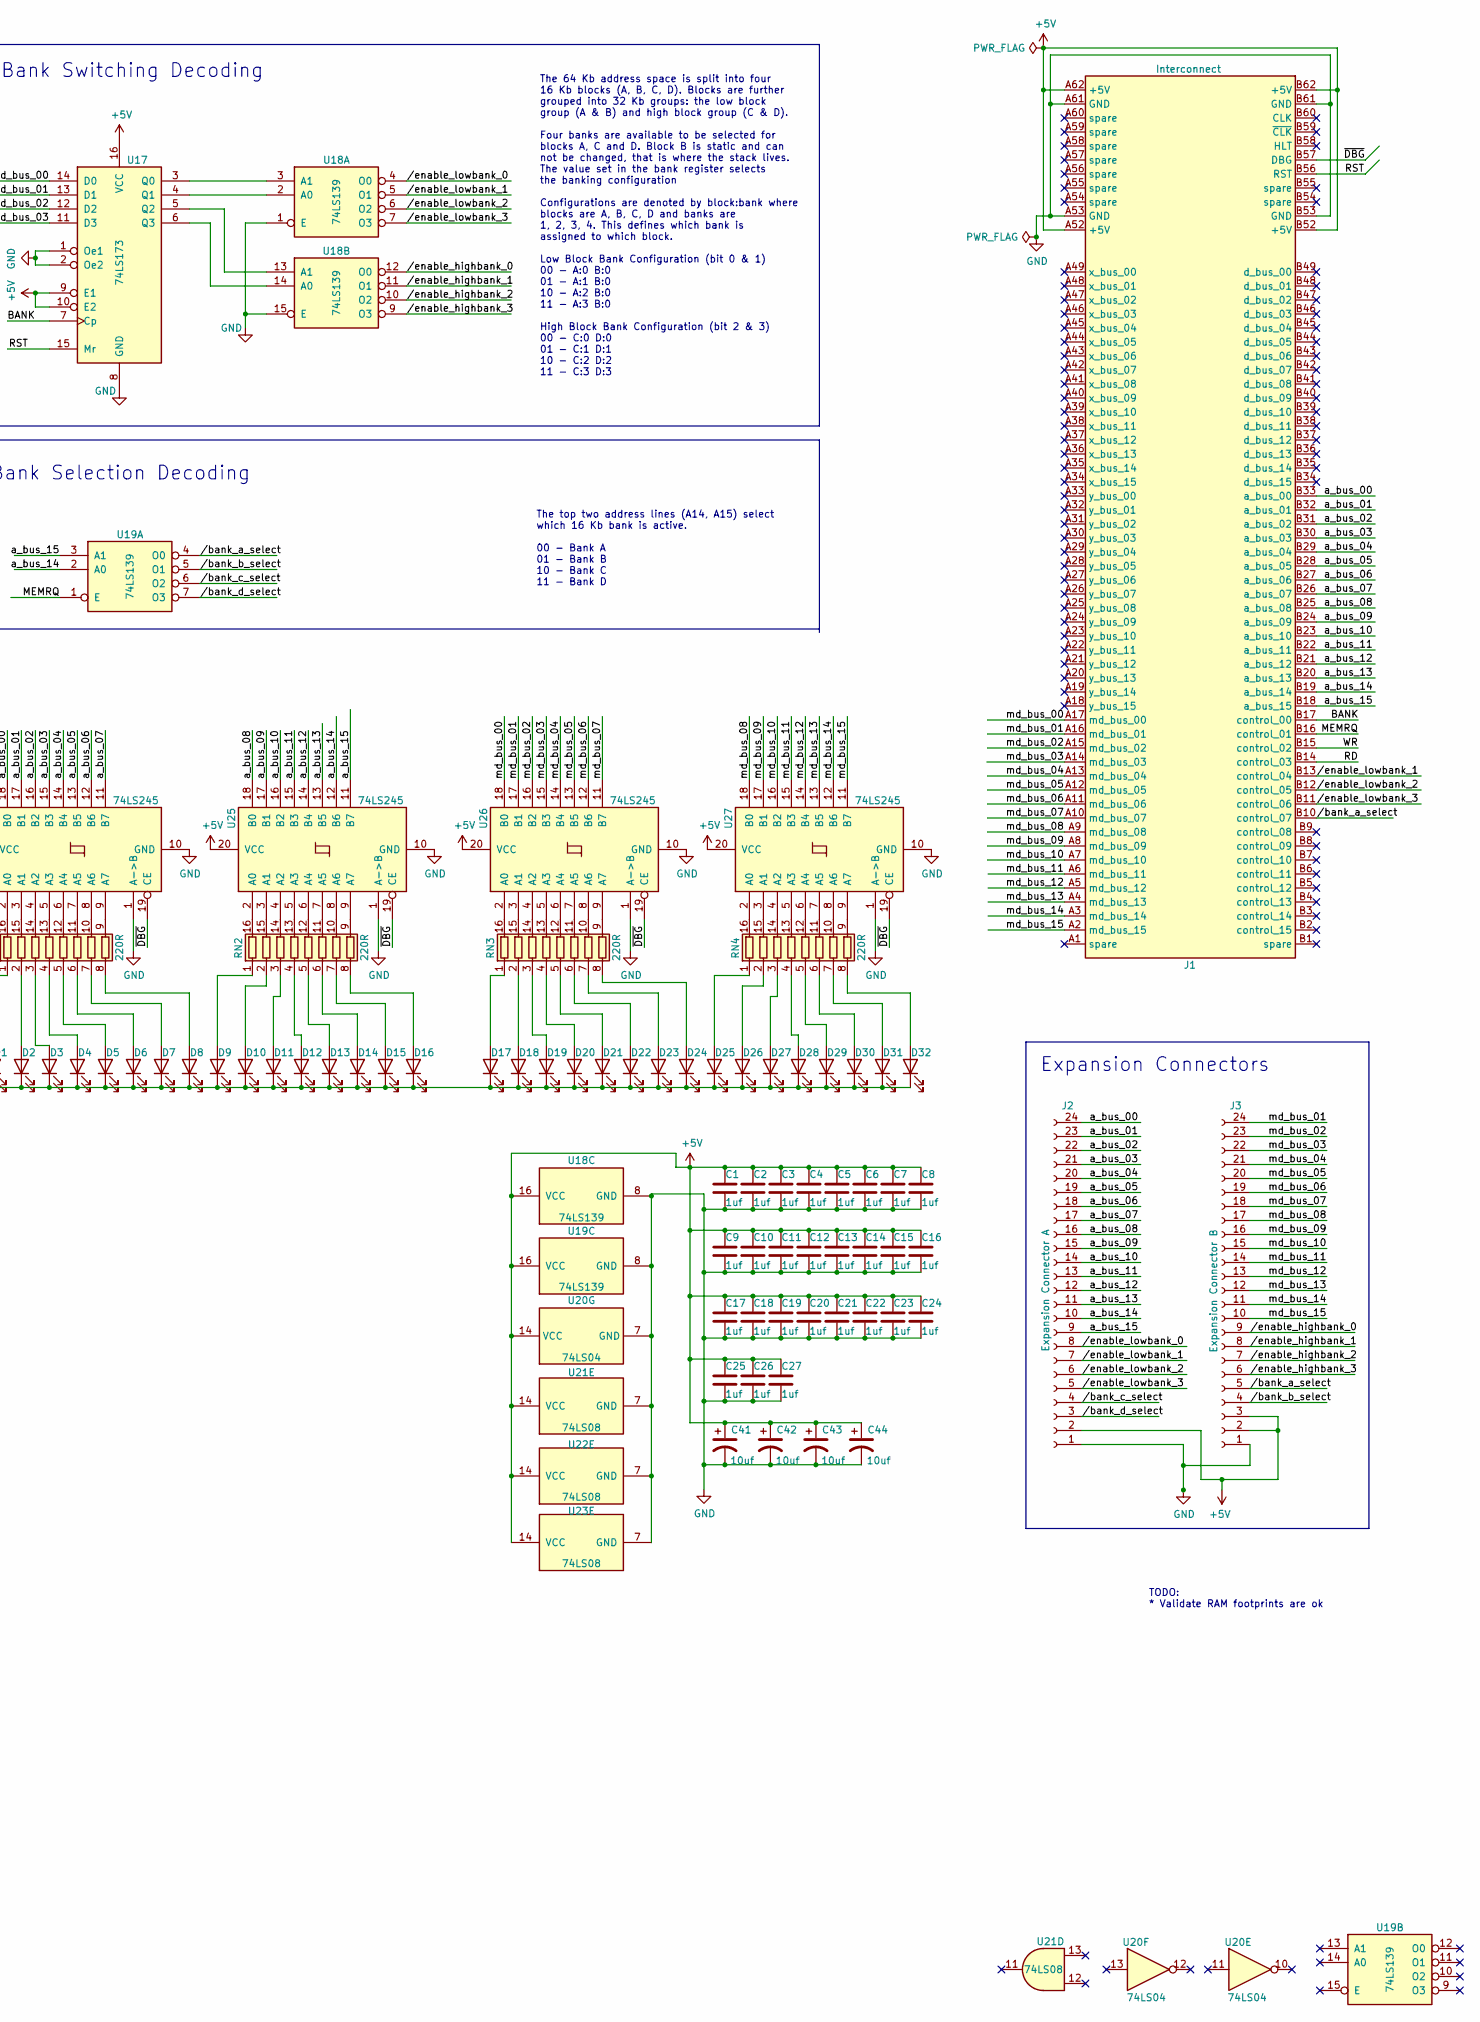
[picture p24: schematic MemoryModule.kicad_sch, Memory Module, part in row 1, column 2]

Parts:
C1, C2, C3, C4, C5, C6, C7, C8, C9, C10, C11, C12, C13, C14, C15, C16, C17, C18, C19, C20, C21, C22, C23, C24, C25, C26, C27: 1uf; C_0603_1608Metric_Pad1.08x0.95mm_HandSolder
C41, C42, C43, C44: 10uf; CP_Elec_4x5.4
D1, D2, D3, D4, D5, D6, D7, D8, D9, D10, D11, D12, D13, D14, D15, D16, D17, D18, D19, D20, D21, D22, D23, D24, D25, D26, D27, D28, D29, D30, D31, D32: LED; LED_1206_3216Metric_Pad1.42x1.75mm_HandSolder
J1: Interconnect; BUS_PCI
J2: Expansion Connector A; PinHeader_1x24_P1.27mm_Vertical
J3: Expansion Connector B; PinHeader_1x24_P1.27mm_Vertical
RN1, RN2, RN3, RN4: 220R; R_Array_Convex_8x0602; Digikey Y1221CT-ND
U1, U2, U3, U4: AT28C64B-15PU; DIP-28_W15.24mm
U5, U6, U7, U8, U9, U10, U11, U12, U13, U14, U15, U16: AS6C6264-55PCN; SOIC-28W_7.5x18.7mm_P1.27mm; mouser part number 913-AS6C6264-55PCN; digikey description IC SRAM 64K PARALLEL 28DIP
U17: 74LS173; SOIC-16_3.9x9.9mm_P1.27mm
U18, U19: 74LS139; SOIC-16_3.9x9.9mm_P1.27mm
U20: 74LS04; SOIC-14_3.9x8.7mm_P1.27mm
U21, U22, U23: 74LS08; SOIC-14_3.9x8.7mm_P1.27mm
U24, U25, U26, U27: 74LS245; SOIC-20W_7.5x12.8mm_P1.27mm; Digikey 296-1208-1-ND

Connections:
+5V: C1.1, C2.1, C3.1, C4.1, C5.1, C6.1, C7.1, C8.1, C9.1, C10.1, C11.1, C12.1, C13.1, C14.1, C15.1, C16.1, C17.1, C18.1, C19.1, C20.1, C21.1, C22.1, C23.1, C24.1, C25.1, C26.1, C27.1, C41.1, C42.1, C43.1, C44.1, J1.A52 (+5V), J1.A62 (+5V), J1.B52 (+5V), J1.B62 (+5V), J2.2, J3.2, J3.3, U1.28 (VCC), U2.28 (VCC), U3.28 (VCC), U4.28 (VCC), U5.26 (CE2), U5.28 (Vcc), U6.26 (CE2), U6.28 (Vcc), U7.26 (CE2), U7.28 (Vcc), U8.26 (CE2), U8.28 (Vcc), U9.26 (CE2), U9.28 (Vcc), U10.26 (CE2), U10.28 (Vcc), U11.26 (CE2), U11.28 (Vcc), U12.26 (CE2), U12.28 (Vcc), U13.26 (CE2), U13.28 (Vcc), U14.26 (CE2), U14.28 (Vcc), U15.26 (CE2), U15.28 (Vcc), U16.26 (CE2), U16.28 (Vcc), U17.9 (E1), U17.10 (E2), U17.16 (VCC), U18.16 (VCC), U19.16 (VCC), U20.14 (VCC), U21.14 (VCC), U22.14 (VCC), U23.14 (VCC), U24.20 (VCC), U25.20 (VCC), U26.20 (VCC), U27.20 (VCC)
/BANK: J1.B17 (control_00), U17.7 (Cp)
/MEMRQ: J1.B16 (control_01), U19.1 (E)
/RD: J1.B14 (control_03), U1.22 (~OE), U2.22 (~OE), U3.22 (~OE), U4.22 (~OE), U5.22 (~OE), U6.22 (~OE), U7.22 (~OE), U8.22 (~OE), U9.22 (~OE), U10.22 (~OE), U11.22 (~OE), U12.22 (~OE), U13.22 (~OE), U14.22 (~OE), U15.22 (~OE), U16.22 (~OE)
/RST: J1.B56 (RST), U17.15 (Mr)
/WR: J1.B15 (control_02), U1.27 (~WE), U2.27 (~WE), U3.27 (~WE), U4.27 (~WE), U5.27 (~WE), U6.27 (~WE), U7.27 (~WE), U8.27 (~WE), U9.27 (~WE), U10.27 (~WE), U11.27 (~WE), U12.27 (~WE), U13.27 (~WE), U14.27 (~WE), U15.27 (~WE), U16.27 (~WE)
/a_bus_00: J1.B33 (a_bus_00), J2.24, U1.10 (A0), U2.10 (A0), U3.10 (A0), U4.10 (A0), U5.10 (A0), U6.10 (A0), U7.10 (A0), U8.10 (A0), U9.10 (A0), U10.10 (A0), U11.10 (A0), U12.10 (A0), U13.10 (A0), U14.10 (A0), U15.10 (A0), U16.10 (A0), U24.18 (B0)
/a_bus_01: J1.B32 (a_bus_01), J2.23, U1.9 (A1), U2.9 (A1), U3.9 (A1), U4.9 (A1), U5.9 (A1), U6.9 (A1), U7.9 (A1), U8.9 (A1), U9.9 (A1), U10.9 (A1), U11.9 (A1), U12.9 (A1), U13.9 (A1), U14.9 (A1), U15.9 (A1), U16.9 (A1), U24.17 (B1)
/a_bus_02: J1.B31 (a_bus_02), J2.22, U1.8 (A2), U2.8 (A2), U3.8 (A2), U4.8 (A2), U5.8 (A2), U6.8 (A2), U7.8 (A2), U8.8 (A2), U9.8 (A2), U10.8 (A2), U11.8 (A2), U12.8 (A2), U13.8 (A2), U14.8 (A2), U15.8 (A2), U16.8 (A2), U24.16 (B2)
/a_bus_03: J1.B30 (a_bus_03), J2.21, U1.7 (A3), U2.7 (A3), U3.7 (A3), U4.7 (A3), U5.7 (A3), U6.7 (A3), U7.7 (A3), U8.7 (A3), U9.7 (A3), U10.7 (A3), U11.7 (A3), U12.7 (A3), U13.7 (A3), U14.7 (A3), U15.7 (A3), U16.7 (A3), U24.15 (B3)
/a_bus_04: J1.B29 (a_bus_04), J2.20, U1.6 (A4), U2.6 (A4), U3.6 (A4), U4.6 (A4), U5.6 (A4), U6.6 (A4), U7.6 (A4), U8.6 (A4), U9.6 (A4), U10.6 (A4), U11.6 (A4), U12.6 (A4), U13.6 (A4), U14.6 (A4), U15.6 (A4), U16.6 (A4), U24.14 (B4)
/a_bus_05: J1.B28 (a_bus_05), J2.19, U1.5 (A5), U2.5 (A5), U3.5 (A5), U4.5 (A5), U5.5 (A5), U6.5 (A5), U7.5 (A5), U8.5 (A5), U9.5 (A5), U10.5 (A5), U11.5 (A5), U12.5 (A5), U13.5 (A5), U14.5 (A5), U15.5 (A5), U16.5 (A5), U24.13 (B5)
/a_bus_06: J1.B27 (a_bus_06), J2.18, U1.4 (A6), U2.4 (A6), U3.4 (A6), U4.4 (A6), U5.4 (A6), U6.4 (A6), U7.4 (A6), U8.4 (A6), U9.4 (A6), U10.4 (A6), U11.4 (A6), U12.4 (A6), U13.4 (A6), U14.4 (A6), U15.4 (A6), U16.4 (A6), U24.12 (B6)
/a_bus_07: J1.B26 (a_bus_07), J2.17, U1.3 (A7), U2.3 (A7), U3.3 (A7), U4.3 (A7), U5.3 (A7), U6.3 (A7), U7.3 (A7), U8.3 (A7), U9.3 (A7), U10.3 (A7), U11.3 (A7), U12.3 (A7), U13.3 (A7), U14.3 (A7), U15.3 (A7), U16.3 (A7), U24.11 (B7)
/a_bus_08: J1.B25 (a_bus_08), J2.16, U1.25 (A8), U2.25 (A8), U3.25 (A8), U4.25 (A8), U5.25 (A8), U6.25 (A8), U7.25 (A8), U8.25 (A8), U9.25 (A8), U10.25 (A8), U11.25 (A8), U12.25 (A8), U13.25 (A8), U14.25 (A8), U15.25 (A8), U16.25 (A8), U25.18 (B0)
/a_bus_09: J1.B24 (a_bus_09), J2.15, U1.24 (A9), U2.24 (A9), U3.24 (A9), U4.24 (A9), U5.24 (A9), U6.24 (A9), U7.24 (A9), U8.24 (A9), U9.24 (A9), U10.24 (A9), U11.24 (A9), U12.24 (A9), U13.24 (A9), U14.24 (A9), U15.24 (A9), U16.24 (A9), U25.17 (B1)
/a_bus_10: J1.B23 (a_bus_10), J2.14, U1.21 (A10), U2.21 (A10), U3.21 (A10), U4.21 (A10), U5.21 (A10), U6.21 (A10), U7.21 (A10), U8.21 (A10), U9.21 (A10), U10.21 (A10), U11.21 (A10), U12.21 (A10), U13.21 (A10), U14.21 (A10), U15.21 (A10), U16.21 (A10), U25.16 (B2)
/a_bus_11: J1.B22 (a_bus_11), J2.13, U1.23 (A11), U2.23 (A11), U3.23 (A11), U4.23 (A11), U5.23 (A11), U6.23 (A11), U7.23 (A11), U8.23 (A11), U9.23 (A11), U10.23 (A11), U11.23 (A11), U12.23 (A11), U13.23 (A11), U14.23 (A11), U15.23 (A11), U16.23 (A11), U25.15 (B3)
/a_bus_12: J1.B21 (a_bus_12), J2.12, U1.2 (A12), U2.2 (A12), U3.2 (A12), U4.2 (A12), U5.2 (A12), U6.2 (A12), U7.2 (A12), U8.2 (A12), U9.2 (A12), U10.2 (A12), U11.2 (A12), U12.2 (A12), U13.2 (A12), U14.2 (A12), U15.2 (A12), U16.2 (A12), U25.14 (B4)
/a_bus_13: J1.B20 (a_bus_13), J2.11, U20.1, U20.3, U20.5, U20.9, U21.5, U22.2, U22.13, U23.10, U25.13 (B5)
/a_bus_14: J1.B19 (a_bus_14), J2.10, U19.2 (A0), U25.12 (B6)
/a_bus_15: J1.B18 (a_bus_15), J2.9, U19.3 (A1), U25.11 (B7)
/md_bus_00: J1.A17 (md_bus_00), U1.11 (I/O0), U3.11 (I/O0), U5.11 (DQ0), U7.11 (DQ0), U9.11 (DQ0), U11.11 (DQ0), U13.11 (DQ0), U15.11 (DQ0), U17.14 (D0), U26.18 (B0)
/md_bus_01: J1.A16 (md_bus_01), J3.24, U1.12 (I/O1), U3.12 (I/O1), U5.12 (DQ1), U7.12 (DQ1), U9.12 (DQ1), U11.12 (DQ1), U13.12 (DQ1), U15.12 (DQ1), U17.13 (D1), U26.17 (B1)
/md_bus_02: J1.A15 (md_bus_02), J3.23, U1.13 (I/O2), U3.13 (I/O2), U5.13 (DQ2), U7.13 (DQ2), U9.13 (DQ2), U11.13 (DQ2), U13.13 (DQ2), U15.13 (DQ2), U17.12 (D2), U26.16 (B2)
/md_bus_03: J1.A14 (md_bus_03), J3.22, U1.15 (I/O3), U3.15 (I/O3), U5.15 (DQ3), U7.15 (DQ3), U9.15 (DQ3), U11.15 (DQ3), U13.15 (DQ3), U15.15 (DQ3), U17.11 (D3), U26.15 (B3)
/md_bus_04: J1.A13 (md_bus_04), J3.21, U1.16 (I/O4), U3.16 (I/O4), U5.16 (DQ4), U7.16 (DQ4), U9.16 (DQ4), U11.16 (DQ4), U13.16 (DQ4), U15.16 (DQ4), U26.14 (B4)
/md_bus_05: J1.A12 (md_bus_05), J3.20, U1.17 (I/O5), U3.17 (I/O5), U5.17 (DQ5), U7.17 (DQ5), U9.17 (DQ5), U11.17 (DQ5), U13.17 (DQ5), U15.17 (DQ5), U26.13 (B5)
/md_bus_06: J1.A11 (md_bus_06), J3.19, U1.18 (I/O6), U3.18 (I/O6), U5.18 (DQ6), U7.18 (DQ6), U9.18 (DQ6), U11.18 (DQ6), U13.18 (DQ6), U15.18 (DQ6), U26.12 (B6)
/md_bus_07: J1.A10 (md_bus_07), J3.18, U1.19 (I/O7), U3.19 (I/O7), U5.19 (DQ7), U7.19 (DQ7), U9.19 (DQ7), U11.19 (DQ7), U13.19 (DQ7), U15.19 (DQ7), U26.11 (B7)
/md_bus_08: J1.A9 (md_bus_08), J3.17, U2.11 (I/O0), U4.11 (I/O0), U6.11 (DQ0), U8.11 (DQ0), U10.11 (DQ0), U12.11 (DQ0), U14.11 (DQ0), U16.11 (DQ0), U27.18 (B0)
/md_bus_09: J1.A8 (md_bus_09), J3.16, U2.12 (I/O1), U4.12 (I/O1), U6.12 (DQ1), U8.12 (DQ1), U10.12 (DQ1), U12.12 (DQ1), U14.12 (DQ1), U16.12 (DQ1), U27.17 (B1)
/md_bus_10: J1.A7 (md_bus_10), J3.15, U2.13 (I/O2), U4.13 (I/O2), U6.13 (DQ2), U8.13 (DQ2), U10.13 (DQ2), U12.13 (DQ2), U14.13 (DQ2), U16.13 (DQ2), U27.16 (B2)
/md_bus_11: J1.A6 (md_bus_11), J3.14, U2.15 (I/O3), U4.15 (I/O3), U6.15 (DQ3), U8.15 (DQ3), U10.15 (DQ3), U12.15 (DQ3), U14.15 (DQ3), U16.15 (DQ3), U27.15 (B3)
/md_bus_12: J1.A5 (md_bus_12), J3.13, U2.16 (I/O4), U4.16 (I/O4), U6.16 (DQ4), U8.16 (DQ4), U10.16 (DQ4), U12.16 (DQ4), U14.16 (DQ4), U16.16 (DQ4), U27.14 (B4)
/md_bus_13: J1.A4 (md_bus_13), J3.12, U2.17 (I/O5), U4.17 (I/O5), U6.17 (DQ5), U8.17 (DQ5), U10.17 (DQ5), U12.17 (DQ5), U14.17 (DQ5), U16.17 (DQ5), U27.13 (B5)
/md_bus_14: J1.A3 (md_bus_14), J3.11, U2.18 (I/O6), U4.18 (I/O6), U6.18 (DQ6), U8.18 (DQ6), U10.18 (DQ6), U12.18 (DQ6), U14.18 (DQ6), U16.18 (DQ6), U27.12 (B6)
/md_bus_15: J1.A2 (md_bus_15), J3.10, U2.19 (I/O7), U4.19 (I/O7), U6.19 (DQ7), U8.19 (DQ7), U10.19 (DQ7), U12.19 (DQ7), U14.19 (DQ7), U16.19 (DQ7), U27.11 (B7)
//bank_a_select: J1.B10 (control_07), J3.5, U19.4 (O0), U21.1
//bank_b_select: J3.4, U19.5 (O1), U22.1, U22.4
//bank_c_select: J2.4, U19.6 (O2), U22.9
//bank_d_select: J2.3, U19.7 (O3), U23.4
//enable_highbank_0: J3.9, U18.12 (O0), U22.10, U23.5
//enable_highbank_1: J3.8, U18.11 (O1)
//enable_highbank_2: J3.7, U18.10 (O2)
//enable_highbank_3: J3.6, U18.9 (O3)
//enable_lowbank_0: J2.8, U18.4 (O0), U21.2
//enable_lowbank_1: J1.B13 (control_04), J2.7, U18.5 (O1)
//enable_lowbank_2: J1.B12 (control_05), J2.6, U18.6 (O2)
//enable_lowbank_3: J1.B11 (control_06), J2.5, U18.7 (O3)
/~DBG: J1.B57 (DBG), U24.19 (CE), U25.19 (CE), U26.19 (CE), U27.19 (CE)
GND: C1.2, C2.2, C3.2, C4.2, C5.2, C6.2, C7.2, C8.2, C9.2, C10.2, C11.2, C12.2, C13.2, C14.2, C15.2, C16.2, C17.2, C18.2, C19.2, C20.2, C21.2, C22.2, C23.2, C24.2, C25.2, C26.2, C27.2, C41.2, C42.2, C43.2, C44.2, D1.1 (K), D2.1 (K), D3.1 (K), D4.1 (K), D5.1 (K), D6.1 (K), D7.1 (K), D8.1 (K), D9.1 (K), D10.1 (K), D11.1 (K), D12.1 (K), D13.1 (K), D14.1 (K), D15.1 (K), D16.1 (K), D17.1 (K), D18.1 (K), D19.1 (K), D20.1 (K), D21.1 (K), D22.1 (K), D23.1 (K), D24.1 (K), D25.1 (K), D26.1 (K), D27.1 (K), D28.1 (K), D29.1 (K), D30.1 (K), D31.1 (K), D32.1 (K), J1.A53 (GND), J1.A61 (GND), J1.B53 (GND), J1.B61 (GND), J2.1, J3.1, U1.14 (GND), U2.14 (GND), U3.14 (GND), U4.14 (GND), U5.14 (Vss), U6.14 (Vss), U7.14 (Vss), U8.14 (Vss), U9.14 (Vss), U10.14 (Vss), U11.14 (Vss), U12.14 (Vss), U13.14 (Vss), U14.14 (Vss), U15.14 (Vss), U16.14 (Vss), U17.1 (Oe1), U17.2 (Oe2), U17.8 (GND), U18.1 (E), U18.8 (GND), U18.15 (E), U19.8 (GND), U20.7 (GND), U21.7 (GND), U22.7 (GND), U23.7 (GND), U24.1 (A->B), U24.10 (GND), U25.1 (A->B), U25.10 (GND), U26.1 (A->B), U26.10 (GND), U27.1 (A->B), U27.10 (GND)
unnamed: D1.2 (A), RN1.1 (R1.1)
unnamed: D2.2 (A), RN1.2 (R2.1)
unnamed: D3.2 (A), RN1.3 (R3.1)
unnamed: D4.2 (A), RN1.4 (R4.1)
unnamed: D5.2 (A), RN1.5 (R5.1)
unnamed: D6.2 (A), RN1.6 (R6.1)
unnamed: D7.2 (A), RN1.7 (R7.1)
unnamed: D8.2 (A), RN1.8 (R8.1)
unnamed: D9.2 (A), RN2.1 (R1.1)
unnamed: D10.2 (A), RN2.2 (R2.1)
unnamed: D11.2 (A), RN2.3 (R3.1)
unnamed: D12.2 (A), RN2.4 (R4.1)
unnamed: D13.2 (A), RN2.5 (R5.1)
unnamed: D14.2 (A), RN2.6 (R6.1)
unnamed: D15.2 (A), RN2.7 (R7.1)
unnamed: D16.2 (A), RN2.8 (R8.1)
unnamed: D17.2 (A), RN3.1 (R1.1)
unnamed: D18.2 (A), RN3.2 (R2.1)
unnamed: D19.2 (A), RN3.3 (R3.1)
unnamed: D20.2 (A), RN3.4 (R4.1)
unnamed: D21.2 (A), RN3.5 (R5.1)
unnamed: D22.2 (A), RN3.6 (R6.1)
unnamed: D23.2 (A), RN3.7 (R7.1)
unnamed: D24.2 (A), RN3.8 (R8.1)
unnamed: D25.2 (A), RN4.1 (R1.1)
unnamed: D26.2 (A), RN4.2 (R2.1)
unnamed: D27.2 (A), RN4.3 (R3.1)
unnamed: D28.2 (A), RN4.4 (R4.1)
unnamed: D29.2 (A), RN4.5 (R5.1)
unnamed: D30.2 (A), RN4.6 (R6.1)
unnamed: D31.2 (A), RN4.7 (R7.1)
unnamed: D32.2 (A), RN4.8 (R8.1)
unnamed: RN1.9 (R8.2), U24.9 (A7)
unnamed: RN1.10 (R7.2), U24.8 (A6)
unnamed: RN1.11 (R6.2), U24.7 (A5)
unnamed: RN1.12 (R5.2), U24.6 (A4)
unnamed: RN1.13 (R4.2), U24.5 (A3)
unnamed: RN1.14 (R3.2), U24.4 (A2)
unnamed: RN1.15 (R2.2), U24.3 (A1)
unnamed: RN1.16 (R1.2), U24.2 (A0)
unnamed: RN2.9 (R8.2), U25.9 (A7)
unnamed: RN2.10 (R7.2), U25.8 (A6)
unnamed: RN2.11 (R6.2), U25.7 (A5)
unnamed: RN2.12 (R5.2), U25.6 (A4)
unnamed: RN2.13 (R4.2), U25.5 (A3)
unnamed: RN2.14 (R3.2), U25.4 (A2)
unnamed: RN2.15 (R2.2), U25.3 (A1)
unnamed: RN2.16 (R1.2), U25.2 (A0)
unnamed: RN3.9 (R8.2), U26.9 (A7)
unnamed: RN3.10 (R7.2), U26.8 (A6)
unnamed: RN3.11 (R6.2), U26.7 (A5)
unnamed: RN3.12 (R5.2), U26.6 (A4)
unnamed: RN3.13 (R4.2), U26.5 (A3)
unnamed: RN3.14 (R3.2), U26.4 (A2)
unnamed: RN3.15 (R2.2), U26.3 (A1)
unnamed: RN3.16 (R1.2), U26.2 (A0)
unnamed: RN4.9 (R8.2), U27.9 (A7)
unnamed: RN4.10 (R7.2), U27.8 (A6)
unnamed: RN4.11 (R6.2), U27.7 (A5)
unnamed: RN4.12 (R5.2), U27.6 (A4)
unnamed: RN4.13 (R4.2), U27.5 (A3)
unnamed: RN4.14 (R3.2), U27.4 (A2)
unnamed: RN4.15 (R2.2), U27.3 (A1)
unnamed: RN4.16 (R1.2), U27.2 (A0)
unnamed: U1.20 (~CE), U2.20 (~CE), U21.8
unnamed: U9.20 (~CE), U10.20 (~CE), U23.3
unnamed: U11.20 (~CE), U12.20 (~CE), U22.11
unnamed: U13.20 (~CE), U14.20 (~CE), U23.11
unnamed: U15.20 (~CE), U16.20 (~CE), U23.8
unnamed: U17.3 (Q0), U18.3 (A1)
unnamed: U17.4 (Q1), U18.2 (A0)
unnamed: U17.5 (Q2), U18.13 (A1)
unnamed: U17.6 (Q3), U18.14 (A0)
unnamed: U20.2, U21.10
unnamed: U20.4, U22.5
unnamed: U20.6, U23.2
unnamed: U20.8, U23.13
unnamed: U21.3, U21.4, U21.9
unnamed: U3.20 (~CE), U4.20 (~CE), U21.6
unnamed: U7.20 (~CE), U8.20 (~CE), U22.3
unnamed: U5.20 (~CE), U6.20 (~CE), U22.6
unnamed: U22.8, U22.12, U23.1
unnamed: U23.6, U23.9, U23.12

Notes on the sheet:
RAM D:0:0L
ROM A:0:1L
The top two address lines (A14, A15) select which 16 Kb bank is active. 00 - Bank A 01 - Bank B 10 - Bank C 11 - Bank D
The 64 Kb address space is split into four 16 Kb blocks (A, B, C, D). Blocks are further grouped into 32 Kb groups: the low block group (A & B) and high block group (C & D). Four banks are available to be selected for blocks A, C and D. Block B is static and can not be changed, that is where the st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
RAM D:0:1L
Bank Selection Decoding
ROM A:0:0L
ROM Bank A:0
RAM C:0:1L
RAM Bank C:0 (16 KB)
Bank Switching Decoding
RAM Bank D:0 (16 KB)
RAM C:0:0H
RAM B:0:1L
RAM B:0:0L
RAM D:0:0H
ROM A:0:0H
RAM C:0:0L
RAM Bank B:0 (16 KB)
TODO: * Validate RAM footprints are ok
16 Kb
Expansion Connectors
ROM A:0:1H
RAM B:0:0H

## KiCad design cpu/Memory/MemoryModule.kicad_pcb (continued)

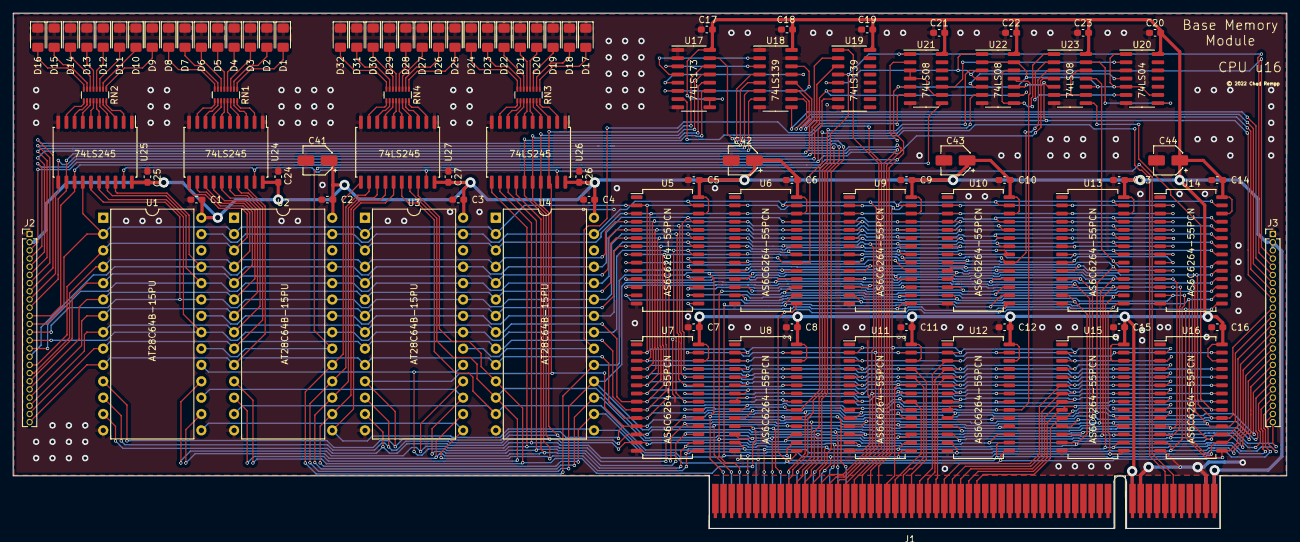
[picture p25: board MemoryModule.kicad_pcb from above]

Board: 2 copper layers, 197.8 x 80.0 mm, 97 parts (0 on the bottom side), 135 nets.

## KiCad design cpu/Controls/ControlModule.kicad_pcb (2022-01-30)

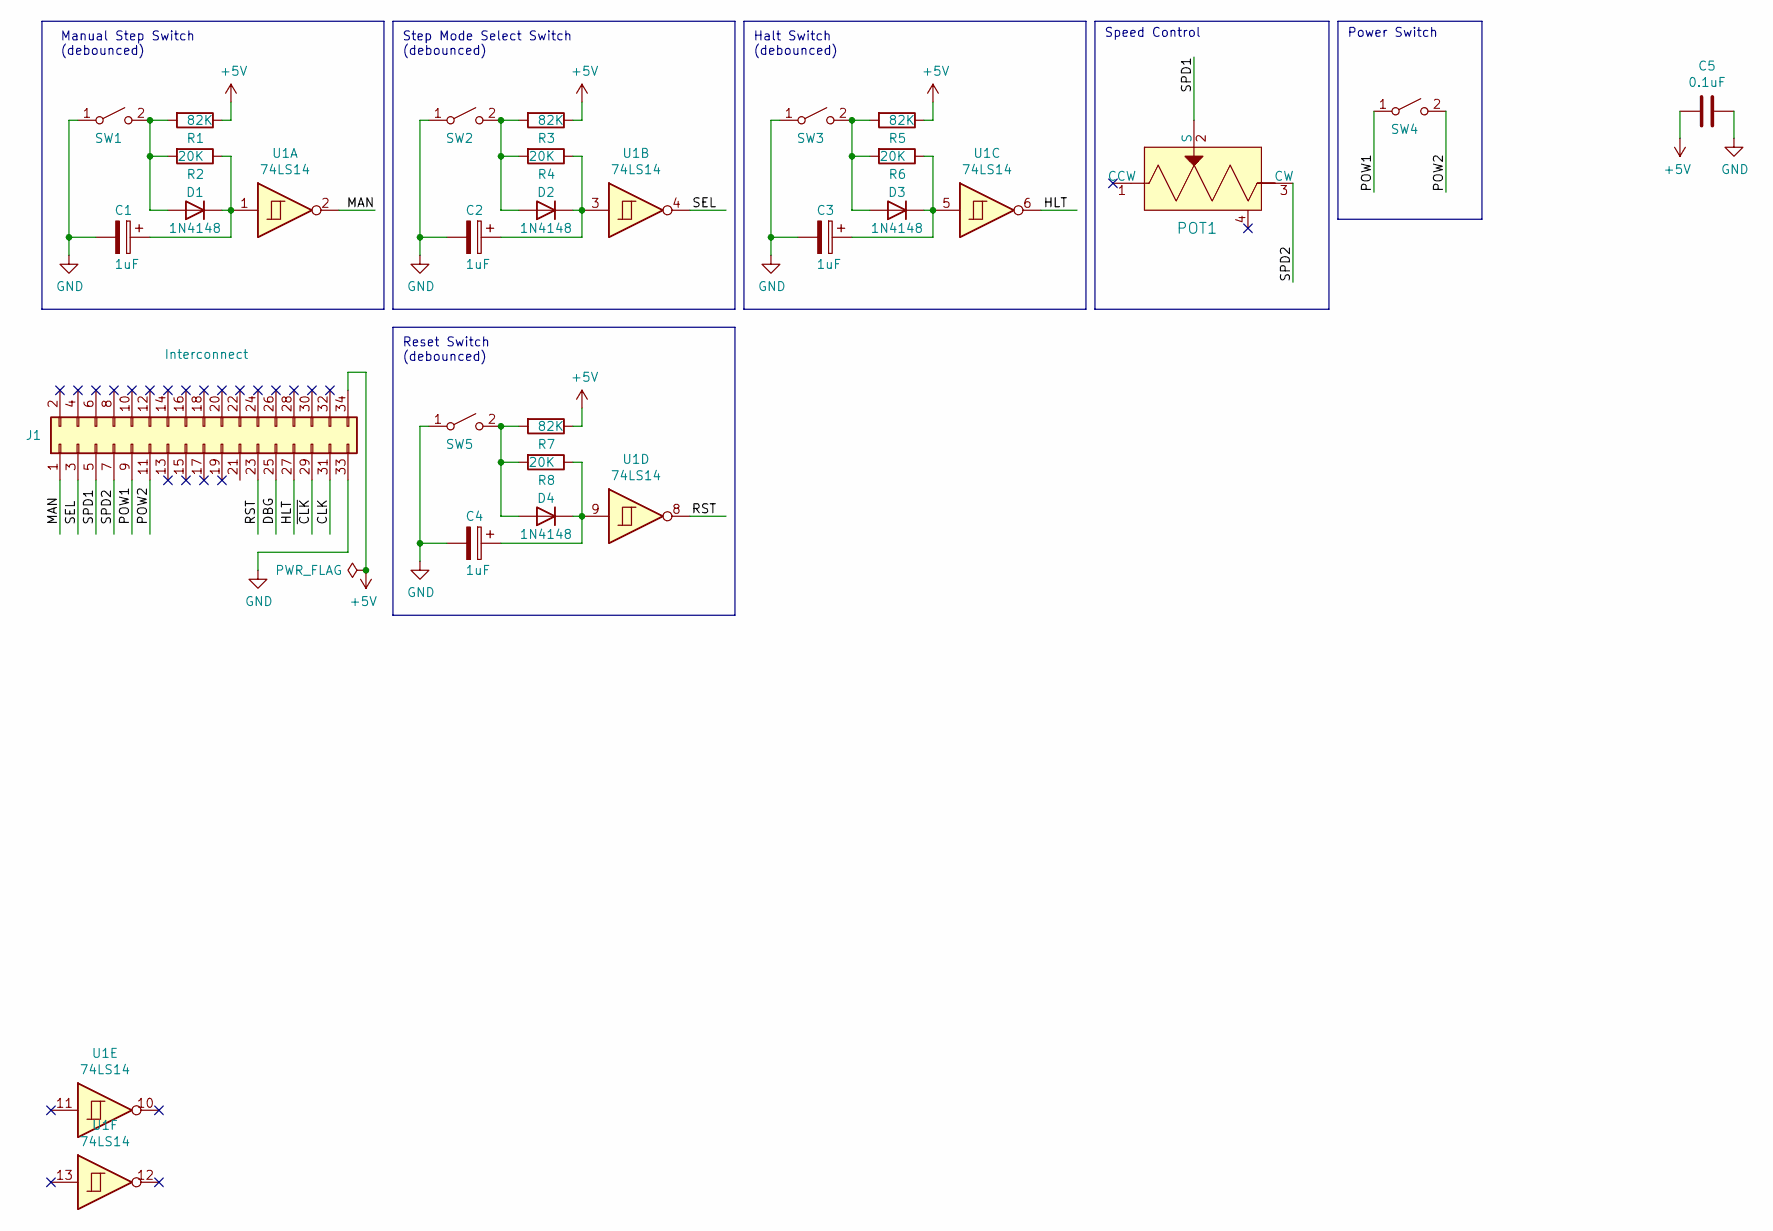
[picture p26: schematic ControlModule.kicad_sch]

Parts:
C1, C2, C3, C4: 1uF; CP_Elec_4x5.4; Digikey 493-9795-1-ND
C5: 0.1uF; C_0603_1608Metric_Pad1.05x0.95mm_HandSolder; Digikey 399-1096-1-ND
D1, D2, D3, D4: 1N4148; D_SOD-523; Digikey 1N4148XTPMSCT-ND
J1: Interconnect; PinHeader_2x17_P2.54mm_Horizontal; Digikey S5531-ND
POT1: P120PK-Y25BR10K; Potentiometer_P120PK-Y25BR10K; MPN P120PK-Y25BR10K; Digi-Key_PN 987-1710-ND
R1, R3, R5, R7: 82K; R_0603_1608Metric_Pad1.05x0.95mm_HandSolder; Digikey 311-82.0KHRCT-ND
R2, R4, R6, R8: 20K; R_0603_1608Metric_Pad1.05x0.95mm_HandSolder; Digikey 311-20.0KHRCT-ND
SW1, SW3, SW5: SW_SPST; SW_PUSH_6mm_H5mm; Digikey EG1861-ND
SW2, SW4: SW_SPST; SW_PUSH_6mm_H5mm; Digikey 401-1132-ND
U1: 74LS14; SOIC-14_3.9x8.7mm_P1.27mm; Digikey 296-14864-1-ND

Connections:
+5V: C5.2, J1.34, R1.1, R3.1, R5.1, R7.1
/CLK: J1.31
/DBG: J1.25
/HLT: J1.27, U1.6
/MAN: J1.1, U1.2
/POW1: J1.9, SW4.1 (A)
/POW2: J1.11, SW4.2 (B)
/RST: J1.23, U1.8
/SEL: J1.3, U1.4
/SPD1: J1.5, POT1.2 (S)
/SPD2: J1.7, POT1.3 (CW)
/~CLK: J1.29
GND: C1.2, C2.2, C3.2, C4.2, C5.1, J1.33, SW1.1 (A), SW2.1 (A), SW3.1 (A), SW5.1 (A)
unnamed: C1.1, D1.1 (K), R2.1, U1.1
unnamed: C2.1, D2.1 (K), R4.1, U1.3
unnamed: C3.1, D3.1 (K), R6.1, U1.5
unnamed: C4.1, D4.1 (K), R8.1, U1.9
unnamed: D1.2 (A), R1.2, R2.2, SW1.2 (B)
unnamed: D2.2 (A), R3.2, R4.2, SW2.2 (B)
unnamed: D3.2 (A), R5.2, R6.2, SW3.2 (B)
unnamed: D4.2 (A), R7.2, R8.2, SW5.2 (B)

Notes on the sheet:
Halt Switch (debounced)
Step Mode Select Switch (debounced)
Manual Step Switch (debounced)
Reset Switch (debounced)
Power Switch
Speed Control

Board: 2 copper layers, 25 parts (0 on the bottom side), 18 nets, no tracks yet.

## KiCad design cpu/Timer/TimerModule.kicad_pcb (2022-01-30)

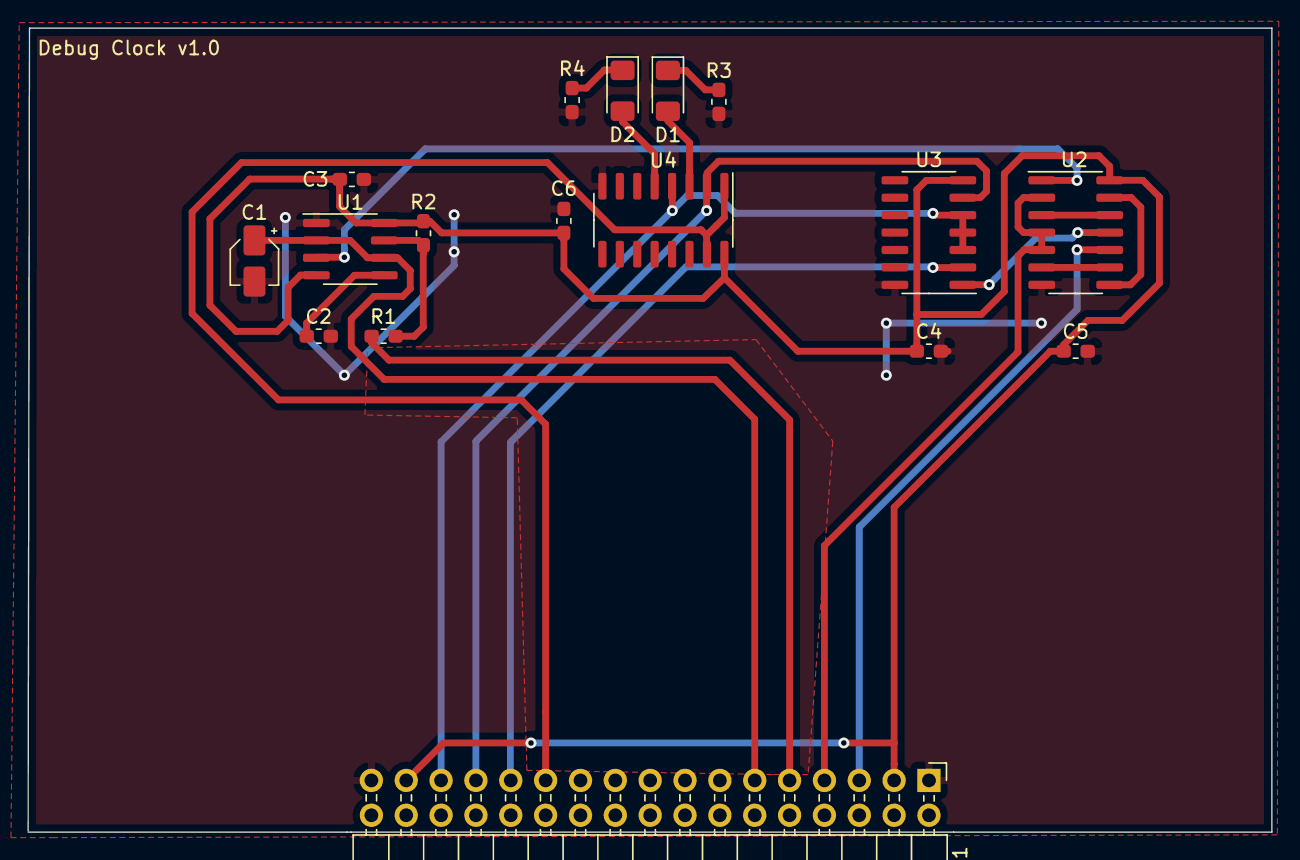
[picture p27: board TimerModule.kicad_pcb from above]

Board: 2 copper layers, 90.6 x 58.6 mm, 17 parts (0 on the bottom side), 21 nets.

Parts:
C1: 1uF; CP_Elec_3x5.4
C2: 0.01uF; C_0603_1608Metric_Pad1.05x0.95mm_HandSolder
C3, C4, C5, C6: 0.1uF; C_0603_1608Metric_Pad1.05x0.95mm_HandSolder
D1: ~{CLK}; LED_1206_3216Metric_Pad1.42x1.75mm_HandSolder
D2: CLK; LED_1206_3216Metric_Pad1.42x1.75mm_HandSolder
J1: Interconnect; PinHeader_2x17_P2.54mm_Horizontal
R1: 100R; R_0603_1608Metric_Pad1.05x0.95mm_HandSolder
R2: 1K; R_0603_1608Metric_Pad1.05x0.95mm_HandSolder
R3, R4: 220R; R_0603_1608Metric_Pad1.05x0.95mm_HandSolder
U1: LM555; SOIC-8_3.9x4.9mm_P1.27mm
U2, U3: 74LS00; SOIC-14_3.9x8.7mm_P1.27mm
U4: 74LS365; SOIC-16_3.9x9.9mm_P1.27mm

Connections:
+5V: C3.1, C4.1, C5.1, C6.1, J1.3, J1.31, R2.2, U1.4, U1.8, U2.14, U3.7, U4.16
CLK: J1.29, U3.3, U3.4, U3.5, U4.4
DBG: J1.23, U4.1, U4.15
GND: C1.2, C2.2, C3.2, C4.2, C5.2, C6.2, J1.1, J1.33, R3.1, R4.1, U1.1, U2.7, U3.14, U4.8
HLT: J1.25, U3.2
MAN: J1.5, U2.10
unnamed: C2.1, U1.5
unnamed: D1.1, R3.2
unnamed: D1.2, U4.3
unnamed: D2.1, R4.2
unnamed: D2.2, U4.5
unnamed: R1.2, R2.1, U1.7
unnamed: U1.3, U2.1
unnamed: U2.6, U2.9
unnamed: U2.11, U3.1
unnamed: U2.3, U2.12
unnamed: U2.8, U2.13
SEL: J1.7, U2.2, U2.4, U2.5
SPD1: J1.9, R1.1
SPD2: C1.1, J1.11, U1.2, U1.6
~CLK: J1.27, U3.6, U4.2

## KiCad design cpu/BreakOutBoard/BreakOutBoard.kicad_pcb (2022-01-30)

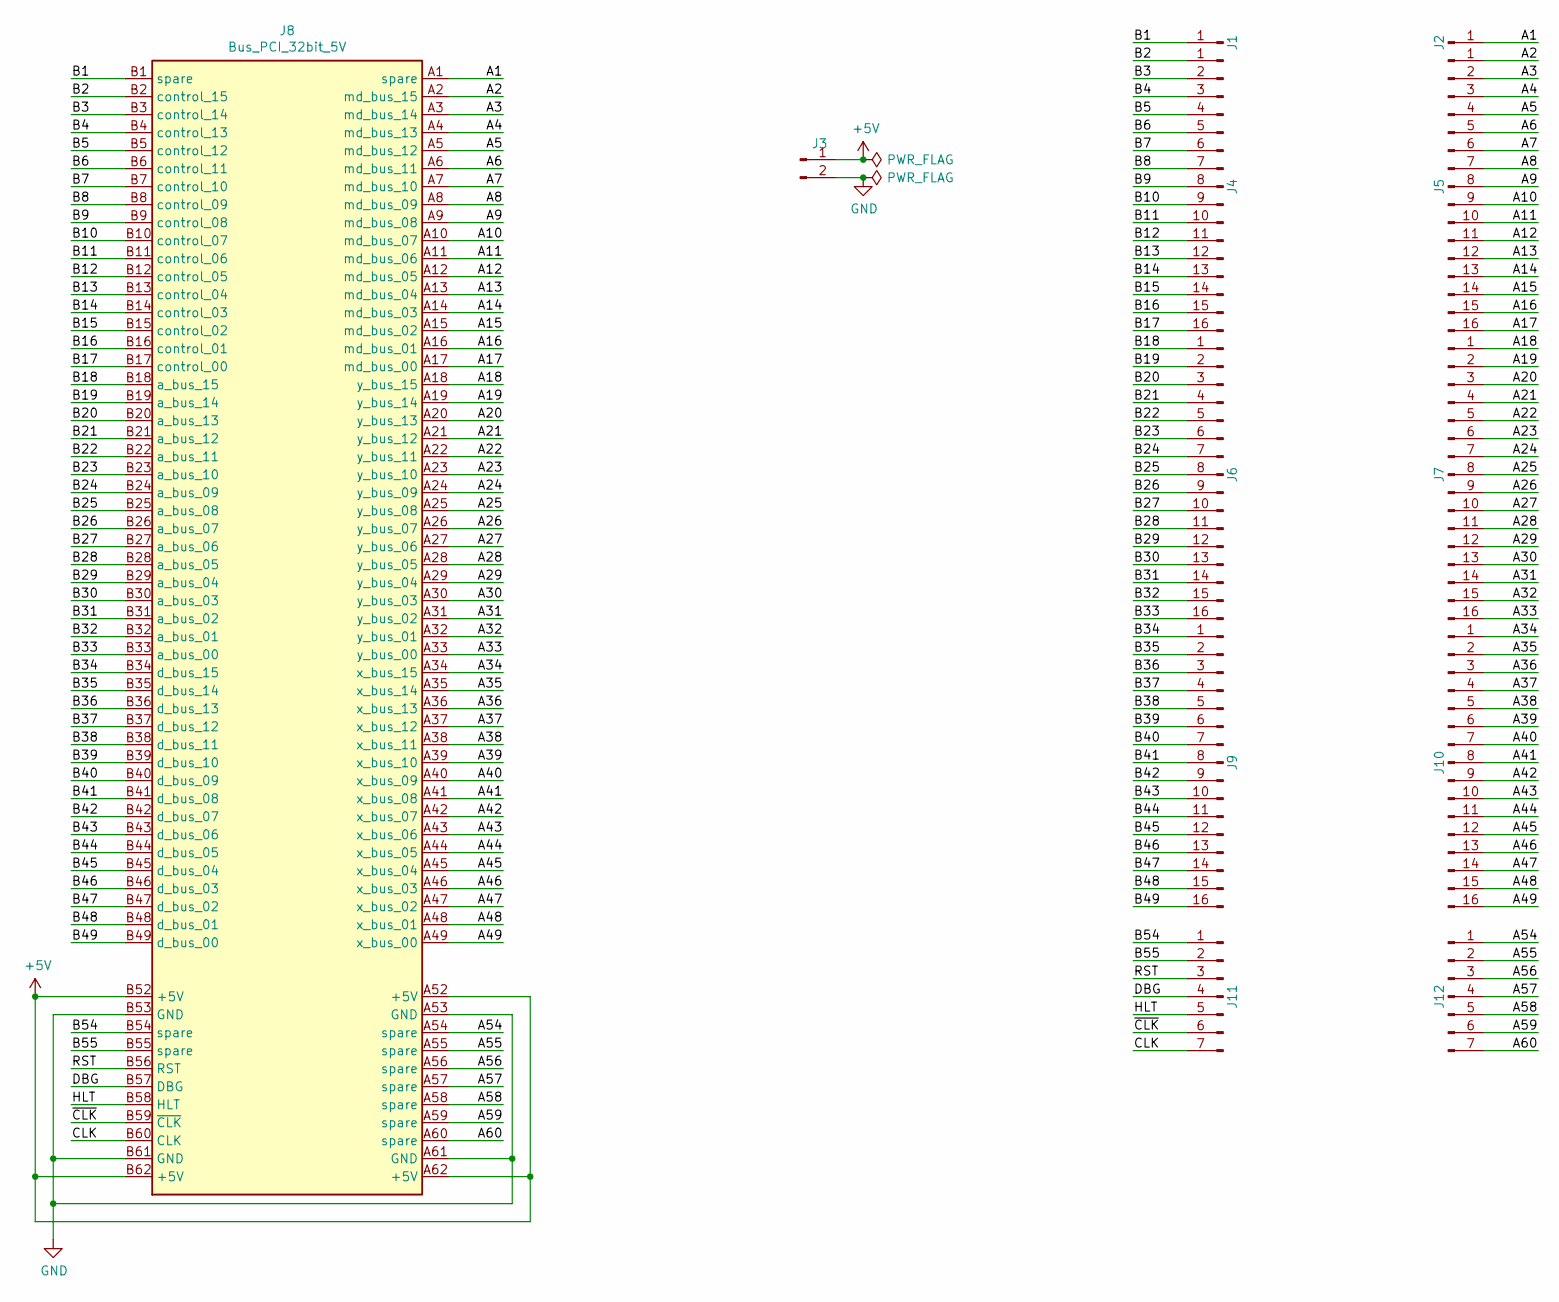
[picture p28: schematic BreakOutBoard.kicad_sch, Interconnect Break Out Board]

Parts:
J1, J2: Conn_01x01_Male; PinHeader_1x01_P2.54mm_Vertical
J3: Conn_01x02_Male; PinHeader_1x02_P2.54mm_Vertical
J4, J5, J6, J7, J9, J10: Conn_01x16_Male; PinHeader_1x16_P2.54mm_Vertical
J8: Bus_PCI_32bit_5V; TE_1-5145154-2
J11, J12: Conn_01x07_Male; PinHeader_1x07_P2.54mm_Vertical

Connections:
+5V: J3.1, J8.A52 (+5V), J8.A62 (+5V), J8.B52 (+5V), J8.B62 (+5V)
/A1: J2.1, J8.A1 (spare)
/A2: J5.1, J8.A2 (md_bus_15)
/A3: J5.2, J8.A3 (md_bus_14)
/A4: J5.3, J8.A4 (md_bus_13)
/A5: J5.4, J8.A5 (md_bus_12)
/A6: J5.5, J8.A6 (md_bus_11)
/A7: J5.6, J8.A7 (md_bus_10)
/A8: J5.7, J8.A8 (md_bus_09)
/A9: J5.8, J8.A9 (md_bus_08)
/A10: J5.9, J8.A10 (md_bus_07)
/A11: J5.10, J8.A11 (md_bus_06)
/A12: J5.11, J8.A12 (md_bus_05)
/A13: J5.12, J8.A13 (md_bus_04)
/A14: J5.13, J8.A14 (md_bus_03)
/A15: J5.14, J8.A15 (md_bus_02)
/A16: J5.15, J8.A16 (md_bus_01)
/A17: J5.16, J8.A17 (md_bus_00)
/A18: J7.1, J8.A18 (y_bus_15)
/A19: J7.2, J8.A19 (y_bus_14)
/A20: J7.3, J8.A20 (y_bus_13)
/A21: J7.4, J8.A21 (y_bus_12)
/A22: J7.5, J8.A22 (y_bus_11)
/A23: J7.6, J8.A23 (y_bus_10)
/A24: J7.7, J8.A24 (y_bus_09)
/A25: J7.8, J8.A25 (y_bus_08)
/A26: J7.9, J8.A26 (y_bus_07)
/A27: J7.10, J8.A27 (y_bus_06)
/A28: J7.11, J8.A28 (y_bus_05)
/A29: J7.12, J8.A29 (y_bus_04)
/A30: J7.13, J8.A30 (y_bus_03)
/A31: J7.14, J8.A31 (y_bus_02)
/A32: J7.15, J8.A32 (y_bus_01)
/A33: J7.16, J8.A33 (y_bus_00)
/A34: J8.A34 (x_bus_15), J10.1
/A35: J8.A35 (x_bus_14), J10.2
/A36: J8.A36 (x_bus_13), J10.3
/A37: J8.A37 (x_bus_12), J10.4
/A38: J8.A38 (x_bus_11), J10.5
/A39: J8.A39 (x_bus_10), J10.6
/A40: J8.A40 (x_bus_09), J10.7
/A41: J8.A41 (x_bus_08), J10.8
/A42: J8.A42 (x_bus_07), J10.9
/A43: J8.A43 (x_bus_06), J10.10
/A44: J8.A44 (x_bus_05), J10.11
/A45: J8.A45 (x_bus_04), J10.12
/A46: J8.A46 (x_bus_03), J10.13
/A47: J8.A47 (x_bus_02), J10.14
/A48: J8.A48 (x_bus_01), J10.15
/A49: J8.A49 (x_bus_00), J10.16
/A54: J8.A54 (spare), J12.1
/A55: J8.A55 (spare), J12.2
/A56: J8.A56 (spare), J12.3
/A57: J8.A57 (spare), J12.4
/A58: J8.A58 (spare), J12.5
/A59: J8.A59 (spare), J12.6
/A60: J8.A60 (spare), J12.7
/B1: J1.1, J8.B1 (spare)
/B2: J4.1, J8.B2 (control_15)
/B3: J4.2, J8.B3 (control_14)
/B4: J4.3, J8.B4 (control_13)
/B5: J4.4, J8.B5 (control_12)
/B6: J4.5, J8.B6 (control_11)
/B7: J4.6, J8.B7 (control_10)
/B8: J4.7, J8.B8 (control_09)
/B9: J4.8, J8.B9 (control_08)
/B10: J4.9, J8.B10 (control_07)
/B11: J4.10, J8.B11 (control_06)
/B12: J4.11, J8.B12 (control_05)
/B13: J4.12, J8.B13 (control_04)
/B14: J4.13, J8.B14 (control_03)
/B15: J4.14, J8.B15 (control_02)
/B16: J4.15, J8.B16 (control_01)
/B17: J4.16, J8.B17 (control_00)
/B18: J6.1, J8.B18 (a_bus_15)
/B19: J6.2, J8.B19 (a_bus_14)
/B20: J6.3, J8.B20 (a_bus_13)
/B21: J6.4, J8.B21 (a_bus_12)
/B22: J6.5, J8.B22 (a_bus_11)
/B23: J6.6, J8.B23 (a_bus_10)
/B24: J6.7, J8.B24 (a_bus_09)
/B25: J6.8, J8.B25 (a_bus_08)
/B26: J6.9, J8.B26 (a_bus_07)
/B27: J6.10, J8.B27 (a_bus_06)
/B28: J6.11, J8.B28 (a_bus_05)
/B29: J6.12, J8.B29 (a_bus_04)
/B30: J6.13, J8.B30 (a_bus_03)
/B31: J6.14, J8.B31 (a_bus_02)
/B32: J6.15, J8.B32 (a_bus_01)
/B33: J6.16, J8.B33 (a_bus_00)
/B34: J8.B34 (d_bus_15), J9.1
/B35: J8.B35 (d_bus_14), J9.2
/B36: J8.B36 (d_bus_13), J9.3
/B37: J8.B37 (d_bus_12), J9.4
/B38: J8.B38 (d_bus_11), J9.5
/B39: J8.B39 (d_bus_10), J9.6
/B40: J8.B40 (d_bus_09), J9.7
/B41: J8.B41 (d_bus_08), J9.8
/B42: J8.B42 (d_bus_07), J9.9
/B43: J8.B43 (d_bus_06), J9.10
/B44: J8.B44 (d_bus_05), J9.11
/B45: J8.B45 (d_bus_04), J9.12
/B46: J8.B46 (d_bus_03), J9.13
/B47: J8.B47 (d_bus_02), J9.14
/B48: J8.B48 (d_bus_01), J9.15
/B49: J8.B49 (d_bus_00), J9.16
/B54: J8.B54 (spare), J11.1
/B55: J8.B55 (spare), J11.2
/CLK: J8.B60 (CLK), J11.7
/DBG: J8.B57 (DBG), J11.4
/HLT: J8.B58 (HLT), J11.5
/RST: J8.B56 (RST), J11.3
/~CLK: J8.B59 (~CLK), J11.6
GND: J3.2, J8.A53 (GND), J8.A61 (GND), J8.B53 (GND), J8.B61 (GND)

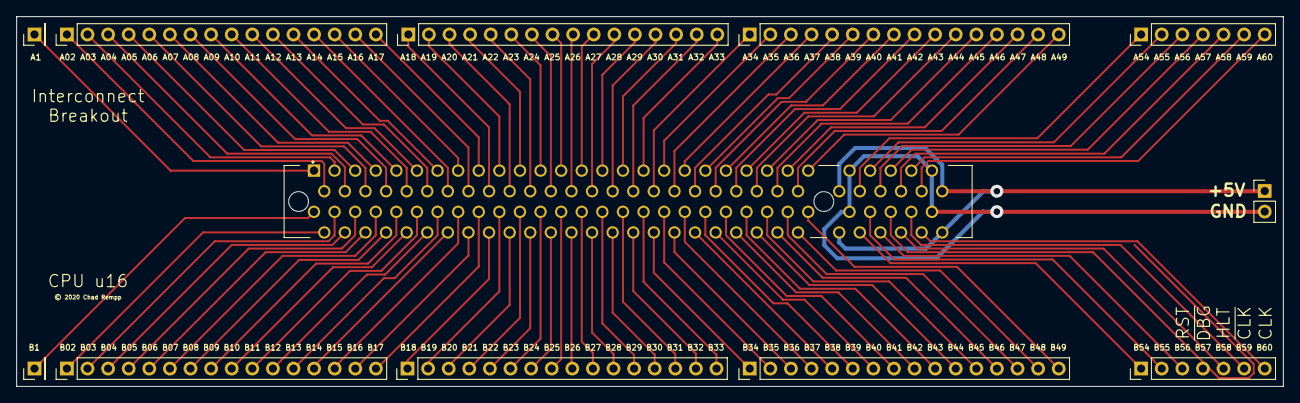
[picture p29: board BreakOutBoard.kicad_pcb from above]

Board: 2 copper layers, 156.2 x 45.6 mm, 12 parts (0 on the bottom side), 114 nets.

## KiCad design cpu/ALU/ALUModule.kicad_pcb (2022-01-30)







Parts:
C1, C2, C3, C4, C5, C6, C7, C8, C9, C10, C11, C12, C13, C14, C15, C16, C17, C18, C19, C20, C21, C22, C23, C24, C25, C26, C27, C28, C29, C30, C31, C32, C33, C34, C35, C36, C37, C38, C39, C40, C41, C42, C43, C44, C45, C46, C47: 0.1uF; C_0603_1608Metric_Pad1.05x0.95mm_HandSolder
D1, D2, D3, D4, D5, D6, D7, D8, D9, D10, D11, D12, D13, D14, D15, D16, D17, D18, D19, D20, D21, D22, D23, D24, D25, D26, D27, D28, D29, D30, D31, D32: LED_ALT; LED_1206_3216Metric_Pad1.42x1.75mm_HandSolder
D33: overflow; LED_1206_3216Metric_Pad1.42x1.75mm_HandSolder
D34: sign; LED_1206_3216Metric_Pad1.42x1.75mm_HandSolder
D35: arithmetic_carry; LED_1206_3216Metric_Pad1.42x1.75mm_HandSolder
D36: logical_carry; LED_1206_3216Metric_Pad1.42x1.75mm_HandSolder
D37: zero; LED_1206_3216Metric_Pad1.42x1.75mm_HandSolder
J1: Bus_PCI_32bit_5V; BUS_PCI
R1, R2, R3, R4, R5, R6, R7, R8, R9, R10, R11, R12, R13, R14, R15, R16, R17, R18, R19, R20, R21, R22, R23, R24, R25, R26, R27, R28, R29, R30, R31, R32, R33, R34, R35, R36, R37: 220R; R_0603_1608Metric_Pad1.05x0.95mm_HandSolder
TP1: GND; TestPoint_Pad_D1.5mm
TP2: +5; TestPoint_Pad_D1.5mm
TP3: FLG Overflow; TestPoint_Pad_D1.5mm
TP4: FLG Sign; TestPoint_Pad_D1.5mm
TP5: FLG ArithCarry; TestPoint_Pad_D1.5mm
TP6: FLG LogCarry; TestPoint_Pad_D1.5mm
TP7: FLG Zero; TestPoint_Pad_D1.5mm
TP8: RST; TestPoint_Pad_D1.5mm
TP9: DBG; TestPoint_Pad_D1.5mm
TP10: HLT; TestPoint_Pad_D1.5mm
TP11: ~CLK; TestPoint_Pad_D1.5mm
TP12: CLK; TestPoint_Pad_D1.5mm
U1, U2, U19, U20, U45, U46, U47: 74LS245; SOIC-20W_7.5x12.8mm_P1.27mm
U3, U4, U5, U6, U7, U8, U9, U10, U11, U12, U13, U14, U15, U16, U17, U18, U24, U25, U26, U27, U28, U29, U30, U31, U32, U44: 74LS253; SOIC-16_3.9x9.9mm_P1.27mm
U21, U33: 74LS02; SOIC-14_3.9x8.7mm_P1.27mm
U22, U23: 74LS08; SOIC-14_3.9x8.7mm_P1.27mm
U34: 74LS86; SOIC-14_3.9x8.7mm_P1.27mm
U35, U36, U37, U38: 74LS283; SOIC-16_3.9x9.9mm_P1.27mm
U39, U40, U41, U42, U43: 74LS574; SOIC-20W_7.5x12.8mm_P1.27mm

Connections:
+5V: C1.1, C2.1, C3.1, C4.1, C5.1, C6.1, C7.1, C8.1, C9.1, C10.1, C11.1, C12.1, C13.1, C14.1, C15.1, C16.1, C17.1, C18.1, C19.1, C20.1, C21.1, C22.1, C23.1, C24.1, C25.1, C26.1, C27.1, C28.1, C29.1, C30.1, C31.1, C32.1, C33.1, C34.1, C35.1, C36.1, C37.1, C38.1, C39.1, C40.1, C41.1, C42.1, C43.1, C44.1, C45.1, C46.1, C47.1, J1.A52 (+5V), J1.A62 (+5V), J1.B52 (+5V), J1.B62 (+5V), TP2.1, U1.1 (A->B), U1.20 (VCC), U2.1 (A->B), U2.20 (VCC), U3.15 (OEb), U3.16 (VCC), U4.15 (OEb), U4.16 (VCC), U5.15 (OEb), U5.16 (VCC), U6.15 (OEb), U6.16 (VCC), U7.15 (OEb), U7.16 (VCC), U8.15 (OEb), U8.16 (VCC), U9.15 (OEb), U9.16 (VCC), U10.15 (OEb), U10.16 (VCC), U11.15 (OEb), U11.16 (VCC), U12.15 (OEb), U12.16 (VCC), U13.15 (OEb), U13.16 (VCC), U14.15 (OEb), U14.16 (VCC), U15.15 (OEb), U15.16 (VCC), U16.15 (OEb), U16.16 (VCC), U17.15 (OEb), U17.16 (VCC), U18.15 (OEb), U18.16 (VCC), U19.1 (A->B), U19.20 (VCC), U20.1 (A->B), U20.20 (VCC), U21.14 (VCC), U22.14 (VCC)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
/CLK: J1.B60 (CLK), TP12.1, U39.11 (Cp), U40.11 (Cp), U41.11 (Cp), U42.11 (Cp), U43.11 (Cp)
/DBG: J1.B57 (DBG), TP9.1, U1.19 (CE), U2.19 (CE), U19.19 (CE), U20.19 (CE), U47.19 (CE)
/HLT: J1.B58 (HLT), TP10.1
/RST: J1.B56 (RST), TP8.1
/add_00: U21.2, U38.4 (S1), U46.2 (A0)
/add_01: U21.3, U38.1 (S2), U46.3 (A1)
/add_02: U21.5, U38.13 (S3), U46.4 (A2)
/add_03: U21.6, U38.10 (S4), U46.5 (A3)
/add_04: U21.8, U37.4 (S1), U46.6 (A4)
/add_05: U21.9, U37.1 (S2), U46.7 (A5)
/add_06: U21.11, U37.13 (S3), U46.8 (A6)
/add_07: U21.12, U37.10 (S4), U46.9 (A7)
/add_08: U33.2, U36.4 (S1), U45.2 (A0)
/add_09: U33.3, U36.1 (S2), U45.3 (A1)
/add_10: U33.5, U36.13 (S3), U45.4 (A2)
/add_11: U33.6, U36.10 (S4), U45.5 (A3)
/add_12: U33.8, U35.4 (S1), U45.6 (A4)
/add_13: U33.9, U35.1 (S2), U45.7 (A5)
/add_14: U33.11, U35.13 (S3), U45.8 (A6)
/add_15: J1.B13 (control_04), TP4.1, U33.12, U34.2, U34.4, U35.10 (S4), U45.9 (A7), U47.5 (A3)
/arithmetic_carry_flag: U43.18 (Q1), U44.11 (I1b), U47.2 (A0)
/arr_carry_in: U38.7 (C0), U44.9 (Zb)
/arr_carry_out: U35.9 (C4), U43.3 (D1)
/arr_carry_select_0: J1.B5 (control_12), U44.14 (A0)
/arr_carry_select_1: J1.B4 (control_13), U44.2 (A1)
/arrithmetic_carry_flag: J1.B14 (control_03), TP5.1
/bit_control_0: J1.B11 (control_06), U3.6 (I0a), U4.6 (I0a), U5.6 (I0a), U6.6 (I0a), U7.6 (I0a), U8.6 (I0a), U9.6 (I0a), U10.6 (I0a), U11.6 (I0a), U12.6 (I0a), U13.6 (I0a), U14.6 (I0a), U15.6 (I0a), U16.6 (I0a), U17.6 (I0a), U18.6 (I0a)
/bit_control_1: J1.B10 (control_07), U3.5 (I1a), U4.5 (I1a), U5.5 (I1a), U6.5 (I1a), U7.5 (I1a), U8.5 (I1a), U9.5 (I1a), U10.5 (I1a), U11.5 (I1a), U12.5 (I1a), U13.5 (I1a), U14.5 (I1a), U15.5 (I1a), U16.5 (I1a), U17.5 (I1a), U18.5 (I1a)
/bit_control_2: J1.B9 (control_08), U3.4 (I2a), U4.4 (I2a), U5.4 (I2a), U6.4 (I2a), U7.4 (I2a), U8.4 (I2a), U9.4 (I2a), U10.4 (I2a), U11.4 (I2a), U12.4 (I2a), U13.4 (I2a), U14.4 (I2a), U15.4 (I2a), U16.4 (I2a), U17.4 (I2a), U18.4 (I2a)
/bit_control_3: J1.B8 (control_09), U3.3 (I3a), U4.3 (I3a), U5.3 (I3a), U6.3 (I3a), U7.3 (I3a), U8.3 (I3a), U9.3 (I3a), U10.3 (I3a), U11.3 (I3a), U12.3 (I3a), U13.3 (I3a), U14.3 (I3a), U15.3 (I3a), U16.3 (I3a), U17.3 (I3a), U18.3 (I3a)
/d_bus_00: J1.B49 (d_bus_00), U46.18 (B0)
/d_bus_01: J1.B48 (d_bus_01), U46.17 (B1)
/d_bus_02: J1.B47 (d_bus_02), U46.16 (B2)
/d_bus_03: J1.B46 (d_bus_03), U46.15 (B3)
/d_bus_04: J1.B45 (d_bus_04), U46.14 (B4)
/d_bus_05: J1.B44 (d_bus_05), U46.13 (B5)
/d_bus_06: J1.B43 (d_bus_06), U46.12 (B6)
/d_bus_07: J1.B42 (d_bus_07), U46.11 (B7)
/d_bus_08: J1.B41 (d_bus_08), U45.18 (B0)
/d_bus_09: J1.B40 (d_bus_09), U45.17 (B1)
/d_bus_10: J1.B39 (d_bus_10), U45.16 (B2)
/d_bus_11: J1.B38 (d_bus_11), U45.15 (B3)
/d_bus_12: J1.B37 (d_bus_12), U45.14 (B4)
/d_bus_13: J1.B36 (d_bus_13), U45.13 (B5)
/d_bus_14: J1.B35 (d_bus_14), U45.12 (B6)
/d_bus_15: J1.B34 (d_bus_15), U45.11 (B7)
/d_bus_write: J1.B17 (control_00), U45.19 (CE), U46.19 (CE)
/lgc_carry_held: U24.12 (I2b), U31.5 (I1a), U43.19 (Q0)
/logical_00: U18.7 (Za), U42.2 (D0)
/logical_01: U17.7 (Za), U42.3 (D1)
/logical_02: U16.7 (Za), U42.4 (D2)
/logical_03: U15.7 (Za), U42.5 (D3)
/logical_04: U14.7 (Za), U42.6 (D4)
/logical_05: U13.7 (Za), U42.7 (D5)
/logical_06: U12.7 (Za), U42.8 (D6)
/logical_07: U11.7 (Za), U42.9 (D7)
/logical_08: U10.7 (Za), U41.2 (D0)
/logical_09: U9.7 (Za), U41.3 (D1)
/logical_10: U8.7 (Za), U41.4 (D2)
/logical_11: U7.7 (Za), U41.5 (D3)
/logical_12: U6.7 (Za), U41.6 (D4)
/logical_13: U5.7 (Za), U41.7 (D5)
/logical_14: U4.7 (Za), U41.8 (D6)
/logical_15: U3.7 (Za), U41.9 (D7)
/logical_carry_flag: J1.B15 (control_02), TP6.1, U32.9 (Zb), U43.2 (D0), U47.3 (A1)
/overflow_flag: J1.B12 (control_05), TP3.1, U23.11, U47.4 (A2)
/shift_00: U24.9 (Zb), U40.2 (D0)
/shift_01: U24.7 (Za), U40.3 (D1)
/shift_02: U25.9 (Zb), U40.4 (D2)
/shift_03: U25.7 (Za), U40.5 (D3)
/shift_04: U26.9 (Zb), U40.6 (D4)
/shift_05: U26.7 (Za), U40.7 (D5)
/shift_06: U27.9 (Zb), U40.8 (D6)
/shift_07: U27.7 (Za), U40.9 (D7)
/shift_08: U28.9 (Zb), U39.2 (D0)
/shift_09: U28.7 (Za), U39.3 (D1)
/shift_10: U29.9 (Zb), U39.4 (D2)
/shift_11: U29.7 (Za), U39.5 (D3)
/shift_12: U30.9 (Zb), U39.6 (D4)
/shift_13: U30.7 (Za), U39.7 (D5)
/shift_14: U31.9 (Zb), U39.8 (D6)
/shift_15: U31.7 (Za), U39.9 (D7)
/shift_control_0: J1.B7 (control_10), U24.14 (A0), U25.14 (A0), U26.14 (A0), U27.14 (A0), U28.14 (A0), U29.14 (A0), U30.14 (A0), U31.14 (A0), U32.14 (A0)
/shift_control_1: J1.B6 (control_11), U24.2 (A1), U25.2 (A1), U26.2 (A1), U27.2 (A1), U28.2 (A1), U29.2 (A1), U30.2 (A1), U31.2 (A1), U32.2 (A1)
/x_bus_00: J1.A49 (x_bus_00), U1.2 (A0), U18.14 (A0), U24.4 (I2a), U24.10 (I0b), U32.11 (I1b)
/x_bus_01: J1.A48 (x_bus_01), U1.3 (A1), U17.14 (A0), U24.6 (I0a), U24.11 (I1b), U25.12 (I2b)
/x_bus_02: J1.A47 (x_bus_02), U1.4 (A2), U16.2 (A1), U24.5 (I1a), U25.4 (I2a), U25.10 (I0b)
/x_bus_03: J1.A46 (x_bus_03), U1.5 (A3), U15.2 (A1), U25.6 (I0a), U25.11 (I1b), U26.12 (I2b)
/x_bus_04: J1.A45 (x_bus_04), U1.6 (A4), U14.2 (A1), U25.5 (I1a), U26.4 (I2a), U26.10 (I0b)
/x_bus_05: J1.A44 (x_bus_05), U1.7 (A5), U13.2 (A1), U26.6 (I0a), U26.11 (I1b), U27.12 (I2b)
/x_bus_06: J1.A43 (x_bus_06), U1.8 (A6), U12.2 (A1), U26.5 (I1a), U27.4 (I2a), U27.10 (I0b)
/x_bus_07: J1.A42 (x_bus_07), U1.9 (A7), U11.2 (A1), U27.6 (I0a), U27.11 (I1b), U28.12 (I2b)
/x_bus_08: J1.A41 (x_bus_08), U10.2 (A1), U19.2 (A0), U27.5 (I1a), U28.4 (I2a), U28.10 (I0b)
/x_bus_09: J1.A40 (x_bus_09), U9.2 (A1), U19.3 (A1), U28.6 (I0a), U28.11 (I1b), U29.12 (I2b)
/x_bus_10: J1.A39 (x_bus_10), U8.2 (A1), U19.4 (A2), U28.5 (I1a), U29.4 (I2a), U29.10 (I0b)
/x_bus_11: J1.A38 (x_bus_11), U7.2 (A1), U19.5 (A3), U29.6 (I0a), U29.11 (I1b), U30.12 (I2b)
/x_bus_12: J1.A37 (x_bus_12), U6.14 (A0), U19.6 (A4), U29.5 (I1a), U30.4 (I2a), U30.10 (I0b)
/x_bus_13: J1.A36 (x_bus_13), U5.2 (A1), U19.7 (A5), U30.6 (I0a), U30.11 (I1b), U31.12 (I2b)
/x_bus_14: J1.A35 (x_bus_14), U4.2 (A1), U19.8 (A6), U30.5 (I1a), U31.4 (I2a), U31.10 (I0b)
/x_bus_15: J1.A34 (x_bus_15), U3.14 (A0), U19.9 (A7), U31.6 (I0a), U31.11 (I1b), U32.12 (I2b)
/x_latched_00: U38.5 (A1), U40.19 (Q0)
/x_latched_01: U38.3 (A2), U40.18 (Q1)
/x_latched_02: U38.14 (A3), U40.17 (Q2)
/x_latched_03: U38.12 (A4), U40.16 (Q3)
/x_latched_04: U37.5 (A1), U40.15 (Q4)
/x_latched_05: U37.3 (A2), U40.14 (Q5)
/x_latched_06: U37.14 (A3), U40.13 (Q6)
/x_latched_07: U37.12 (A4), U40.12 (Q7)
/x_latched_08: U36.5 (A1), U39.19 (Q0)
/x_latched_09: U36.3 (A2), U39.18 (Q1)
/x_latched_10: U36.14 (A3), U39.17 (Q2)
/x_latched_11: U36.12 (A4), U39.16 (Q3)
/x_latched_12: U35.5 (A1), U39.15 (Q4)
/x_latched_13: U35.3 (A2), U39.14 (Q5)
/x_latched_14: U35.14 (A3), U39.13 (Q6)
/x_latched_15: U34.1, U35.12 (A4), U39.12 (Q7)
/y_bus_00: J1.A33 (y_bus_00), U2.2 (A0), U18.2 (A1)
/y_bus_01: J1.A32 (y_bus_01), U2.3 (A1), U17.2 (A1)
/y_bus_02: J1.A31 (y_bus_02), U2.4 (A2), U16.14 (A0)
/y_bus_03: J1.A30 (y_bus_03), U2.5 (A3), U15.14 (A0)
/y_bus_04: J1.A29 (y_bus_04), U2.6 (A4), U14.14 (A0)
/y_bus_05: J1.A28 (y_bus_05), U2.7 (A5), U13.14 (A0)
/y_bus_06: J1.A27 (y_bus_06), U2.8 (A6), U12.14 (A0)
/y_bus_07: J1.A26 (y_bus_07), U2.9 (A7), U11.14 (A0)
/y_bus_08: J1.A25 (y_bus_08), U10.14 (A0), U20.2 (A0)
/y_bus_09: J1.A24 (y_bus_09), U9.14 (A0), U20.3 (A1)
/y_bus_10: J1.A23 (y_bus_10), U8.14 (A0), U20.4 (A2)
/y_bus_11: J1.A22 (y_bus_11), U7.14 (A0), U20.5 (A3)
/y_bus_12: J1.A21 (y_bus_12), U6.2 (A1), U20.6 (A4)
/y_bus_13: J1.A20 (y_bus_13), U5.14 (A0), U20.7 (A5)
/y_bus_14: J1.A19 (y_bus_14), U4.14 (A0), U20.8 (A6)
/y_bus_15: J1.A18 (y_bus_15), U3.2 (A1), U20.9 (A7)
/y_latched_00: U38.6 (B1), U42.19 (Q0)
/y_latched_01: U38.2 (B2), U42.18 (Q1)
/y_latched_02: U38.15 (B3), U42.17 (Q2)
/y_latched_03: U38.11 (B4), U42.16 (Q3)
/y_latched_04: U37.6 (B1), U42.15 (Q4)
/y_latched_05: U37.2 (B2), U42.14 (Q5)
/y_latched_06: U37.15 (B3), U42.13 (Q6)
/y_latched_07: U37.11 (B4), U42.12 (Q7)
/y_latched_08: U36.6 (B1), U41.19 (Q0)
/y_latched_09: U36.2 (B2), U41.18 (Q1)
/y_latched_10: U36.15 (B3), U41.17 (Q2)
/y_latched_11: U36.11 (B4), U41.16 (Q3)
/y_latched_12: U35.6 (B1), U41.15 (Q4)
/y_latched_13: U35.2 (B2), U41.14 (Q5)
/y_latched_14: U35.15 (B3), U41.13 (Q6)
/y_latched_15: U34.5, U35.11 (B4), U41.12 (Q7)
/zero_flag: J1.B16 (control_01), TP7.1, U22.8, U47.6 (A4)
/~CLK: J1.B59 (~CLK), TP11.1
GND: C1.2, C2.2, C3.2, C4.2, C5.2, C6.2, C7.2, C8.2, C9.2, C10.2, C11.2, C12.2, C13.2, C14.2, C15.2, C16.2, C17.2, C18.2, C19.2, C20.2, C21.2, C22.2, C23.2, C24.2, C25.2, C26.2, C27.2, C28.2, C29.2, C30.2, C31.2, C32.2, C33.2, C34.2, C35.2, C36.2, C37.2, C38.2, C39.2, C40.2, C41.2, C42.2, C43.2, C44.2, C45.2, C46.2, C47.2, D1.1 (K), D2.1 (K), D3.1 (K), D4.1 (K), D5.1 (K), D6.1 (K), D7.1 (K), D8.1 (K), D9.1 (K), D10.1 (K), D11.1 (K), D12.1 (K), D13.1 (K), D14.1 (K), D15.1 (K), D16.1 (K), D17.1 (K), D18.1 (K), D19.1 (K), D20.1 (K), D21.1 (K), D22.1 (K), D23.1 (K), D24.1 (K), D25.1 (K), D26.1 (K), D27.1 (K), D28.1 (K), D29.1 (K), D30.1 (K), D31.1 (K), D32.1 (K), D33.1 (K), D34.1 (K), D35.1 (K), D36.1 (K), D37.1 (K), J1.A53 (GND), J1.A61 (GND), J1.B53 (GND), J1.B61 (GND), TP1.1, U1.10 (GND), U2.10 (GND), U3.1 (OEa), U3.8 (GND), U4.1 (OEa)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
unnamed: D1.2 (A), R1.2
unnamed: D2.2 (A), R2.2
unnamed: D3.2 (A), R3.2
unnamed: D4.2 (A), R4.2
unnamed: D5.2 (A), R5.2
unnamed: D6.2 (A), R6.2
unnamed: D7.2 (A), R7.2
unnamed: D8.2 (A), R8.2
unnamed: D9.2 (A), R9.2
unnamed: D10.2 (A), R10.2
unnamed: D11.2 (A), R11.2
unnamed: D12.2 (A), R12.2
unnamed: D13.2 (A), R13.2
unnamed: D14.2 (A), R14.2
unnamed: D15.2 (A), R15.2
unnamed: D16.2 (A), R16.2
unnamed: D17.2 (A), R17.2
unnamed: D18.2 (A), R18.2
unnamed: D19.2 (A), R19.2
unnamed: D20.2 (A), R20.2
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

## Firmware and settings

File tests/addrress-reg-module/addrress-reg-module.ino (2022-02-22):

/* Address Register Module Test 
 *  
 *  Tests:
 *    - Write values 0x0000 through 0xFFFF to register via the DBUS, read them back through the DBUS and validate.
 *    - Write values 0x0000 through 0xFFFF to register via the DBUS, read them back through the ABUS and validate.
 *    - Write values 0x0000 to register via the DBUS, increment repeatedly to 0xFFFF and validate by reading through the DBUS.
 *    - Write values 0xFFFF to register via the DBUS, increment repeatedly to 0x0000 and validate by reading through the DBUS.
 *    - Carry/borrow
 *    - Reset
 *    
 *  Testing instructions:
 *   Connect address bus
 *     ABUS:    15 14 13 12 11 10 09 08 07 06 05 04 03 02 01 00
 *     ARDUINO: 23 25 27 29 31 33 35 37 39 41 43 45 47 49 51 53
 *   Connect data bus
 *     DBUS:    15 14 13 12 11 10 09 08 07 06 05 04 03 02 01 00
 *     ARDUINO: 22 24 26 28 30 32 34 36 38 40 42 44 46 48 50 52
 *   Connect control lines
 *     CLOCK        2
 *     D_BUS_READ   3
 *     D_BUS_WRITE  4
 *     A_BUS_WRITE  5
 *     REG_INC      6
 *     REG_DEC      7
 *     REG_CARRY    8
 *     REG_BORROW   9
*/

// Settings
#define CONTROL_PULSE 0 // milliseconds
#define PRINT 1         // Print to serial (1) else (0)

// Bus pin definitions
byte abus[] = {23, 25, 27, 29, 31, 33, 35, 37, 39, 41, 43, 45, 47, 49, 51, 53};
byte dbus [] = {22, 24, 26, 28, 30, 32, 34, 36, 38, 40, 42, 44, 46, 48, 50, 52};

// Control pin definitions
#define CLOCK 2
#define D_BUS_READ 3
#define D_BUS_WRITE 4
#define A_BUS_WRITE 5
#define REG_INC 6
#define REG_DEC 7
#define REG_CARRY 8
#define REG_BORROW 9
#define RESET 10

unsigned int loop_count = 1;
unsigned int error_count = 0;

void bus_pin_mode(byte bus[], byte mode) {
  for (int i = 0; i < 16; i++) {
    pinMode(bus[i], mode);
  }
}

void set_bus_value(byte bus[], int value) {
  unsigned int mask = 1;
  for (int i = 0; i < 16; i++) {
    byte binValue = value & mask;
    digitalWrite(bus[i], binValue);
    value = value >> 1;
  }
}

unsigned int read_bus_value(byte bus[]) {
  unsigned int value = 0;
  for (unsigned int i = 0; i < 16; i++) {
    // Use left shift for power of 2
    value += digitalRead(bus[i]) * (1 << i);
  }
  return value;
}

void setup() {
  // Enable serial
  Serial.begin(9600);
  delay(1000);
  
  // Setup pins
  pinMode(CLOCK, OUTPUT);
  pinMode(D_BUS_READ, OUTPUT);
  pinMode(D_BUS_WRITE, OUTPUT);
  pinMode(A_BUS_WRITE, OUTPUT);
  pinMode(REG_INC, OUTPUT);
  pinMode(REG_DEC, OUTPUT);
  pinMode(REG_CARRY, INPUT);
  pinMode(REG_BORROW, INPUT);
  pinMode(RESET, OUTPUT);
  bus_pin_mode(abus, OUTPUT);
  bus_pin_mode(dbus, INPUT);

  // Initialize control lines
  digitalWrite(CLOCK, LOW);
  digitalWrite(D_BUS_READ, LOW);
  digitalWrite(D_BUS_WRITE, LOW);
  digitalWrite(REG_INC, HIGH);
  digitalWrite(REG_DEC, HIGH);
  digitalWrite(RESET, LOW);
}

/**
 * This tests writing values to the data bus, setting the register to that value and writing
 * the register value back to the databus
 */
unsigned int test_dbus_read_write() {
  unsigned int error_count = 0;
  if (PRINT) Serial.print("Testing DBUS read/write..."); Serial.println();
  
  for(unsigned long i = 0; i <= 0xFFFF; i++) {
    // Set the value of `i` to the DBUS and read it into the register
    bus_pin_mode(dbus, OUTPUT);
    // Assert value to DBUS
    set_bus_value(dbus, i);
    // Pulse the clock and d_bus_read line high
    digitalWrite(CLOCK, HIGH);
    digitalWrite(D_BUS_READ, HIGH);
    if (CONTROL_PULSE != 0) delay(CONTROL_PULSE);
    digitalWrite(CLOCK, LOW);
    digitalWrite(D_BUS_READ, LOW);
    // reset the DBUS back to zero to avoid false positives
    set_bus_value(dbus, 0x0000);
    
    // Read the value from the register to the DBUS
    bus_pin_mode(dbus, INPUT);
    // Pulse the clock and d_bus_write line high
    digitalWrite(CLOCK, HIGH);
    digitalWrite(D_BUS_WRITE, HIGH);
    // Read the value on the DBUS
    unsigned int value = read_bus_value(dbus);
    if (CONTROL_PULSE != 0) delay(CONTROL_PULSE);
    digitalWrite(CLOCK, LOW);
    digitalWrite(D_BUS_WRITE, LOW);

    // Check if the values match
    if (value != i) {
      error_count++;
      if (PRINT) Serial.print("  ERROR: expected "); Serial.print(i); Serial.print(", received "); Serial.print(value); Serial.println();
    }
    
    if (PRINT && (i % (0xFFFF / 10)) == 0) {
      float completion = ((float)i / (float)0xFFFF) * 100.0f;
      Serial.print("  "); Serial.print(completion); Serial.print("%"); Serial.println();
    }
  }

  return error_count;
}

/**
 * This tests writing values to the register through the data bus and readting that value back through the
 * address bus.
 */
unsigned int test_abus_read() {
  unsigned int error_count = 0;
  if (PRINT) Serial.print("Testing ABUS read..."); Serial.println();
  
  for(unsigned long i = 0; i <= 0xFFFF; i++) {
    // Set the value of `i` to the DBUS and read it into the register
    bus_pin_mode(dbus, OUTPUT);
    // Assert value to DBUS
    set_bus_value(dbus, i);
    // Pulse the clock and d_bus_read line high
    digitalWrite(CLOCK, HIGH);
    digitalWrite(D_BUS_READ, HIGH);
    if (CONTROL_PULSE != 0) delay(CONTROL_PULSE);
    digitalWrite(CLOCK, LOW);
    digitalWrite(D_BUS_READ, LOW);
    // reset the DBUS back to zero to avoid false positives
    set_bus_value(dbus, 0x0000);
    
    // Read the value from the register to the ABUS
    bus_pin_mode(abus, INPUT);
    // Pulse the clock and a_bus_write line high
    digitalWrite(CLOCK, HIGH);
    digitalWrite(A_BUS_WRITE, HIGH);
    // Read the value on the ABUS
    unsigned int value = read_bus_value(abus);
    if (CONTROL_PULSE != 0) delay(CONTROL_PULSE);
    digitalWrite(CLOCK, LOW);
    digitalWrite(A_BUS_WRITE, LOW);

    // Check if the values match
    if (value != i) {
      error_count++;
      if (PRINT) Serial.print("  ERROR: expected "); Serial.print(i); Serial.print(", received "); Serial.print(value); Serial.println();
    }

    if (PRINT && (i % (0xFFFF / 10)) == 0) {
      float completion = ((float)i / (float)0xFFFF) * 100.0f;
      Serial.print("  "); Serial.print(completion); Serial.print("%"); Serial.println();
    }
  }

  return error_count;
}

unsigned int test_increment() {
  unsigned int error_count = 0;
  if (PRINT) Serial.print("Testing increment..."); Serial.println();

  // Set the value of 0x0000 to the DBUS and read it into the register
  bus_pin_mode(dbus, OUTPUT);
  // Assert value to DBUS
  set_bus_value(dbus, 0x0000);
  // Pulse the clock and d_bus_read line high
  digitalWrite(CLOCK, HIGH);
  digitalWrite(D_BUS_READ, HIGH);
  if (CONTROL_PULSE != 0) delay(CONTROL_PULSE);
  digitalWrite(CLOCK, LOW);
  digitalWrite(D_BUS_READ, LOW);
  // reset the DBUS back to zero to avoid false positives
  set_bus_value(dbus, 0x0000);
  // From now on we'll be reading from DBUS
  bus_pin_mode(dbus, INPUT);
  
  for(unsigned long i = 1; i <= 0xFFFF; i++) {
    digitalWrite(CLOCK, LOW);
    digitalWrite(REG_INC, LOW);
    if (CONTROL_PULSE != 0) delay(CONTROL_PULSE);
    digitalWrite(CLOCK, HIGH);
    digitalWrite(REG_INC, HIGH);

    // Read the value from the register to the DBUS
    // Pulse the clock and d_bus_write line high
    digitalWrite(CLOCK, HIGH);
    digitalWrite(D_BUS_WRITE, HIGH);
    // Read the value on the DBUS
    unsigned int value = read_bus_value(dbus);
    if (CONTROL_PULSE != 0) delay(CONTROL_PULSE);
    digitalWrite(CLOCK, LOW);
    digitalWrite(D_BUS_WRITE, LOW);

    // Check if the values match
    if (value != i) {
      error_count++;
      if (PRINT) Serial.print("  ERROR: expected "); Serial.print(i); Serial.print(", received "); Serial.print(value); Serial.println();
    }

    if (PRINT && (i % (0xFFFF / 10)) == 0) {
      float completion = ((float)i / (float)0xFFFF) * 100.0f;
      Serial.print("  "); Serial.print(completion); Serial.print("%"); Serial.println();
    }
  }

  return error_count;
}

unsigned int test_decrement() {
  unsigned int error_count = 0;
  if (PRINT) Serial.print("Testing decrement..."); Serial.println();

  // Set the value of 0xFFFF to the DBUS and read it into the register
  bus_pin_mode(dbus, OUTPUT);
  // Assert value to DBUS
  set_bus_value(dbus, 0xFFFF);
  // Pulse the clock and d_bus_read line high
  digitalWrite(CLOCK, HIGH);
  digitalWrite(D_BUS_READ, HIGH);
  if (CONTROL_PULSE != 0) delay(CONTROL_PULSE);
  digitalWrite(CLOCK, LOW);
  digitalWrite(D_BUS_READ, LOW);
  // reset the DBUS back to zero to avoid false positives
  set_bus_value(dbus, 0x0000);
  // From now on we'll be reading from DBUS
  bus_pin_mode(dbus, INPUT);

  // TODO: Does this actually hit 0?
  for(unsigned int i = 0xFFFE; i > 0x0000; --i) {
    digitalWrite(CLOCK, LOW);
    digitalWrite(REG_DEC, LOW);
    if (CONTROL_PULSE != 0) delay(CONTROL_PULSE);
    digitalWrite(CLOCK, HIGH);
    digitalWrite(REG_DEC, HIGH);

    // Read the value from the register to the DBUS
    // Pulse the clock and d_bus_write line high
    digitalWrite(CLOCK, HIGH);
    digitalWrite(D_BUS_WRITE, HIGH);
    // Read the value on the DBUS
    unsigned int value = read_bus_value(dbus);
    if (CONTROL_PULSE != 0) delay(CONTROL_PULSE);
    digitalWrite(CLOCK, LOW);
    digitalWrite(D_BUS_WRITE, LOW);

    // Check if the values match
    if (value != i) {
      error_count++;
      if (PRINT) Serial.print("  ERROR: expected "); Serial.print(i); Serial.print(", received "); Serial.print(value); Serial.println();
    }

    if (PRINT && (i % (0xFFFF / 10)) == 0) {
      float completion = 100.0f - ((float)i / (float)0xFFFF) * 100.0f;
      Serial.print("  "); Serial.print(completion); Serial.print("%"); Serial.println();
    }
  }
  return error_count;
}

unsigned int test_carry_borrow() {
  unsigned int error_count = 0;
  if (PRINT) Serial.print("Testing carry/borrow..."); Serial.println();
  unsigned char carry_value;
  
  // Set the value of 0xFFFF to the DBUS and read it into the register
  bus_pin_mode(dbus, OUTPUT);
  // Assert value to DBUS
  set_bus_value(dbus, 0xFFFF);
  // Pulse the clock and d_bus_read line high
  digitalWrite(CLOCK, HIGH);
  digitalWrite(D_BUS_READ, HIGH);
  if (CONTROL_PULSE != 0) delay(CONTROL_PULSE);
  digitalWrite(CLOCK, LOW);
  digitalWrite(D_BUS_READ, LOW);
  // reset the DBUS back to zero to avoid false positives
  set_bus_value(dbus, 0x0000);
  // From now on we'll be reading from DBUS
  bus_pin_mode(dbus, INPUT);

  // Increment by 1, will overflow and set the carry control line LOW (active)
  digitalWrite(CLOCK, LOW);
  digitalWrite(REG_INC, LOW);
  if (CONTROL_PULSE != 0) delay(CONTROL_PULSE);
  digitalWrite(CLOCK, HIGH);
  digitalWrite(REG_INC, HIGH);

  // Check that carry (active low) is set
  carry_value = digitalRead(REG_CARRY);
  if (carry_value != LOW) {
    error_count++;
    if (PRINT) Serial.print("  1 ERROR: expected carry to be LOW (has carry), received HIGH"); Serial.println();
  }

  // Increment by 1, will no longer overflow and set the carry control line HIGH (inactive)
  digitalWrite(CLOCK, LOW);
  digitalWrite(REG_INC, LOW);
  if (CONTROL_PULSE != 0) delay(CONTROL_PULSE);
  digitalWrite(CLOCK, HIGH);
  digitalWrite(REG_INC, HIGH);

  // Check that carry (active low) is not set
  carry_value = digitalRead(REG_CARRY);
  if (carry_value != HIGH) {
    error_count++;
    if (PRINT) Serial.print("  2 ERROR: expected carry to be HIGH (no carry), received LOW"); Serial.println();
  }

  // Set the value of 0x0000 to the DBUS and read it into the register
  bus_pin_mode(dbus, OUTPUT);
  // Assert value to DBUS
  set_bus_value(dbus, 0x0000);
  // Pulse the clock and d_bus_read line high
  digitalWrite(CLOCK, HIGH);
  digitalWrite(D_BUS_READ, HIGH);
  if (CONTROL_PULSE != 0) delay(CONTROL_PULSE);
  digitalWrite(CLOCK, LOW);
  digitalWrite(D_BUS_READ, LOW);
  // reset the DBUS back to zero to avoid false positives
  set_bus_value(dbus, 0x0000);
  // From now on we'll be reading from DBUS
  bus_pin_mode(dbus, INPUT);

  // Decrement by 1, will underflow and set the borrow control line LOW (active)
  digitalWrite(CLOCK, LOW);
  digitalWrite(REG_DEC, LOW);
  if (CONTROL_PULSE != 0) delay(CONTROL_PULSE);
  digitalWrite(CLOCK, HIGH);
  digitalWrite(REG_DEC, HIGH);

  // Check that borrow (active low) is set
  carry_value = digitalRead(REG_BORROW);
  if (carry_value != LOW) {
    error_count++;
    if (PRINT) Serial.print("  3 ERROR: expected borrow to be LOW (has borrow), received HIGH"); Serial.println();
  }

  // Decrement by 1, will no longer underflow and set the borrow control line HIGH (inactive)
  digitalWrite(CLOCK, LOW);
  digitalWrite(REG_DEC, LOW);
  if (CONTROL_PULSE != 0) delay(CONTROL_PULSE);
  digitalWrite(CLOCK, HIGH);
  digitalWrite(REG_DEC, HIGH);

  // Check that borrow (active low) is not set
  carry_value = digitalRead(REG_BORROW);
  if (carry_value != HIGH) {
    error_count++;
    if (PRINT) Serial.print("  4 ERROR: expected borrow to be HIGH (no borrow), received LOW"); Serial.println();
  }

  return error_count;
}

unsigned int test_reset() {
  unsigned int error_count = 0;
  if (PRINT) Serial.print("Testing reset..."); Serial.println();

  // Set the value of 0xFFFF to the DBUS and read it into the register
  bus_pin_mode(dbus, OUTPUT);
  // Assert value to DBUS
  set_bus_value(dbus, 0xFFFF);
  // Pulse the clock and d_bus_read line high
  digitalWrite(CLOCK, HIGH);
  digitalWrite(D_BUS_READ, HIGH);
  if (CONTROL_PULSE != 0) delay(CONTROL_PULSE);
  digitalWrite(CLOCK, LOW);
  digitalWrite(D_BUS_READ, LOW);
  // reset the DBUS back to zero to avoid false positives
  set_bus_value(dbus, 0x0000);
  // From now on we'll be reading from DBUS
  bus_pin_mode(dbus, INPUT);

  // Reset
  digitalWrite(RESET, HIGH);
  if (CONTROL_PULSE != 0) delay(CONTROL_PULSE);
  digitalWrite(REG_DEC, LOW);

  // Read the value from the register to the DBUS
  // Pulse the clock and d_bus_write line high
  digitalWrite(CLOCK, HIGH);
  digitalWrite(D_BUS_WRITE, HIGH);
  // Read the value on the DBUS
  unsigned int value = read_bus_value(dbus);
  if (CONTROL_PULSE != 0) delay(CONTROL_PULSE);
  digitalWrite(CLOCK, LOW);
  digitalWrite(D_BUS_WRITE, LOW);

  // Check that 
  if (value != 0) {
    error_count++;
    if (PRINT) Serial.print("  ERROR: expected register to be 0x000 after reset, received "); Serial.print(value); Serial.println();
  }

  return error_count;
}

void loop() {
  if (PRINT) Serial.print("TEST LOOP "); Serial.print(loop_count); Serial.println();
  error_count += test_dbus_read_write();
  error_count += test_abus_read();
  error_count += test_increment();
  error_count += test_decrement();
  error_count += test_carry_borrow();
  error_count += test_reset();

  delay(1000);

  if (PRINT) Serial.print("Found "); Serial.print(error_count); Serial.print(" errors"); Serial.println();
  loop_count++;
}

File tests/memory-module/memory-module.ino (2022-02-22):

byte abus[] = {23, 25, 27, 29, 31, 33, 35, 37, 39, 41, 43, 45, 47, 49, 51, 53}
byte mdbus [] = {22, 24, 26, 28, 30, 32, 34, 36, 38, 40, 42, 44, 46, 48, 50, 52}

void setup() {
  // put your setup code here, to run once:
  pinMode(LED, OUTPUT);
}

void loop() {
  // put your main code here, to run repeatedly:
  digitalWrite(LED, HIGH);
  delay(500);
  digitalWrite(LED, LOW);
  delay(500);
}

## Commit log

2020-04-23 Initial Commit: GPR and timer v1 complete
    [Backplane.sch, ControlModule.kicad_pcb, ControlModule.sch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]
2020-06-23 Lots of changes
    [ALUModule.sch, Backplane.kicad_pcb, Backplane.sch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]
2020-07-16 Completed initial version of ALU. Created blank memory schematic.
    [ALUModule.sch, MemoryModule.sch]
2020-07-17 Part 1 of Bus Control (DBUS read/write)
    [BusControlModule.sch, PipelineModule.sch]
2020-08-17 ALU and constant register first version
    [ALUModule.sch, ConstantRegisterModule.sch, GPRModule.kicad_pcb]
2020-08-24 Update ALU schematic with D_BUS connection, added test points.
    [ALUModule.sch]
2020-08-24 Working on ALU PCB
    [ALUModule.kicad_pcb, ALUModule.sch]
2020-08-28 Finished a draft of the ALU PCB
    [ALUModule.kicad_pcb, ALUModule.sch]
2020-11-28 Completed GPR 1.2 PCB and started lots of other things. * Started ALU * Updated Constant Reg * Completed v1.2 GPR * Added random symbols * Updated Memory * Updated plots
    [ALUModule.sch, ConstantRegisterModule.sch, CounterRegisterModule.kicad_pcb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]
2020-11-28 Added missing power pins to GPR
    [Backplane.kicad_pcb, Backplane.sch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]
2020-11-28 Added 10uF caps to GPR
    [GPRModule-B_CrtYd.gbr, GPRModule-B_Cu.gbr, GPRModule-B_Fab.gbr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]
2020-12-01 Interconnect Breakout Board
    [BreakOutBoard-B_Cu.gbr, BreakOutBoard-B_Fab.gbr, BreakOutBoard-B_Mask.gbr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]
2020-12-01 GPR final production version 1.2
    [GPRModule-B_CrtYd.gbr, GPRModule-B_Cu.gbr, GPRModule-B_Fab.gbr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]
2020-12-26 Fixed errors on GPR after testing board. * writing too small * stat LEDs not aligned * stat buffer needed CE to be active low - swapped 126 for a 125 * x_bus was backwards on the interconnect
    [GPRModule.kicad_pcb, GPRModule.sch]
2021-01-16 V1.3 of GPR (fixed issues from first production board)
    [GPRModule-B_CrtYd.gbr, GPRModule-B_Cu.gbr, GPRModule-B_Fab.gbr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]
2021-01-24 Finished Address Register 1.0
    [AddressRegisterModule-B_CrtYd.gbr, AddressRegisterModule-B_Cu.gbr, AddressRegisterModule-B_Fab.gbr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]
2022-01-11 Finishing touches on GPR and Address Register
    [AddressRegisterModule-B_Cu.gbl, AddressRegisterModule-B_Fab.gbr, AddressRegisterModule-B_Mask.gbs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]
2022-01-30 Upgrade to KiCad 6 and commit a bunch of random stuff
    [ALUModule.kicad_pcb, ALUModule.kicad_sch, AddressRegisterModule.kicad_pcb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]
2022-02-05 Moved documentation to Hugo
    [Backplane.kicad_sch]
2022-02-09 Memory module v2.0 schematic
    [MemoryModule.kicad_sch]
2022-02-12 Started memory pcb layout
    [MemoryModule.kicad_pcb, MemoryModule.kicad_sch]
2022-02-14 Finished a draft of mem pcb
    [MemoryModule.kicad_pcb]
2022-02-20 Mem module fixes
    [MemoryModule.kicad_pcb, MemoryModule.kicad_sch]
2022-02-22 Wrote Arduino tests for Address Register
2022-02-22 GPR v1.4, removed old src, deleted a BOM
    [GPRModule.kicad_pcb, GPRModule.kicad_sch]
2022-02-26 Address Register v1.3
    [AddressRegisterModule.kicad_pcb, AddressRegisterModule.kicad_sch, AddressRegisterModule.sch]
2022-02-26 GPR 1.4, smaller traces and fixed connections being backwards
    [GPRModule.kicad_pcb]
2022-02-26 Started mini backplane
    [Backplane.kicad_pcb, Backplane.kicad_sch, Backplane.sch]
2022-02-26 Started gocc assembler

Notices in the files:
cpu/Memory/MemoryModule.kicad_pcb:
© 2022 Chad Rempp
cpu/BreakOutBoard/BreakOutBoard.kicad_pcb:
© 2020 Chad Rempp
